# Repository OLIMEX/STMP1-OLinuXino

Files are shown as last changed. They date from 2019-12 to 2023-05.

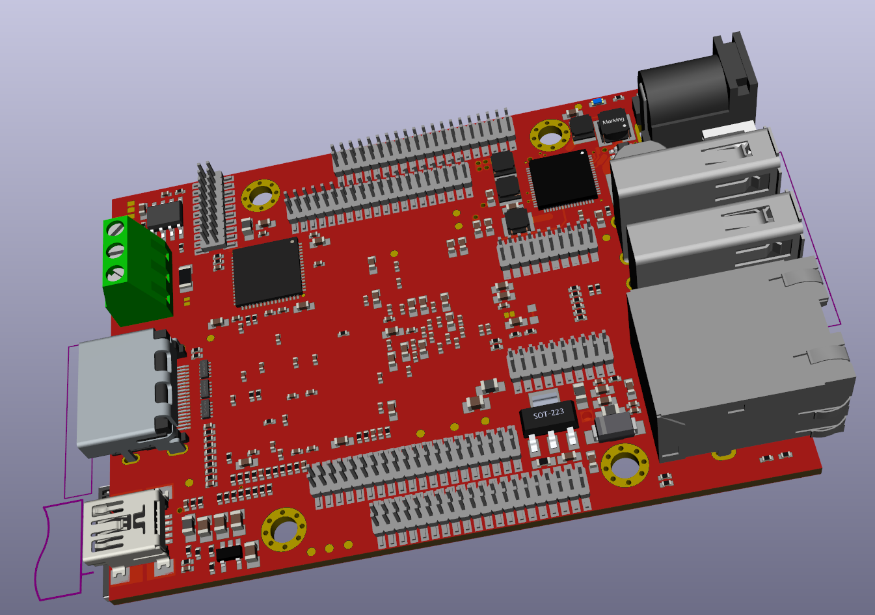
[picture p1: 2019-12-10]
HARDWARE/Screenshot from 2019-12-10 08-06-22.png

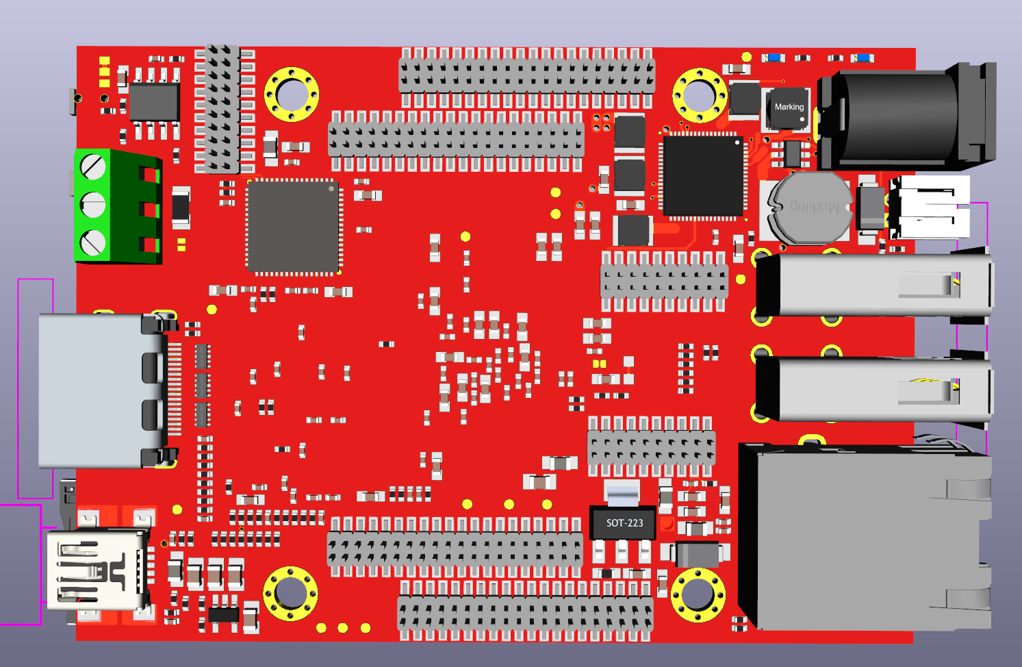
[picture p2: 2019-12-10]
HARDWARE/Screenshot from 2019-12-10 08-05-45.png

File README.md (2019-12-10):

# STMP1-OLinuXino

STMP1 (es-ti-em-pai) OLinuXino (o-linux-ino) is based on STM32MP1XX Dual Core Cortex-A7 + Cortex-M4 microprocessors from ST Microelectronics. The Cortex-A7 can run Linux/Android OS while Cortex-M4 handle Real-Time events.

Features are:

- mainline Linux support
- automotive -40+125C operating temperature on all devices!
- 1GB DDR3L
- Gigabit Ethernet interface
- Three USB 2.0
- Two FD-CAN
- Two ADC
- Two DAC
- Camera IF
- Six I2C
- Three I2S
- Three SD MMC
- FMC (NAND) Flash
- Six SPI
- Four UART
- MIPI DSI 3Gb (157 only)
- Secure Boot
- Crypto Hash (C version only)

STMP1-OLinuXino is designed in the same size and connector locations as A20-OLinuXino-LIME2 so being replacable and pin to pin compatible. 

STMP1-OLinuXino is manufactured in -40+125C operating temperature and targets industrial applications.

# License
- Hardware is with CERN OHL v1.2 license
- Software is with GPLv3 license
- Documentation is with CC BY-SA 4.0 license

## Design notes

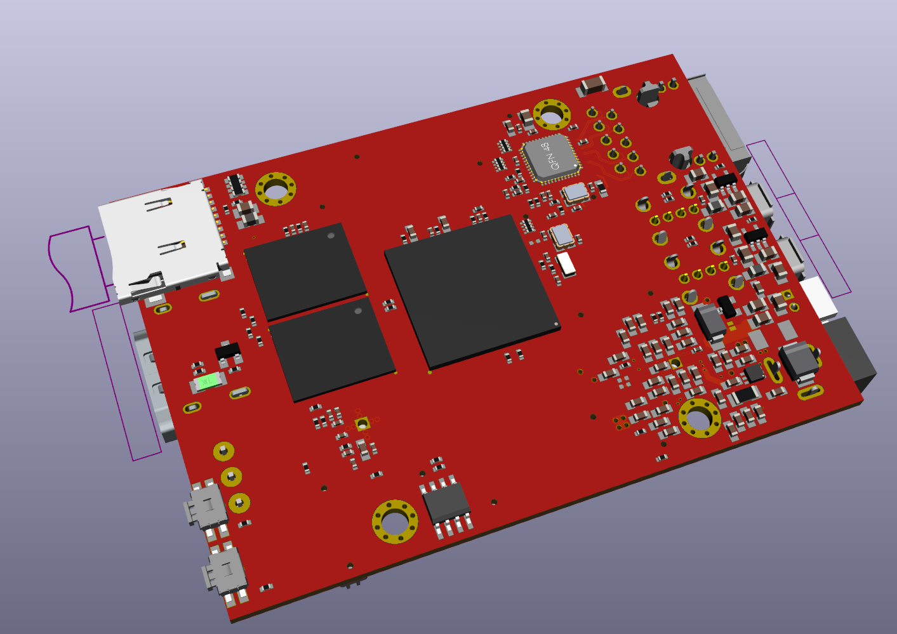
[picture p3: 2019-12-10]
HARDWARE/Screenshot from 2019-12-10 08-06-47.png

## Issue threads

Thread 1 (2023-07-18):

Track are not displayed (routed) in KiCad 5.1.12

hilt0n, 2023-07-18:
I open the project in KiCad 5.1.12 and the tracks are not there, only few on layer 1. Is the PCB normally completed routed ?

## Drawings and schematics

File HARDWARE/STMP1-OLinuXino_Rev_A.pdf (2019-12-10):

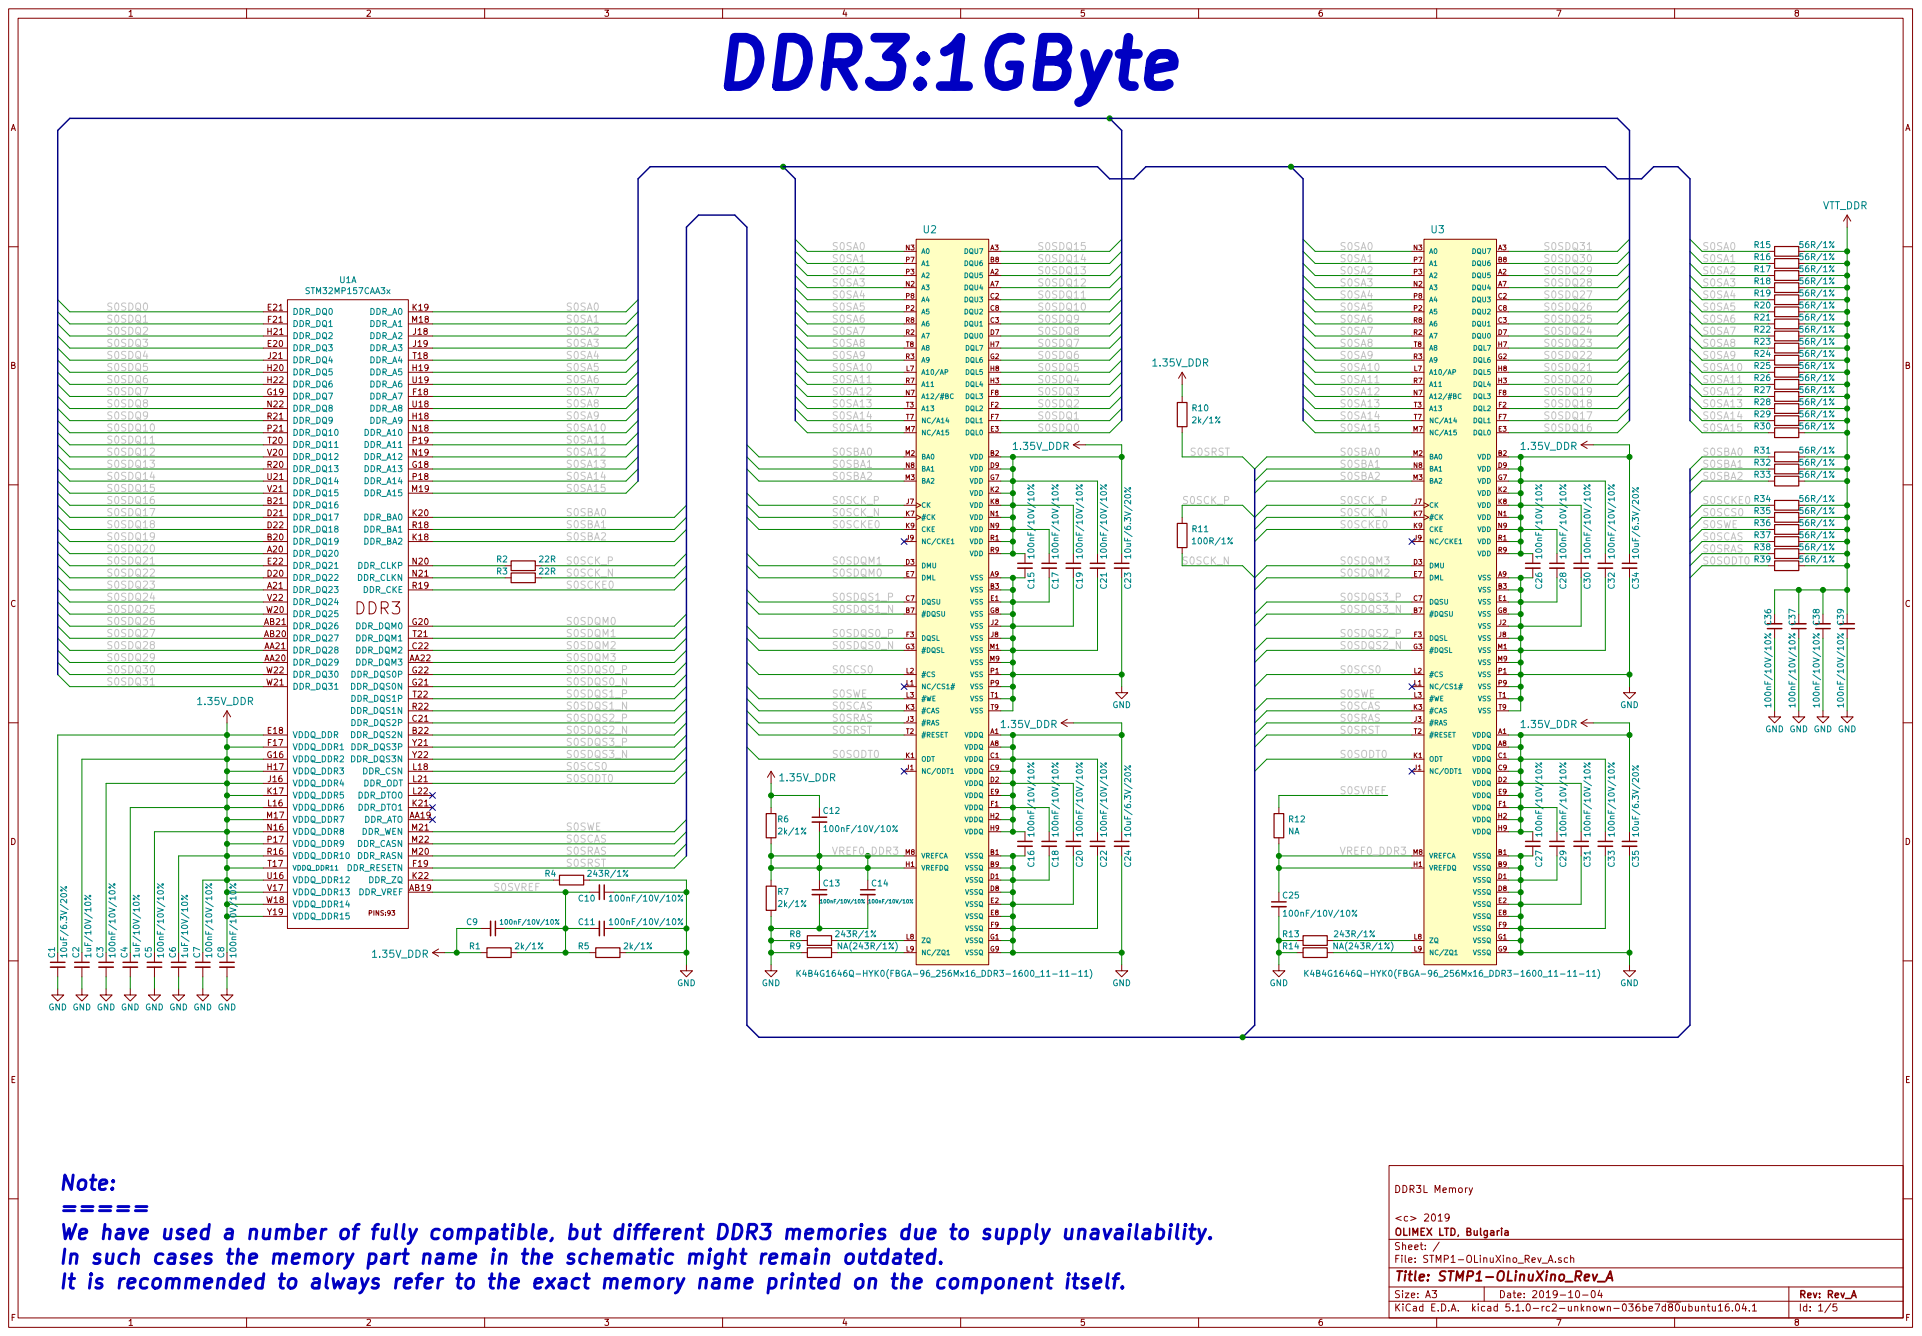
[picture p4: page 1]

GND GND

Note: ===== We have used a number of fully compatible, but different DDR3 memories due to supply unavailability.

In such cases the memory part name in the schematic might remain outdated.
It is recommended to always refer to the exact memory name printed on the component itself.

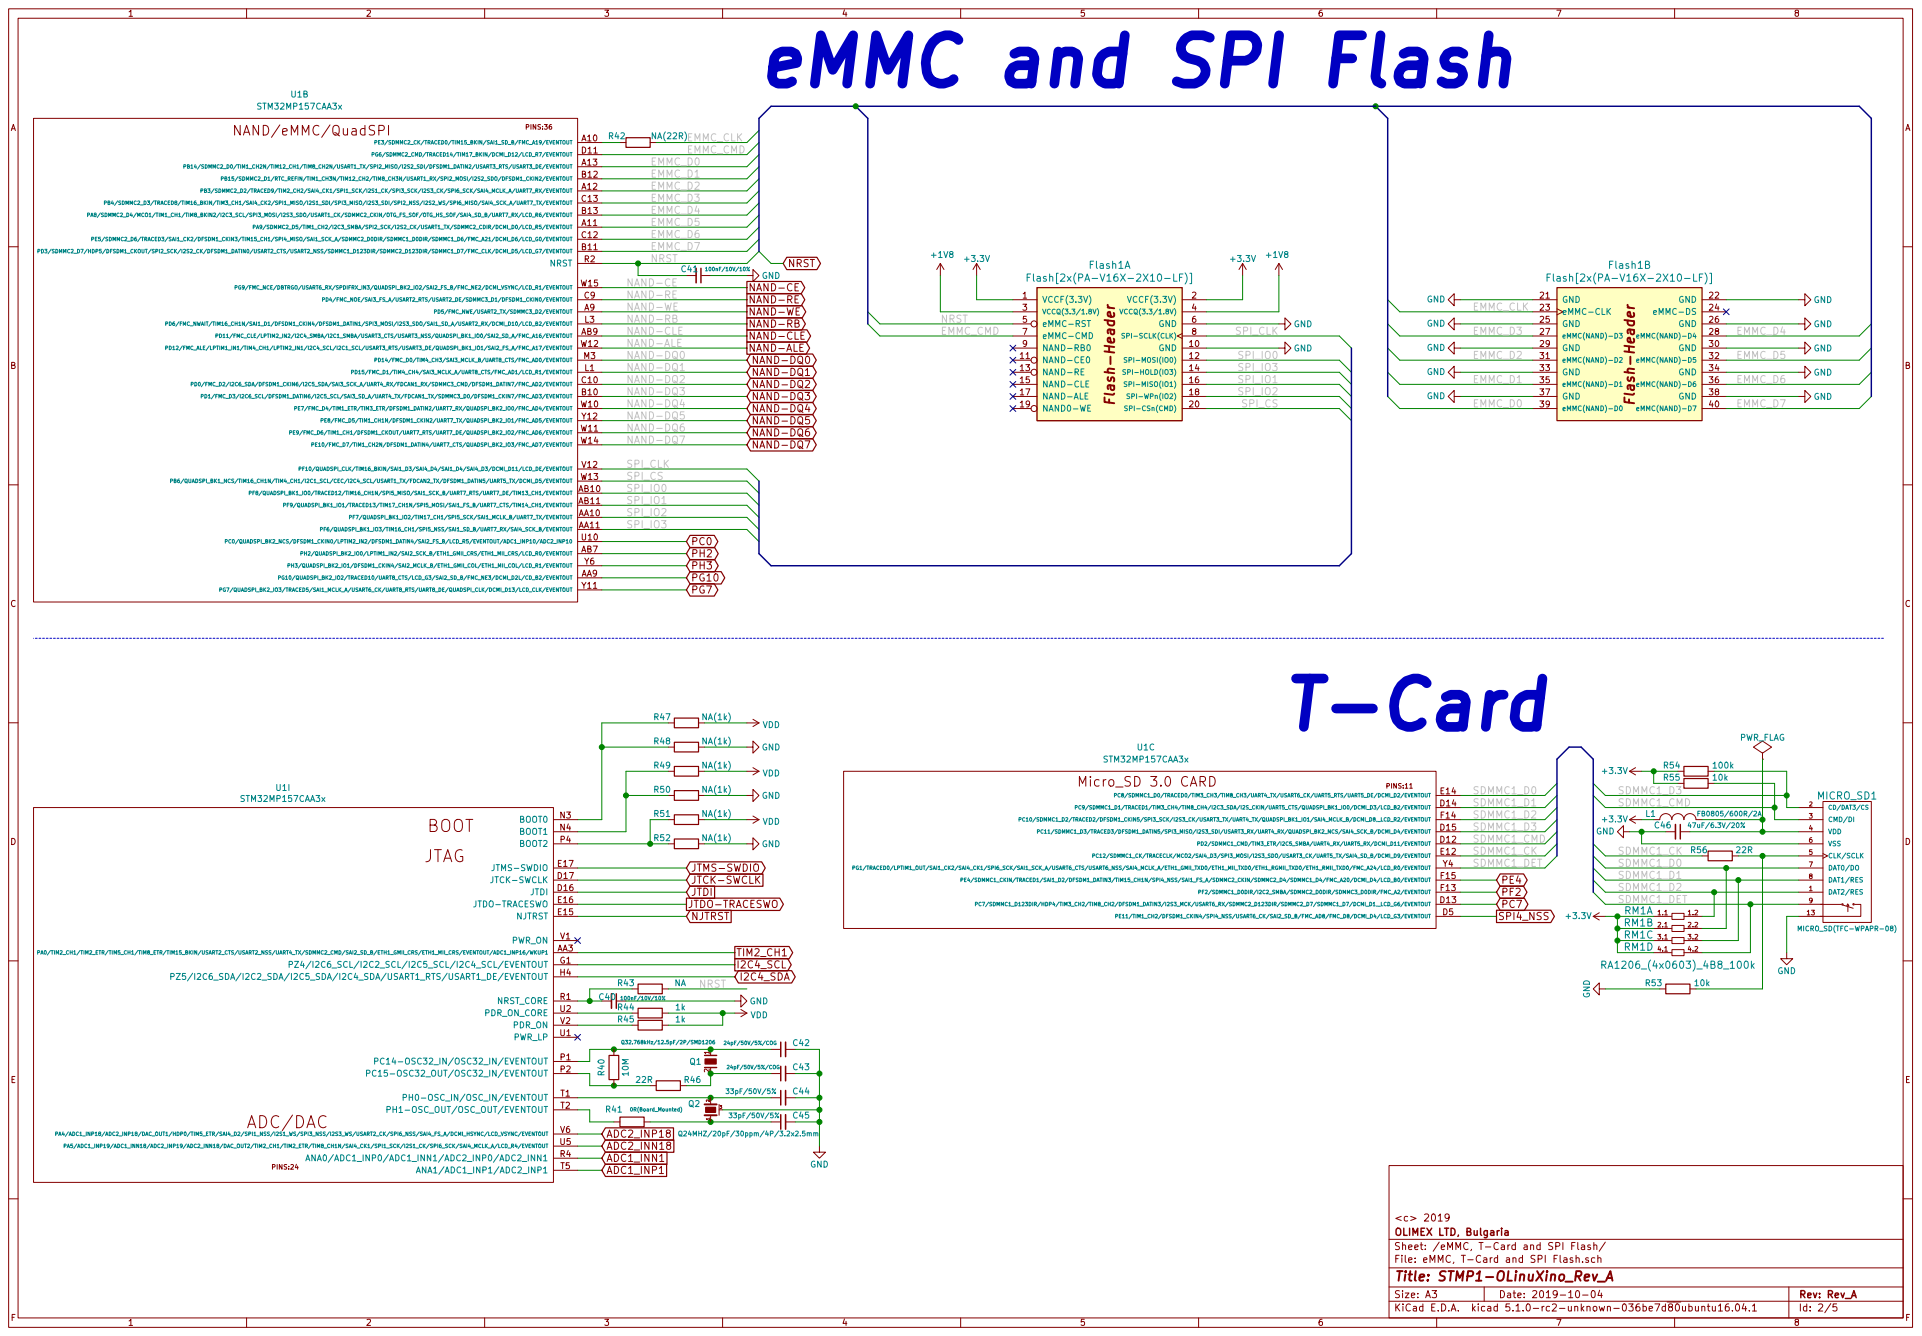
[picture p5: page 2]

NAND-CE
NAND-WE NAND-ALE NAND-CLE NAND-RE NAND-RB NAND-DQ0

NAND-CE NAND-RE NAND-WE NAND-RB NAND-CLE NAND-ALE NAND-DQ0

1 2 Q2 3 Q24MHZ/20pF/30ppm/4P/3.2x2.5mm R41 0R(Board_Mounted) Flash-Header GND 21 GND

Sheet: /eMMC, T-Card and SPI Flash/
File: eMMC, T-Card and SPI Flash.sch
Id: 2/5 Title: STMP1-OLinuXino_Rev_A

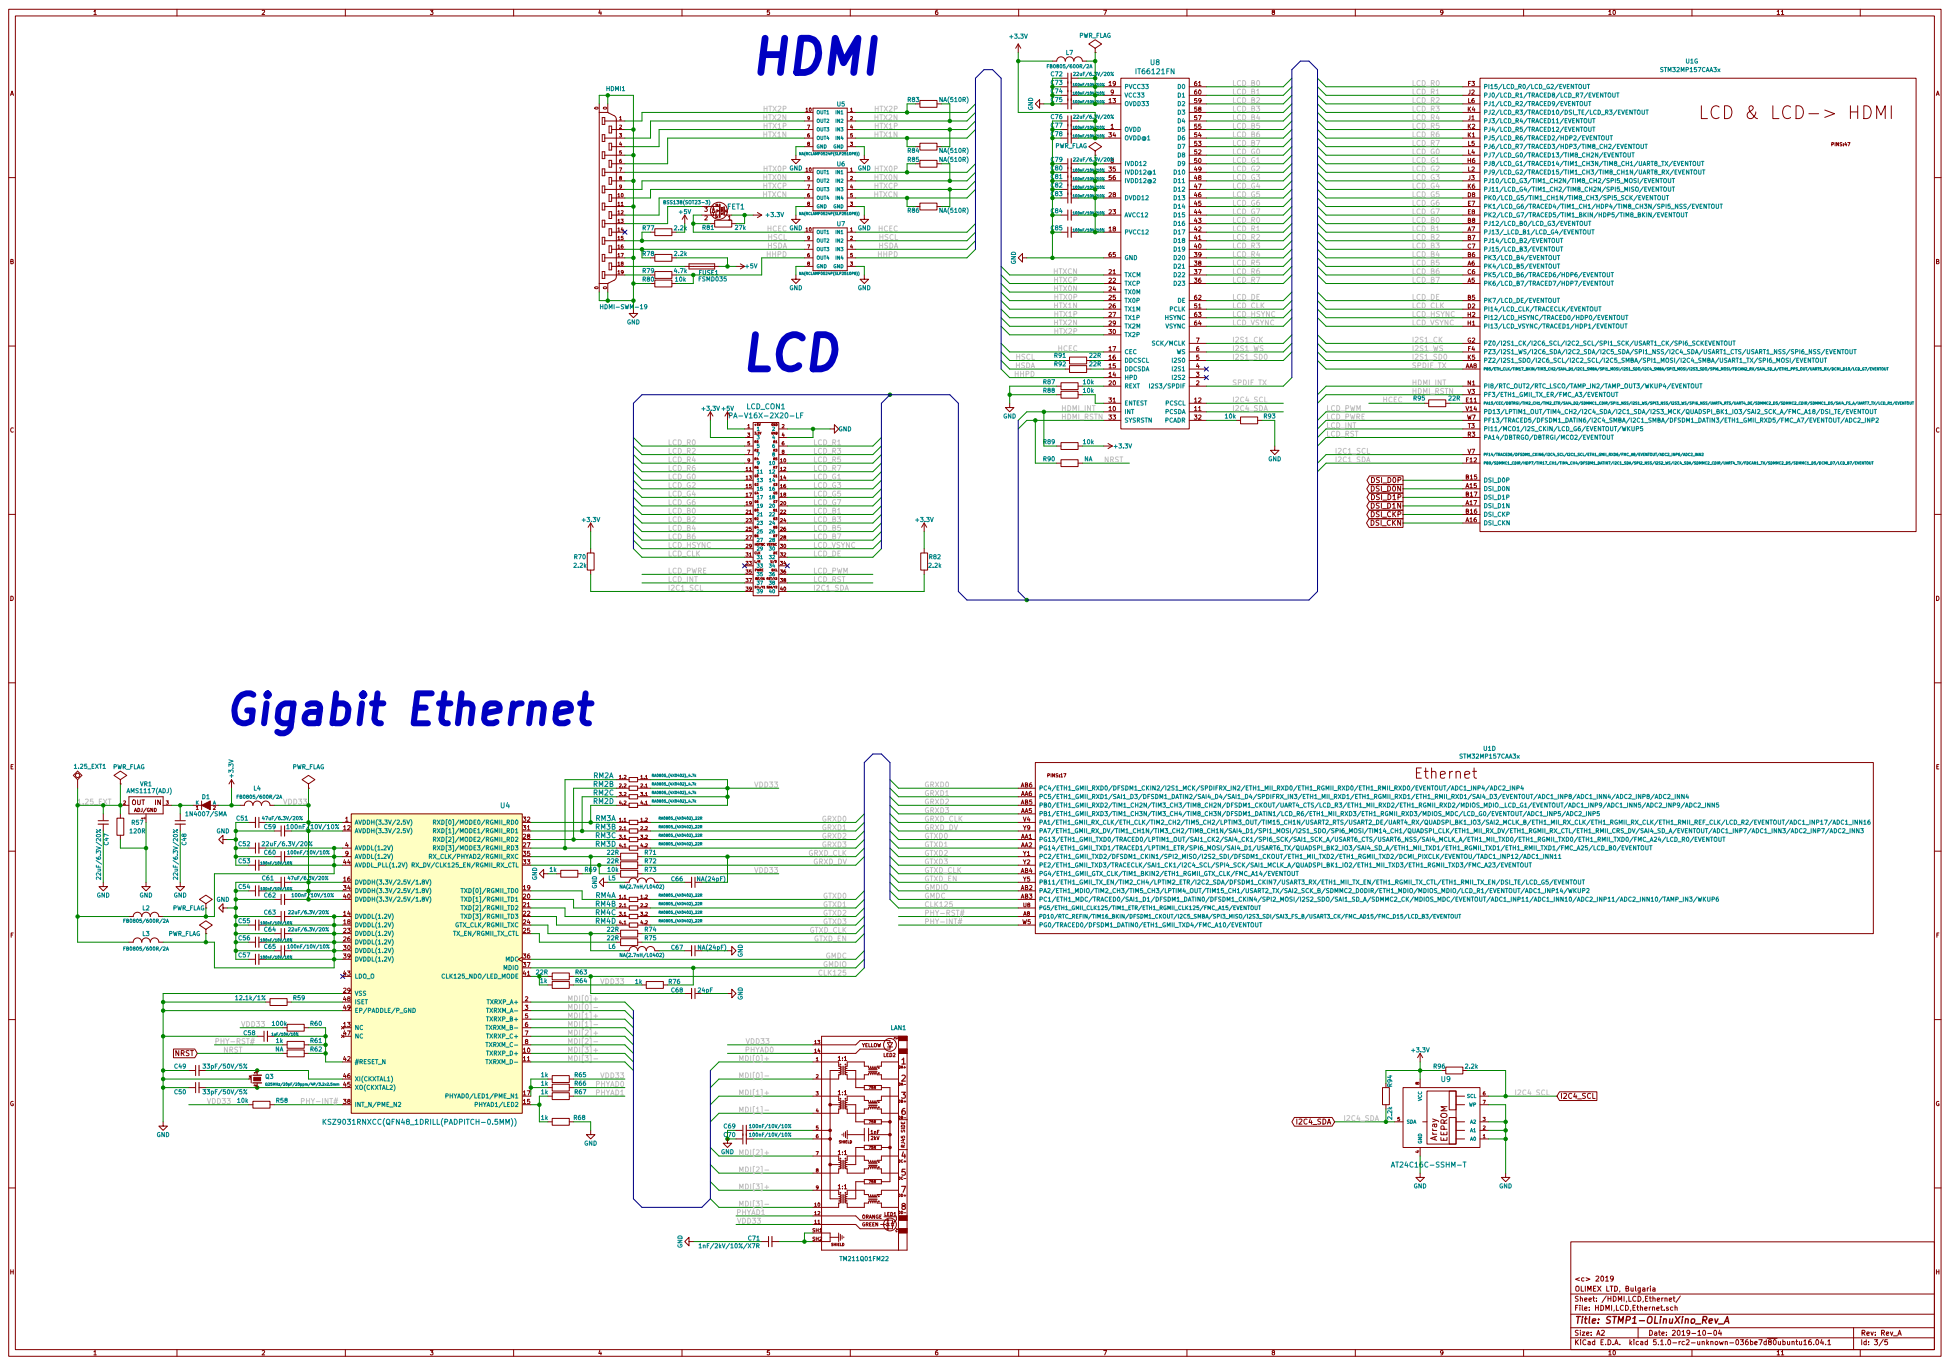
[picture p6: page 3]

OLIMEX LTD, Bulgaria <c> 2019 HDMI

HTXCP

10 | | HTXCN

PA15/CEC/DBTRGI/TIM2_CH1/TIM2_ETR/SAI4_D2/SDMMC1_CDIR/SPI1_NSS/I2S1_WS/SPI3_NSS/I2S3_WS/SPI6_NSS/UART4_RTS/UART4_DE/SDMMC2_D5/SDMMC2_CDIR/SDMMC1_D5/SAI4_FS_A/UART7_TX/LCD_R1/EVENTOUT E11 PK1/LCD_G6/TRACED4/TIM1_CH1/HDP4/TIM8_CH3N/SPI5_NSS/EVENTOUT E7 PK2/LCD_G7/TRACED5/TIM1_BKIN/HDP5/TIM8_BKIN/EVENTOUT E8

16
17

PHY-INT#

MDI[0]+ C71
DA+ DA- DB+ DB- DC+ DC- DD+ DD- GREEN

Sheet: /HDMI,LCD,Ethernet/
File: HDMI,LCD,Ethernet.sch
Id: 3/5 Title: STMP1-OLinuXino_Rev_A

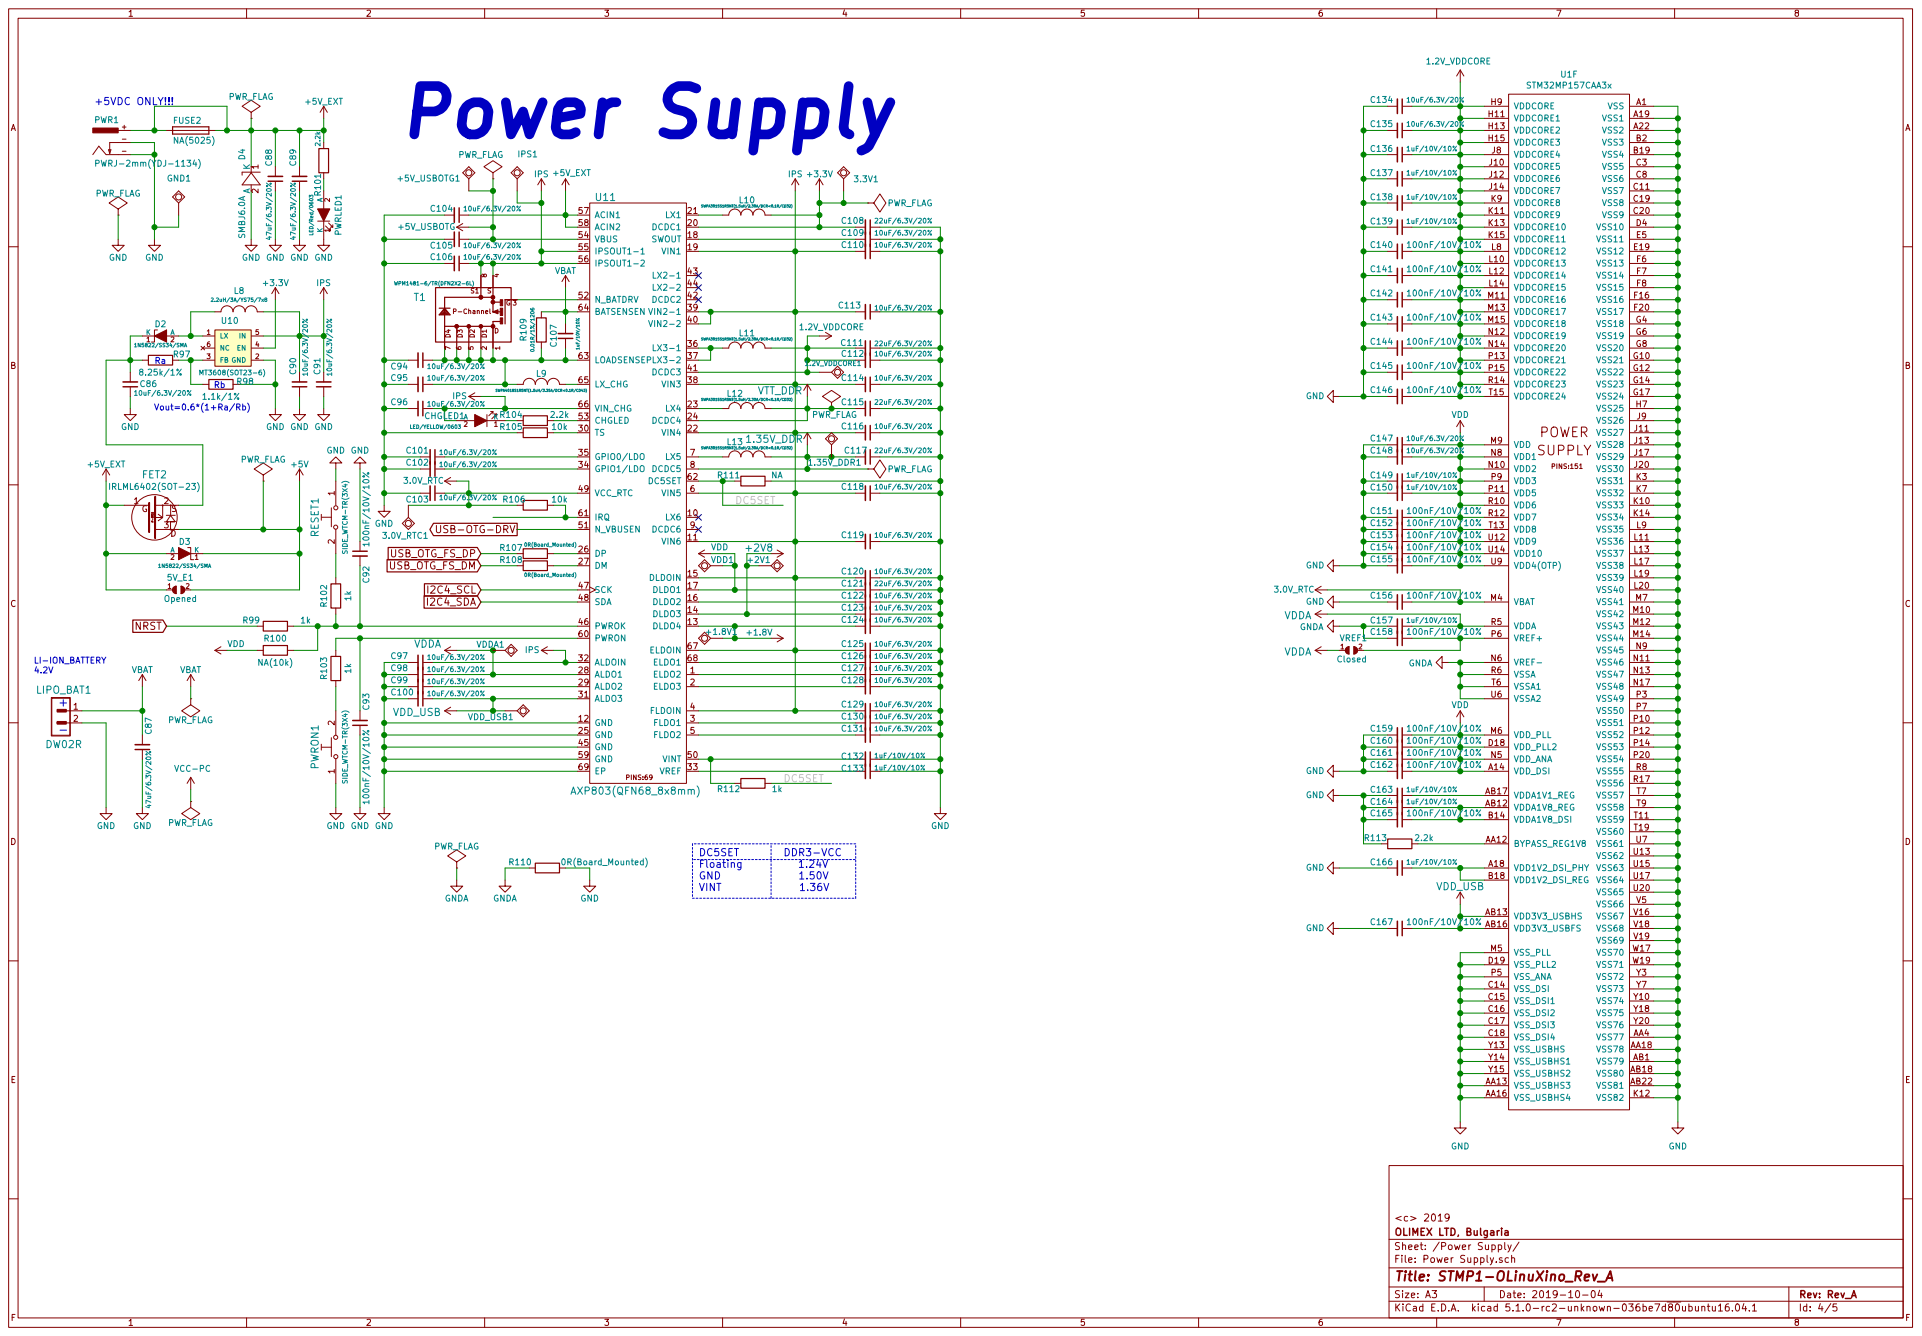
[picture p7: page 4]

OLIMEX LTD, Bulgaria <c> 2019 Power Supply

+5V_USBOTG
IPS GND
IPS USB-OTG-DRV

IPS GND GND GND GND

DC5SET | DDR3-VCC

GND 1.50V

Sheet: /Power Supply/
File: Power Supply.sch
Id: 4/5 Title: STMP1-OLinuXino_Rev_A

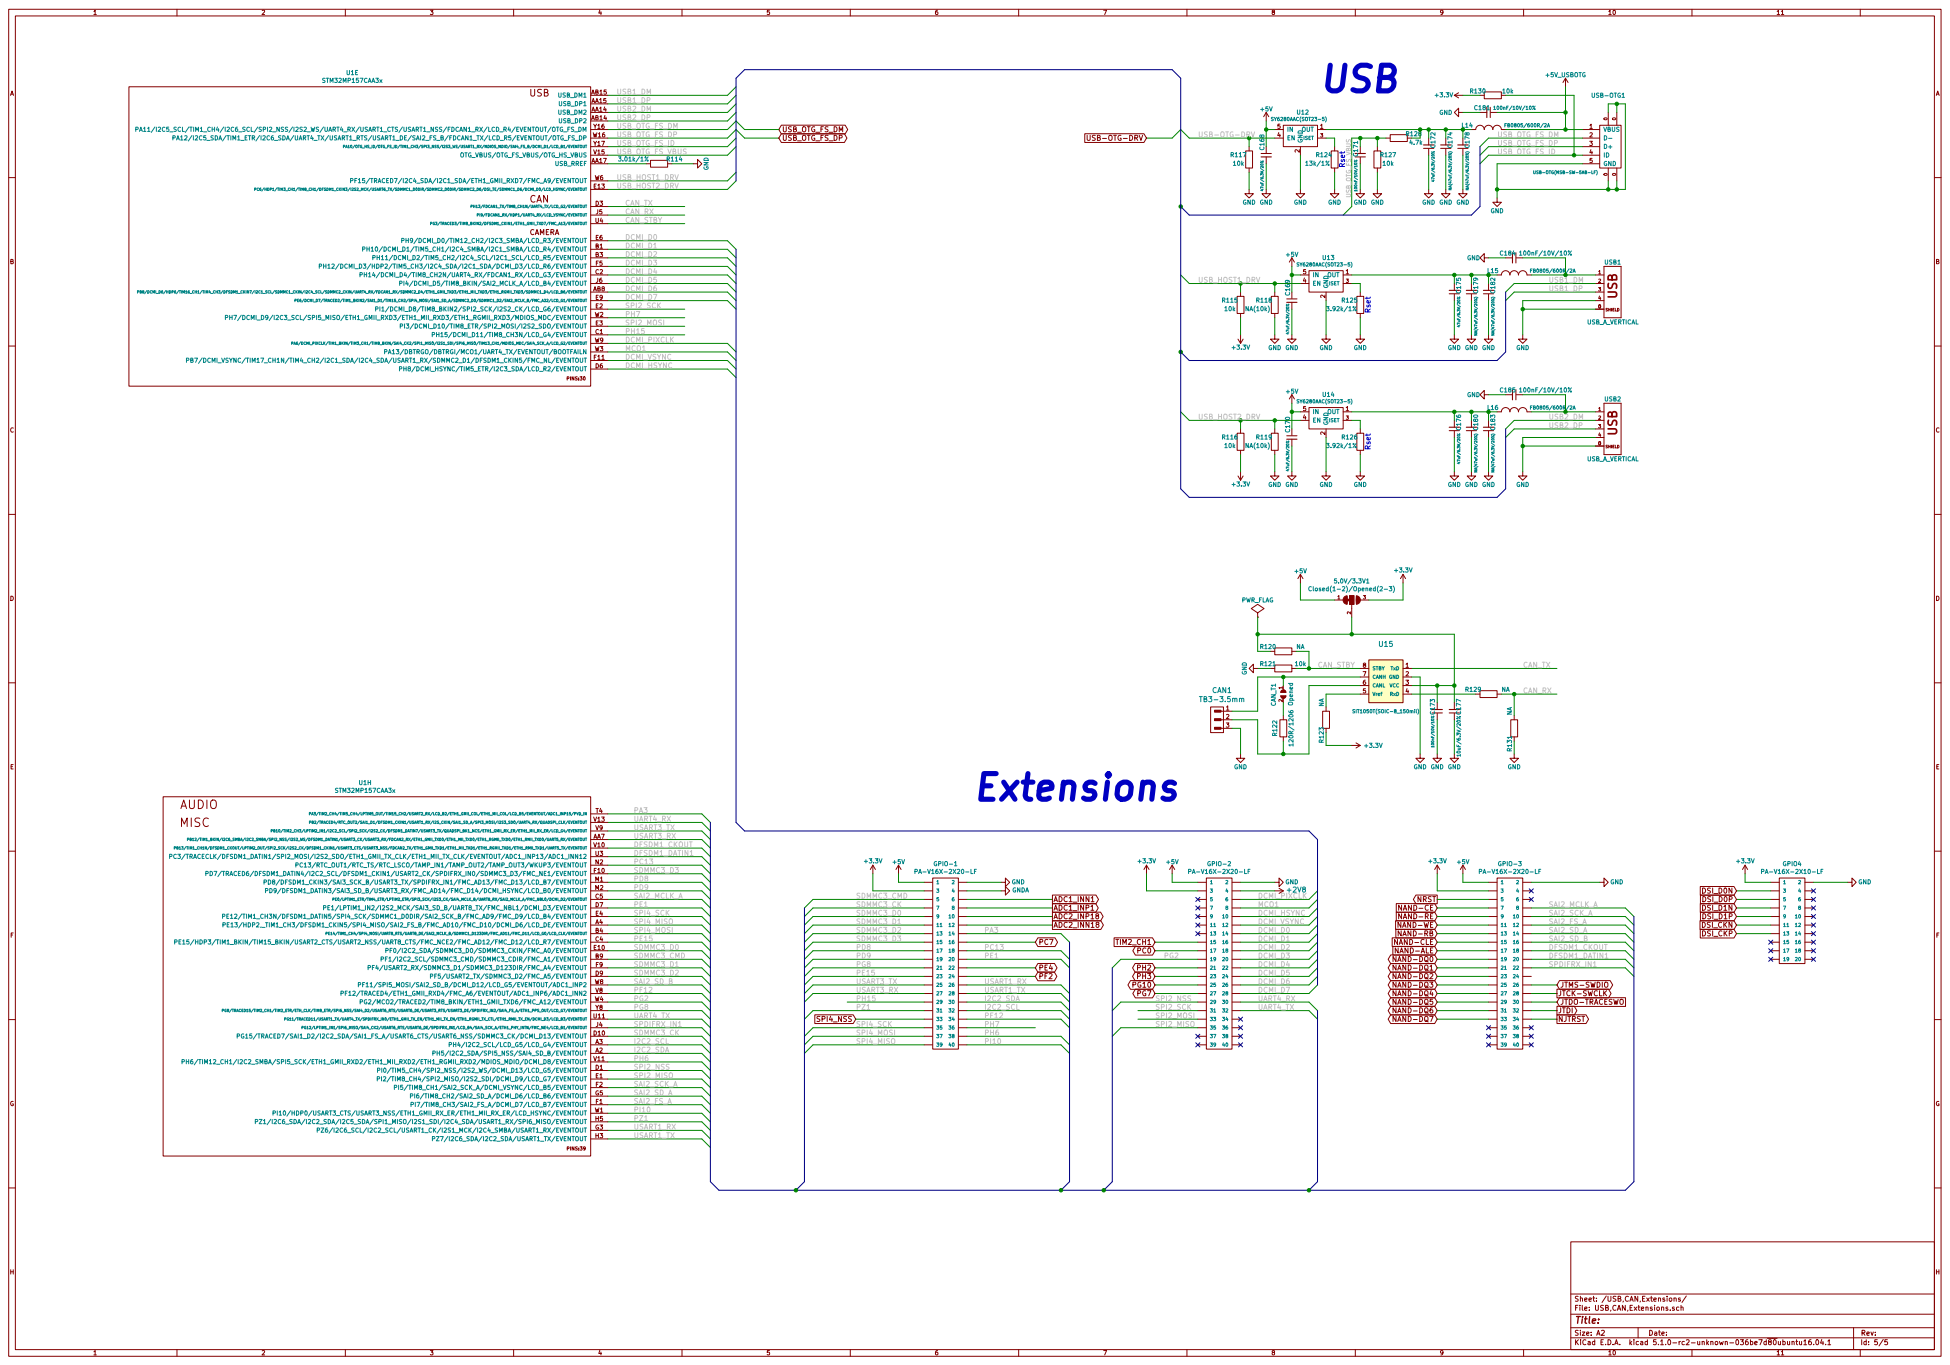
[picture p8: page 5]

Sheet: /USB,CAN,Extensions/
File: USB,CAN,Extensions.sch
Id: 5/5 Title:

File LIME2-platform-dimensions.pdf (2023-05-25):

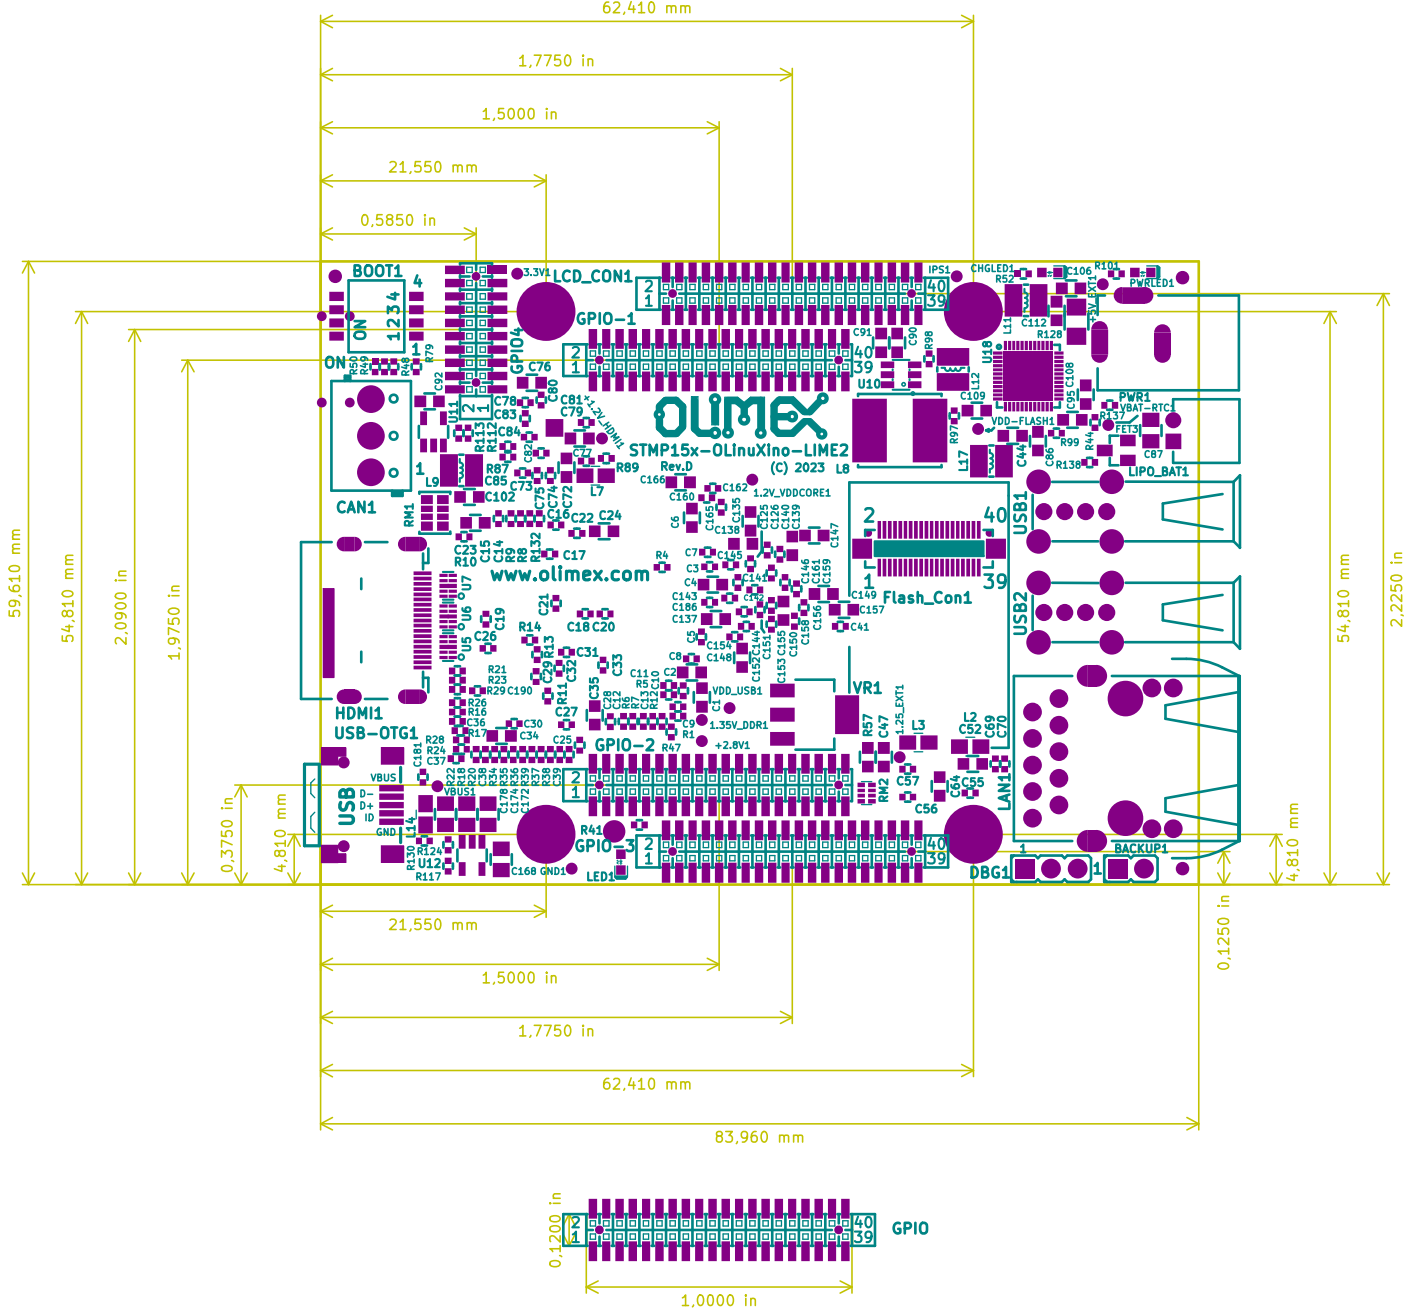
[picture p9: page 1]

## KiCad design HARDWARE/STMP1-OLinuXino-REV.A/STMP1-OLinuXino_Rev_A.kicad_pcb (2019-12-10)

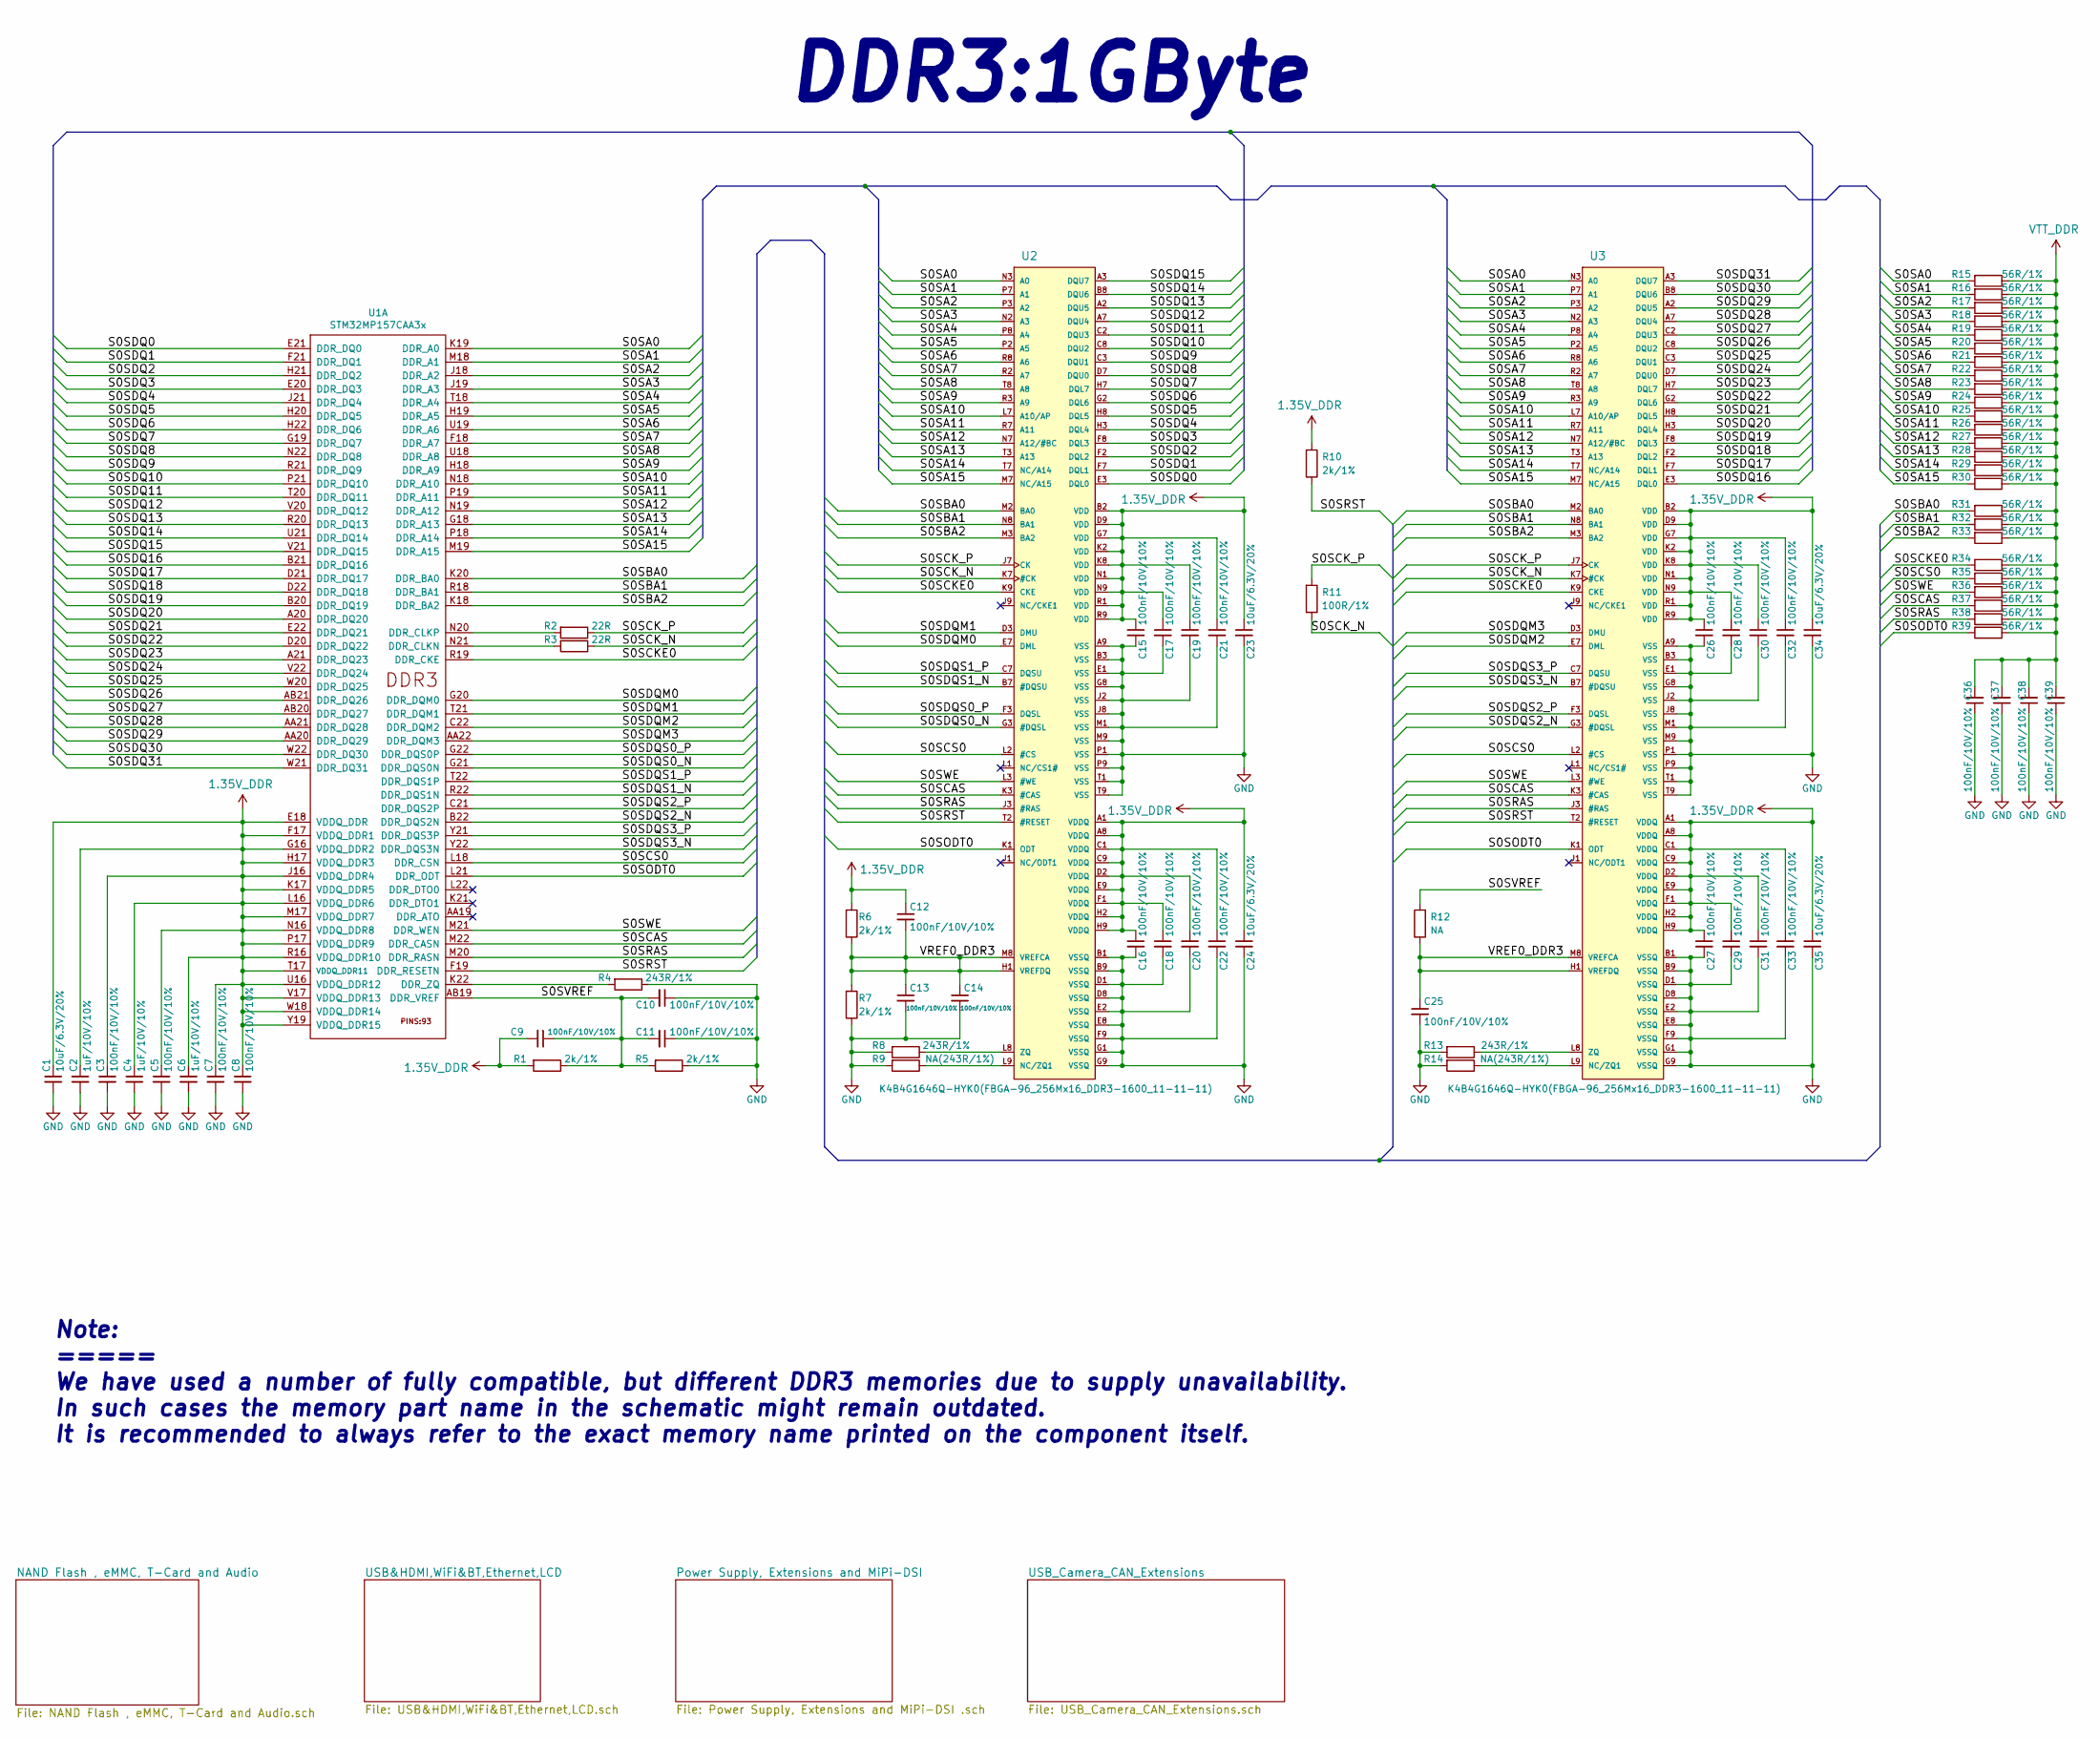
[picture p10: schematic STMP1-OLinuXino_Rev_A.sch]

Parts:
C1, C23, C24, C34, C35: 10uF/6.3V/20%; C_0603_5MIL_DWS
C2, C4, C6: 1uF/10V/10%; C_0603_5MIL_DWS
C3, C5, C7, C8, C9, C10, C11, C12, C13, C14, C15, C16, C17, C18, C19, C20, C21, C22, C25, C26, C27, C28, C29, C30, C31, C32, C33, C36, C37, C38, C39: 100nF/10V/10%; C_0402_5MIL_DWS
R1, R5, R6, R7, R10: 2k/1%; R_0402_5MIL_DWS
R2, R3: 22R; R_0402_5MIL_DWS
R4, R8, R13: 243R/1%; R_0402_5MIL_DWS
R9, R14: NA(243R/1%); R_0402_5MIL_DWS
R11: 100R/1%; R_0402_5MIL_DWS
R12: NA; R_0402_5MIL_DWS
R15, R16, R17, R18, R19, R20, R21, R22, R23, R24, R25, R26, R27, R28, R29, R30, R31, R32, R33, R34, R35, R36, R37, R38, R39: 56R/1%; R_0402_5MIL_DWS
U1: STM32MP157CAA3x; LFBGA-448(Pitch-0.8mm_Pad-0.4mm_18x18x1.27mm)
U2, U3: K4B4G1646Q-HYK0(FBGA-96_256Mx16_DDR3-1600_11-11-1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; FBGA96(HYNIX_SAMSUNG_512MX16_DDR3)

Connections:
1.35V_DDR: C1.1, C2.1, C3.1, C4.1, C5.1, C6.1, C7.1, C8.1, C9.2, C12.1, C15.1, C16.1, C17.1, C18.1, C19.1, C20.1, C21.1, C22.1, C23.1, C24.1, C26.1, C27.1, C28.1, C29.1, C30.1, C31.1, C32.1, C33.1, C34.1, C35.1, R1.2, R6.2, R10.2, U1.E18 (VDDQ_DDR), U1.F17 (VDDQ_DDR1), U1.G16 (VDDQ_DDR2), U1.H17 (VDDQ_DDR3), U1.J16 (VDDQ_DDR4), U1.K17 (VDDQ_DDR5), U1.L16 (VDDQ_DDR6), U1.M17 (VDDQ_DDR7), U1.N16 (VDDQ_DDR8), U1.P17 (VDDQ_DDR9), U1.R16 (VDDQ_DDR10), U1.T17 (VDDQ_DDR11), U1.U16 (VDDQ_DDR12), U1.V17 (VDDQ_DDR13), U1.W18 (VDDQ_DDR14), U1.Y19 (VDDQ_DDR15), U2.A1 (VDDQ), U2.A8 (VDDQ), U2.B2 (VDD), U2.C1 (VDDQ), U2.C9 (VDDQ), U2.D2 (VDDQ), U2.D9 (VDD), U2.E9 (VDDQ), U2.F1 (VDDQ), U2.G7 (VDD), U2.H2 (VDDQ), U2.H9 (VDDQ), U2.K2 (VDD), U2.K8 (VDD), U2.N1 (VDD), U2.N9 (VDD), U2.R1 (VDD), U2.R9 (VDD), U3.A1 (VDDQ), U3.A8 (VDDQ), U3.B2 (VDD), U3.C1 (VDDQ), U3.C9 (VDDQ), U3.D2 (VDDQ), U3.D9 (VDD), U3.E9 (VDDQ), U3.F1 (VDDQ), U3.G7 (VDD), U3.H2 (VDDQ), U3.H9 (VDDQ), U3.K2 (VDD), U3.K8 (VDD), U3.N1 (VDD), U3.N9 (VDD), U3.R1 (VDD), U3.R9 (VDD); also elsewhere on the board
/S0SA0: R15.2, U1.K19 (DDR_A0), U2.N3 (A0), U3.N3 (A0)
/S0SA1: R16.2, U1.M18 (DDR_A1), U2.P7 (A1), U3.P7 (A1)
/S0SA2: R17.2, U1.J18 (DDR_A2), U2.P3 (A2), U3.P3 (A2)
/S0SA3: R18.2, U1.J19 (DDR_A3), U2.N2 (A3), U3.N2 (A3)
/S0SA4: R19.2, U1.T18 (DDR_A4), U2.P8 (A4), U3.P8 (A4)
/S0SA5: R20.2, U1.H19 (DDR_A5), U2.P2 (A5), U3.P2 (A5)
/S0SA6: R21.2, U1.U19 (DDR_A6), U2.R8 (A6), U3.R8 (A6)
/S0SA7: R22.2, U1.F18 (DDR_A7), U2.R2 (A7), U3.R2 (A7)
/S0SA8: R23.2, U1.U18 (DDR_A8), U2.T8 (A8), U3.T8 (A8)
/S0SA9: R24.2, U1.H18 (DDR_A9), U2.R3 (A9), U3.R3 (A9)
/S0SA10: R25.2, U1.N18 (DDR_A10), U2.L7 (A10/AP), U3.L7 (A10/AP)
/S0SA11: R26.2, U1.P19 (DDR_A11), U2.R7 (A11), U3.R7 (A11)
/S0SA12: R27.2, U1.N19 (DDR_A12), U2.N7 (A12/#BC), U3.N7 (A12/#BC)
/S0SA13: R28.2, U1.G18 (DDR_A13), U2.T3 (A13), U3.T3 (A13)
/S0SA14: R29.2, U1.P18 (DDR_A14), U2.T7 (NC/A14), U3.T7 (NC/A14)
/S0SA15: R30.2, U1.M19 (DDR_A15), U2.M7 (NC/A15), U3.M7 (NC/A15)
/S0SBA0: R31.2, U1.K20 (DDR_BA0), U2.M2 (BA0), U3.M2 (BA0)
/S0SBA1: R32.2, U1.R18 (DDR_BA1), U2.N8 (BA1), U3.N8 (BA1)
/S0SBA2: R33.2, U1.K18 (DDR_BA2), U2.M3 (BA2), U3.M3 (BA2)
/S0SCAS: R37.2, U1.M22 (DDR_CASN), U2.K3 (#CAS), U3.K3 (#CAS)
/S0SCKE0: R34.2, U1.R19 (DDR_CKE), U2.K9 (CKE), U3.K9 (CKE)
/S0SCK_N: R3.1, R11.1, U2.K7 (#CK), U3.K7 (#CK)
/S0SCK_P: R2.1, R11.2, U2.J7 (CK), U3.J7 (CK)
/S0SCS0: R35.2, U1.L18 (DDR_CSN), U2.L2 (#CS), U3.L2 (#CS)
/S0SDQ0: U1.E21 (DDR_DQ0), U2.E3 (DQL0)
/S0SDQ1: U1.F21 (DDR_DQ1), U2.F7 (DQL1)
/S0SDQ2: U1.H21 (DDR_DQ2), U2.F2 (DQL2)
/S0SDQ3: U1.E20 (DDR_DQ3), U2.F8 (DQL3)
/S0SDQ4: U1.J21 (DDR_DQ4), U2.H3 (DQL4)
/S0SDQ5: U1.H20 (DDR_DQ5), U2.H8 (DQL5)
/S0SDQ6: U1.H22 (DDR_DQ6), U2.G2 (DQL6)
/S0SDQ7: U1.G19 (DDR_DQ7), U2.H7 (DQL7)
/S0SDQ8: U1.N22 (DDR_DQ8), U2.D7 (DQU0)
/S0SDQ9: U1.R21 (DDR_DQ9), U2.C3 (DQU1)
/S0SDQ10: U1.P21 (DDR_DQ10), U2.C8 (DQU2)
/S0SDQ11: U1.T20 (DDR_DQ11), U2.C2 (DQU3)
/S0SDQ12: U1.V20 (DDR_DQ12), U2.A7 (DQU4)
/S0SDQ13: U1.R20 (DDR_DQ13), U2.A2 (DQU5)
/S0SDQ14: U1.U21 (DDR_DQ14), U2.B8 (DQU6)
/S0SDQ15: U1.V21 (DDR_DQ15), U2.A3 (DQU7)
/S0SDQ16: U1.B21 (DDR_DQ16), U3.E3 (DQL0)
/S0SDQ17: U1.D21 (DDR_DQ17), U3.F7 (DQL1)
/S0SDQ18: U1.D22 (DDR_DQ18), U3.F2 (DQL2)
/S0SDQ19: U1.B20 (DDR_DQ19), U3.F8 (DQL3)
/S0SDQ20: U1.A20 (DDR_DQ20), U3.H3 (DQL4)
/S0SDQ21: U1.E22 (DDR_DQ21), U3.H8 (DQL5)
/S0SDQ22: U1.D20 (DDR_DQ22), U3.G2 (DQL6)
/S0SDQ23: U1.A21 (DDR_DQ23), U3.H7 (DQL7)
/S0SDQ24: U1.V22 (DDR_DQ24), U3.D7 (DQU0)
/S0SDQ25: U1.W20 (DDR_DQ25), U3.C3 (DQU1)
/S0SDQ26: U1.AB21 (DDR_DQ26), U3.C8 (DQU2)
/S0SDQ27: U1.AB20 (DDR_DQ27), U3.C2 (DQU3)
/S0SDQ28: U1.AA21 (DDR_DQ28), U3.A7 (DQU4)
/S0SDQ29: U1.AA20 (DDR_DQ29), U3.A2 (DQU5)
/S0SDQ30: U1.W22 (DDR_DQ30), U3.B8 (DQU6)
/S0SDQ31: U1.W21 (DDR_DQ31), U3.A3 (DQU7)
/S0SDQM0: U1.G20 (DDR_DQM0), U2.E7 (DML)
/S0SDQM1: U1.T21 (DDR_DQM1), U2.D3 (DMU)
/S0SDQM2: U1.C22 (DDR_DQM2), U3.E7 (DML)
/S0SDQM3: U1.AA22 (DDR_DQM3), U3.D3 (DMU)
/S0SDQS0_N: U1.G21 (DDR_DQS0N), U2.G3 (#DQSL)
/S0SDQS0_P: U1.G22 (DDR_DQS0P), U2.F3 (DQSL)
/S0SDQS1_N: U1.R22 (DDR_DQS1N), U2.B7 (#DQSU)
/S0SDQS1_P: U1.T22 (DDR_DQS1P), U2.C7 (DQSU)
/S0SDQS2_N: U1.B22 (DDR_DQS2N), U3.G3 (#DQSL)
/S0SDQS2_P: U1.C21 (DDR_DQS2P), U3.F3 (DQSL)
/S0SDQS3_N: U1.Y22 (DDR_DQS3N), U3.B7 (#DQSU)
/S0SDQS3_P: U1.Y21 (DDR_DQS3P), U3.C7 (DQSU)
/S0SODT0: R39.2, U1.L21 (DDR_ODT), U2.K1 (ODT), U3.K1 (ODT)
/S0SRAS: R38.2, U1.M20 (DDR_RASN), U2.J3 (#RAS), U3.J3 (#RAS)
/S0SRST: R10.1, U1.F19 (DDR_RESETN), U2.T2 (#RESET), U3.T2 (#RESET)
/S0SVREF: C9.1, C10.2, C11.2, R1.1, R5.2, R12.2, U1.AB19 (DDR_VREF)
/S0SWE: R36.2, U1.M21 (DDR_WEN), U2.L3 (#WE), U3.L3 (#WE)
/VREF0_DDR3: C12.2, C13.1, C14.1, C25.1, R6.1, R7.2, R12.1, U2.H1 (VREFDQ), U2.M8 (VREFCA), U3.H1 (VREFDQ), U3.M8 (VREFCA)
GND: C1.2, C2.2, C3.2, C4.2, C5.2, C6.2, C7.2, C8.2, C10.1, C11.1, C13.2, C14.2, C15.2, C16.2, C17.2, C18.2, C19.2, C20.2, C21.2, C22.2, C23.2, C24.2, C25.2, C26.2, C27.2, C28.2, C29.2, C30.2, C31.2, C32.2, C33.2, C34.2, C35.2, C36.1, C37.1, C38.1, C39.1, R4.1, R5.1, R7.1, R8.2, R9.2, R13.2, R14.2, U2.A9 (VSS), U2.B1 (VSSQ), U2.B3 (VSS), U2.B9 (VSSQ), U2.D1 (VSSQ), U2.D8 (VSSQ), U2.E1 (VSS), U2.E2 (VSSQ), U2.E8 (VSSQ), U2.F9 (VSSQ), U2.G1 (VSSQ), U2.G8 (VSS), U2.G9 (VSSQ), U2.J2 (VSS), U2.J8 (VSS), U2.M1 (VSS), U2.M9 (VSS), U2.P1 (VSS), U2.P9 (VSS), U2.T1 (VSS), U2.T9 (VSS), U3.A9 (VSS), U3.B1 (VSSQ), U3.B3 (VSS), U3.B9 (VSSQ), U3.D1 (VSSQ), U3.D8 (VSSQ), U3.E1 (VSS), U3.E2 (VSSQ), U3.E8 (VSSQ), U3.F9 (VSSQ), U3.G1 (VSSQ), U3.G8 (VSS), U3.G9 (VSSQ), U3.J2 (VSS), U3.J8 (VSS), U3.M1 (VSS), U3.M9 (VSS), U3.P1 (VSS), U3.P9 (VSS), U3.T1 (VSS), U3.T9 (VSS); also elsewhere on the board
unnamed: R2.2, U1.N20 (DDR_CLKP)
unnamed: R3.2, U1.N21 (DDR_CLKN)
unnamed: R4.2, U1.K22 (DDR_ZQ)
unnamed: R8.1, U2.L8 (ZQ)
unnamed: R9.1, U2.L9 (NC/ZQ1)
unnamed: R13.1, U3.L8 (ZQ)
unnamed: R14.1, U3.L9 (NC/ZQ1)
VTT_DDR: C36.2, C37.2, C38.2, C39.2, R15.1, R16.1, R17.1, R18.1, R19.1, R20.1, R21.1, R22.1, R23.1, R24.1, R25.1, R26.1, R27.1, R28.1, R29.1, R30.1, R31.1, R32.1, R33.1, R34.1, R35.1, R36.1, R37.1, R38.1, R39.1; also elsewhere on the board

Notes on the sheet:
DDR3:1GByte
Note: ===== We have used a number of fully compatible, but different DDR3 memories due to supply unavailability. In such cases the memory part name in the schematic might remain outdated. It is recommended to always refer to the exact memory name printed on the component itself.

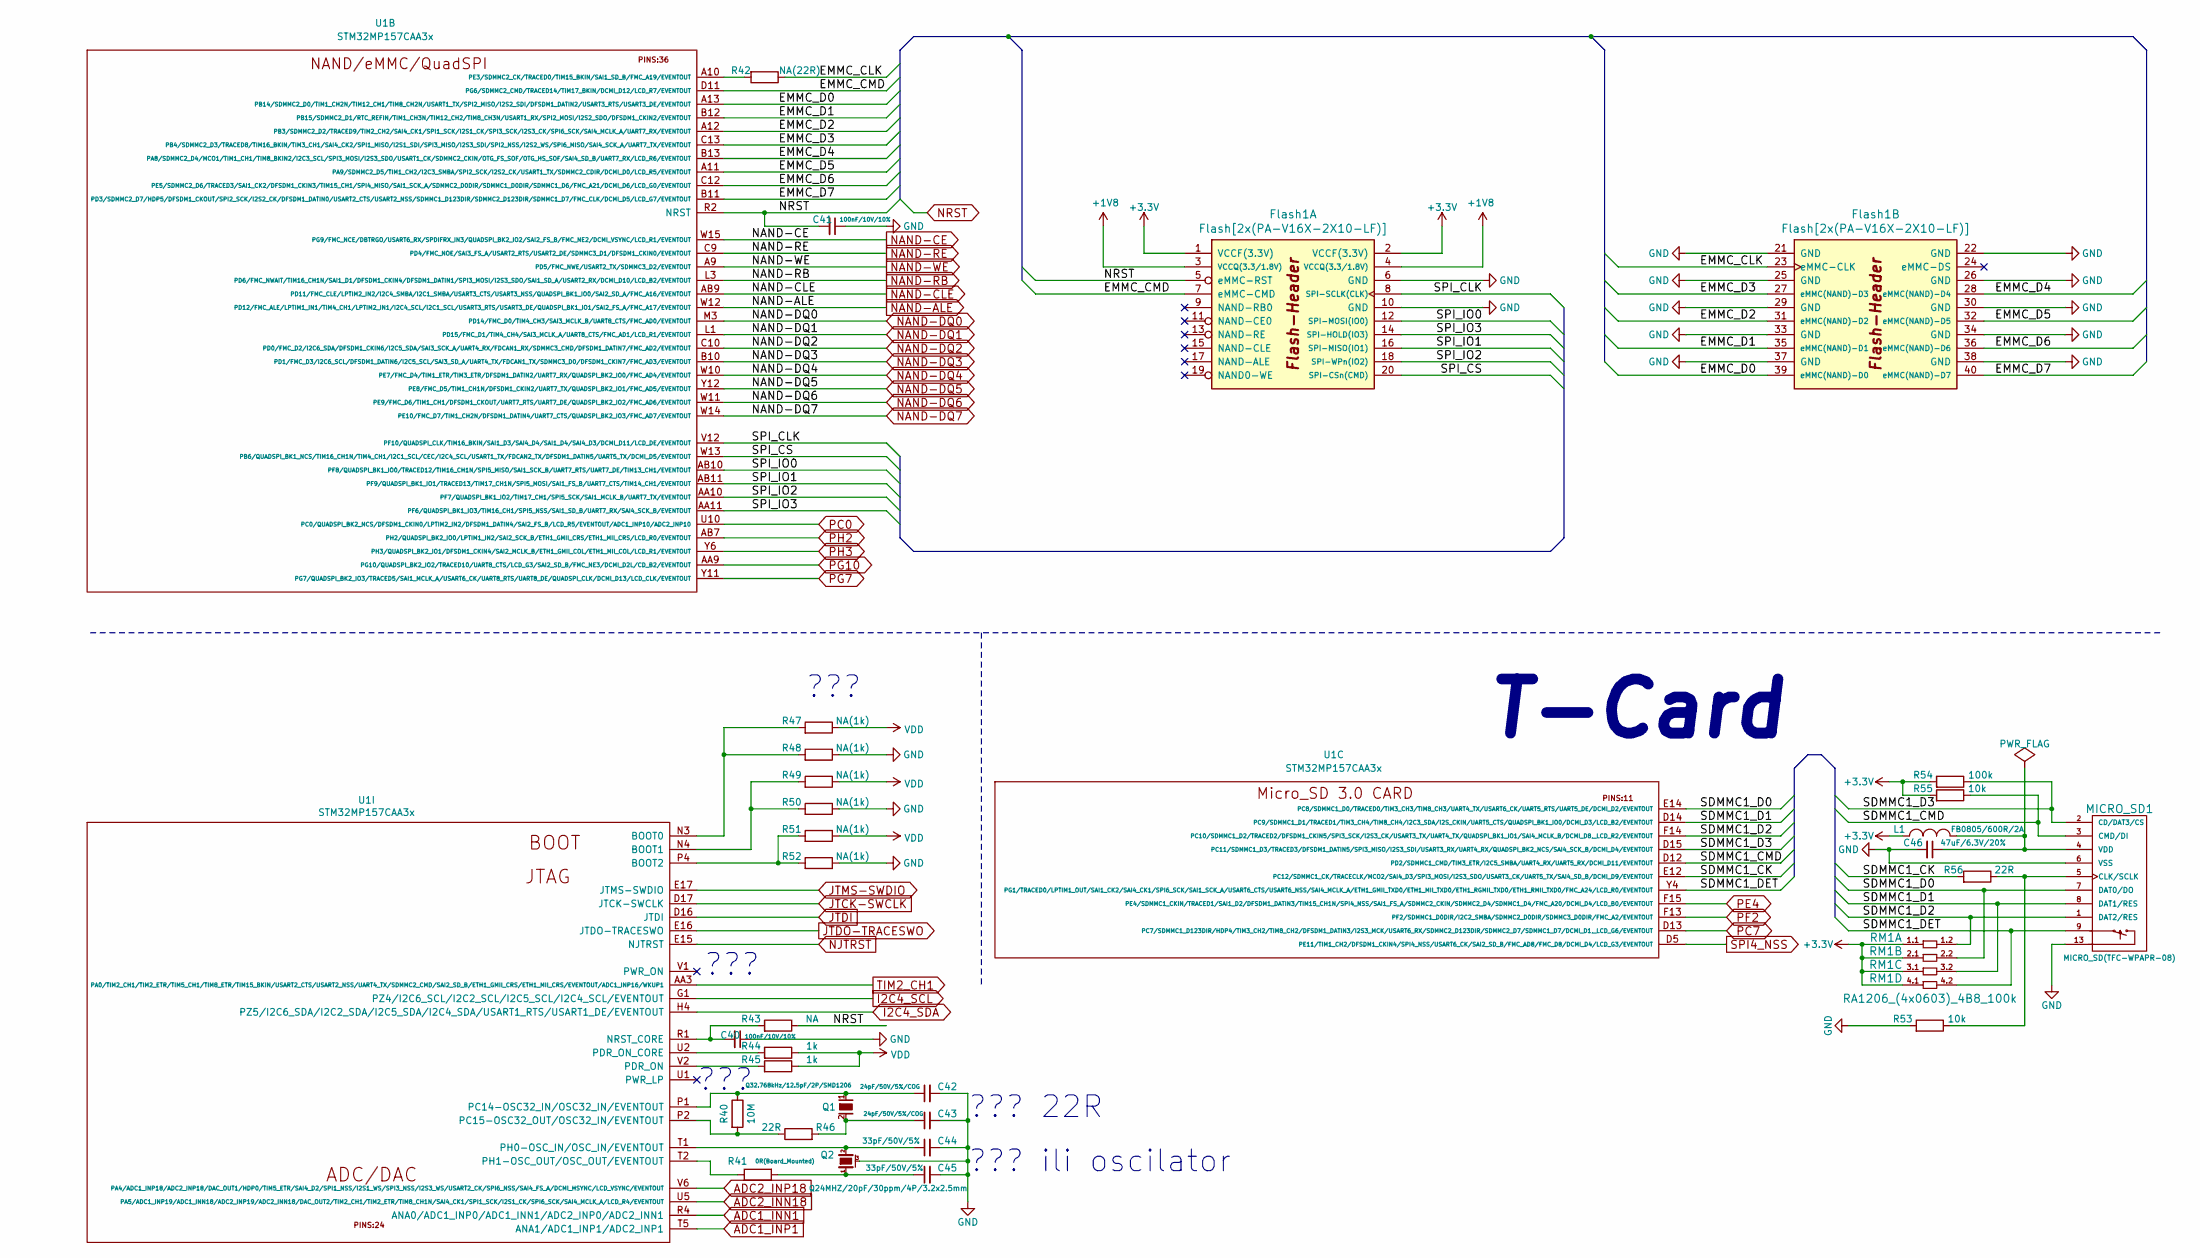
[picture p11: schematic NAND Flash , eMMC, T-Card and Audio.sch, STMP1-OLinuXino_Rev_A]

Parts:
C40, C41: 100nF/10V/10%; C_0402_5MIL_DWS
C42, C43: 24pF/50V/5%/COG; C_0402_5MIL_DWS
C44, C45: 33pF/50V/5%; C_0402_5MIL_DWS
C46: 47uF/6.3V/20%; C_0805_5MIL_DWS
Flash1: Flash[2x(PA-V16X-2X10-LF)]
L1: FB0805/600R/2A; L_0805_5MIL_DWS
MICRO_SD1: MICRO_SD(TFC-WPAPR-08); TFC-WPAPR-08
Q1: Q32.768kHz/12.5pF/2P/SMD1206; CM7V-T1A(Crystal_Package-1206_3.20x1.50x0.65mm)
Q2: Q24MHZ/20pF/30ppm/4P/3.2x2.5mm; TSX-3.2x2.5mm_GND(3)
R40: 10M; R_0402_5MIL_DWS
R41: 0R(Board_Mounted); R_0402_5MIL_0R(Board_Mounted)
R42: NA(22R); R_0402_5MIL_DWS
R43: NA; R_0402_5MIL_DWS
R44, R45: 1k; R_0402_5MIL_DWS
R46, R56: 22R; R_0402_5MIL_DWS
R47, R48, R49, R50, R51, R52: NA(1k); R_0402_5MIL_DWS
R53, R55: 10k; R_0402_5MIL_DWS
R54: 100k; R_0402_5MIL_DWS
RM1: RA1206_(4x0603)_4B8_100k; RA1206_(4X0603)_4B8_xx
U1: STM32MP157CAA3x; LFBGA-448(Pitch-0.8mm_Pad-0.4mm_18x18x1.27mm)

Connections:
+3V3: Flash1.1 (VCCF(3.3V)), Flash1.2 (VCCF(3.3V)), L1.1, R54.2, R55.2, RM1.1.1, RM1.2.1, RM1.3.1, RM1.4.1; also elsewhere on the board
/NAND Flash , eMMC, T-Card and Audio/EMMC_CLK: Flash1.23 (eMMC-CLK), R42.1
/NAND Flash , eMMC, T-Card and Audio/EMMC_CMD: Flash1.7 (eMMC-CMD), U1.D11 (PG6/SDMMC2_CMD/TRACED14/TIM17_BKIN/DCMI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)
/NAND Flash , eMMC, T-Card and Audio/EMMC_D0: Flash1.39 (eMMC(NAND)-D0), U1.A13 (PB14/SDMMC2_D0/TIM1_CH2N/TIM12_CH1/TIM8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)
/NAND Flash , eMMC, T-Card and Audio/EMMC_D1: Flash1.35 (eMMC(NAND)-D1), U1.B12 (PB15/SDMMC2_D1/RTC_REFIN/TIM1_CH3N/TIM1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)
/NAND Flash , eMMC, T-Card and Audio/EMMC_D2: Flash1.31 (eMMC(NAND)-D2), U1.A12 (PB3/SDMMC2_D2/TRACED9/TIM2_CH2/SAI4_CK1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)
/NAND Flash , eMMC, T-Card and Audio/EMMC_D3: Flash1.27 (eMMC(NAND)-D3), U1.C13 (PB4/SDMMC2_D3/TRACED8/TIM16_BKIN/TIM3_C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)
/NAND Flash , eMMC, T-Card and Audio/EMMC_D4: Flash1.28 (eMMC(NAND)-D4), U1.B13 (PA8/SDMMC2_D4/MCO1/TIM1_CH1/TIM8_BKIN2/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)
/NAND Flash , eMMC, T-Card and Audio/EMMC_D5: Flash1.32 (eMMC(NAND)-D5), U1.A11 (PA9/SDMMC2_D5/TIM1_CH2/I2C3_SMBA/SPI2_S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)
/NAND Flash , eMMC, T-Card and Audio/EMMC_D6: Flash1.36 (eMMC(NAND)-D6), U1.C12 (PE5/SDMMC2_D6/TRACED3/SAI1_CK2/DFSDM1_C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)
/NAND Flash , eMMC, T-Card and Audio/EMMC_D7: Flash1.40 (eMMC(NAND)-D7), U1.B11 (PD3/SDMMC2_D7/HDP5/DFSDM1_CKOUT/SPI2_SC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)
/NAND Flash , eMMC, T-Card and Audio/SDMMC1_CK: R56.2, U1.E12 (PC12/SDMMC1_CK/TRACECLK/MCO2/SAI4_D3/SP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)
/NAND Flash , eMMC, T-Card and Audio/SDMMC1_CMD: MICRO_SD1.3 (CMD/DI), R55.1, U1.D12 (PD2/SDMMC1_CMD/TIM3_ETR/I2C5_SMBA/UART4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)
/NAND Flash , eMMC, T-Card and Audio/SDMMC1_D0: MICRO_SD1.7 (DAT0/DO), RM1.2.2, U1.E14 (PC8/SDMMC1_D0/TRACED0/TIM3_CH3/TIM8_CH3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)
/NAND Flash , eMMC, T-Card and Audio/SDMMC1_D1: MICRO_SD1.8 (DAT1/RES), RM1.3.2, U1.D14 (PC9/SDMMC1_D1/TRACED1/TIM3_CH4/TIM8_CH4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)
/NAND Flash , eMMC, T-Card and Audio/SDMMC1_D2: MICRO_SD1.1 (DAT2/RES), RM1.1.2, U1.F14 (PC10/SDMMC1_D2/TRACED2/DFSDM1_CKIN5/SPI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)
/NAND Flash , eMMC, T-Card and Audio/SDMMC1_D3: MICRO_SD1.2 (CD/DAT3/CS), R54.1, U1.D15 (PC11/SDMMC1_D3/TRACED3/DFSDM1_DATIN5/SP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)
/NAND Flash , eMMC, T-Card and Audio/SDMMC1_DET: MICRO_SD1.9, RM1.4.2, U1.Y4 (PG1/TRACED0/LPTIM1_OUT/SAI1_CK2/SAI4_CK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)
/NAND Flash , eMMC, T-Card and Audio/SPI_CLK: Flash1.8 (SPI-SCLK(CLK)), U1.V12 (PF10/QUADSPI_CLK/TIM16_BKIN/SAI1_D3/SAI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)
/NAND Flash , eMMC, T-Card and Audio/SPI_CS: Flash1.20 (SPI-CSn(CMD)), U1.W13 (PB6/QUADSPI_BK1_NCS/TIM16_CH1N/TIM4_CH1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)
/NAND Flash , eMMC, T-Card and Audio/SPI_IO0: Flash1.12 (SPI-MOSI(IO0)), U1.AB10 (PF8/QUADSPI_BK1_IO0/TRACED12/TIM16_CH1N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)
/NAND Flash , eMMC, T-Card and Audio/SPI_IO1: Flash1.16 (SPI-MISO(IO1)), U1.AB11 (PF9/QUADSPI_BK1_IO1/TRACED13/TIM17_CH1N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)
/NAND Flash , eMMC, T-Card and Audio/SPI_IO2: Flash1.18 (SPI-WPn(IO2)), U1.AA10 (PF7/QUADSPI_BK1_IO2/TIM17_CH1/SPI5_SCK/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)
/NAND Flash , eMMC, T-Card and Audio/SPI_IO3: Flash1.14 (SPI-HOLD(IO3)), U1.AA11 (PF6/QUADSPI_BK1_IO3/TIM16_CH1/SPI5_NSS/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)
ADC1_INN1: U1.R4 (ANA0/ADC1_INP0/ADC1_INN1/ADC2_INP0/ADC2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); also elsewhere on the board
ADC1_INP1: U1.T5 (ANA1/ADC1_INP1/ADC2_INP1); also elsewhere on the board
ADC2_INN18: U1.U5 (PA5/ADC1_INP19/ADC1_INN18/ADC2_INP19/AD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); also elsewhere on the board
ADC2_INP18: U1.V6 (PA4/ADC1_INP18/ADC2_INP18/DAC_OUT1/HDP0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); also elsewhere on the board
GND: C40.1, C41.1, C42.2, C43.2, C44.2, C45.2, C46.2, Flash1.6 (GND), Flash1.10 (GND), Flash1.21 (GND), Flash1.22 (GND), Flash1.25 (GND), Flash1.26 (GND), Flash1.29 (GND), Flash1.30 (GND), Flash1.33 (GND), Flash1.34 (GND), Flash1.37 (GND), Flash1.38 (GND), MICRO_SD1.6 (VSS), MICRO_SD1.10, MICRO_SD1.11, MICRO_SD1.12, MICRO_SD1.13, Q2.3 (case), R48.1, R50.1, R52.1, R53.2; also elsewhere on the board
I2C4_SCL: U1.G1 (PZ4/I2C6_SCL/I2C2_SCL/I2C5_SCL/I2C4_SCL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); also elsewhere on the board
I2C4_SDA: U1.H4 (PZ5/I2C6_SDA/I2C2_SDA/I2C5_SDA/I2C4_SDA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); also elsewhere on the board
JTCK-SWCLK: U1.D17 (JTCK-SWCLK); also elsewhere on the board
JTDI: U1.D16 (JTDI); also elsewhere on the board
JTDO-TRACESWO: U1.E16 (JTDO-TRACESWO); also elsewhere on the board
JTMS-SWDIO: U1.E17 (JTMS-SWDIO); also elsewhere on the board
NAND-ALE: U1.W12 (PD12/FMC_ALE/LPTIM1_IN1/TIM4_CH1/LPTIM2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); also elsewhere on the board
NAND-CE: U1.W15 (PG9/FMC_NCE/DBTRGO/USART6_RX/SPDIFRX_IN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); also elsewhere on the board
NAND-CLE: U1.AB9 (PD11/FMC_CLE/LPTIM2_IN2/I2C4_SMBA/I2C1_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); also elsewhere on the board
NAND-DQ0: U1.M3 (PD14/FMC_D0/TIM4_CH3/SAI3_MCLK_B/UART8_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); also elsewhere on the board
NAND-DQ1: U1.L1 (PD15/FMC_D1/TIM4_CH4/SAI3_MCLK_A/UART8_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); also elsewhere on the board
NAND-DQ2: U1.C10 (PD0/FMC_D2/I2C6_SDA/DFSDM1_CKIN6/I2C5_S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); also elsewhere on the board
NAND-DQ3: U1.B10 (PD1/FMC_D3/I2C6_SCL/DFSDM1_DATIN6/I2C5_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); also elsewhere on the board
NAND-DQ4: U1.W10 (PE7/FMC_D4/TIM1_ETR/TIM3_ETR/DFSDM1_DAT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); also elsewhere on the board
NAND-DQ5: U1.Y12 (PE8/FMC_D5/TIM1_CH1N/DFSDM1_CKIN2/UART7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); also elsewhere on the board
NAND-DQ6: U1.W11 (PE9/FMC_D6/TIM1_CH1/DFSDM1_CKOUT/UART7_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); also elsewhere on the board
NAND-DQ7: U1.W14 (PE10/FMC_D7/TIM1_CH2N/DFSDM1_DATIN4/UAR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); also elsewhere on the board
NAND-RB: U1.L3 (PD6/FMC_NWAIT/TIM16_CH1N/SAI1_D1/DFSDM1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); also elsewhere on the board
NAND-RE: U1.C9 (PD4/FMC_NOE/SAI3_FS_A/USART2_RTS/USART2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); also elsewhere on the board
NAND-WE: U1.A9 (PD5/FMC_NWE/USART2_TX/SDMMC3_D2/EVENTOUT); also elsewhere on the board
NJTRST: U1.E15 (NJTRST); also elsewhere on the board
NRST: C41.2, Flash1.5 (eMMC-RST), R43.1, U1.R2 (NRST); also elsewhere on the board
unnamed: C40.2, R43.2, U1.R1 (NRST_CORE)
unnamed: C42.1, Q1.1, R40.1, U1.P1 (PC14-OSC32_IN/OSC32_IN/EVENTOUT)
unnamed: C43.1, Q1.2, R46.2
unnamed: C44.1, Q2.2, U1.T1 (PH0-OSC_IN/OSC_IN/EVENTOUT)
unnamed: C45.1, Q2.1, R41.2
unnamed: C46.1, L1.2, MICRO_SD1.4 (VDD)
unnamed: MICRO_SD1.5 (CLK/SCLK), R53.1, R56.1
unnamed: R40.2, R46.1, U1.P2 (PC15-OSC32_OUT/OSC32_IN/EVENTOUT)
unnamed: R41.1, U1.T2 (PH1-OSC_OUT/OSC_OUT/EVENTOUT)
unnamed: R42.2, U1.A10 (PE3/SDMMC2_CK/TRACED0/TIM15_BKIN/SAI1_S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)
unnamed: R44.2, U1.U2 (PDR_ON_CORE)
unnamed: R45.2, U1.V2 (PDR_ON)
unnamed: R47.2, R48.2, U1.N3 (BOOT0)
unnamed: R49.2, R50.2, U1.N4 (BOOT1)
unnamed: R51.2, R52.2, U1.P4 (BOOT2)
PC0: U1.U10 (PC0/QUADSPI_BK2_NCS/DFSDM1_CKIN0/LPTIM2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); also elsewhere on the board
PC7: U1.D13 (PC7/SDMMC1_D123DIR/HDP4/TIM3_CH2/TIM8_C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); also elsewhere on the board
PE4: U1.F15 (PE4/SDMMC1_CKIN/TRACED1/SAI1_D2/DFSDM1_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); also elsewhere on the board
PF2: U1.F13 (PF2/SDMMC1_D0DIR/I2C2_SMBA/SDMMC2_D0DIR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); also elsewhere on the board
PG7: U1.Y11 (PG7/QUADSPI_BK2_IO3/TRACED5/SAI1_MCLK_A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); also elsewhere on the board
PG10: U1.AA9 (PG10/QUADSPI_BK2_IO2/TRACED10/UART8_CTS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); also elsewhere on the board
PH2: U1.AB7 (PH2/QUADSPI_BK2_IO0/LPTIM1_IN2/SAI2_SCK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); also elsewhere on the board
PH3: U1.Y6 (PH3/QUADSPI_BK2_IO1/DFSDM1_CKIN4/SAI2_M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); also elsewhere on the board
SPI4_NSS: U1.D5 (PE11/TIM1_CH2/DFSDM1_CKIN4/SPI4_NSS/USA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); also elsewhere on the board
TIM2_CH1: U1.AA3 (PA0/TIM2_CH1/TIM2_ETR/TIM5_CH1/TIM8_ETR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); also elsewhere on the board
VDD: R44.1, R45.1, R47.1, R49.1, R51.1; also elsewhere on the board

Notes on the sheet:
T-Card
??? 22R
??? ili oscilator
???

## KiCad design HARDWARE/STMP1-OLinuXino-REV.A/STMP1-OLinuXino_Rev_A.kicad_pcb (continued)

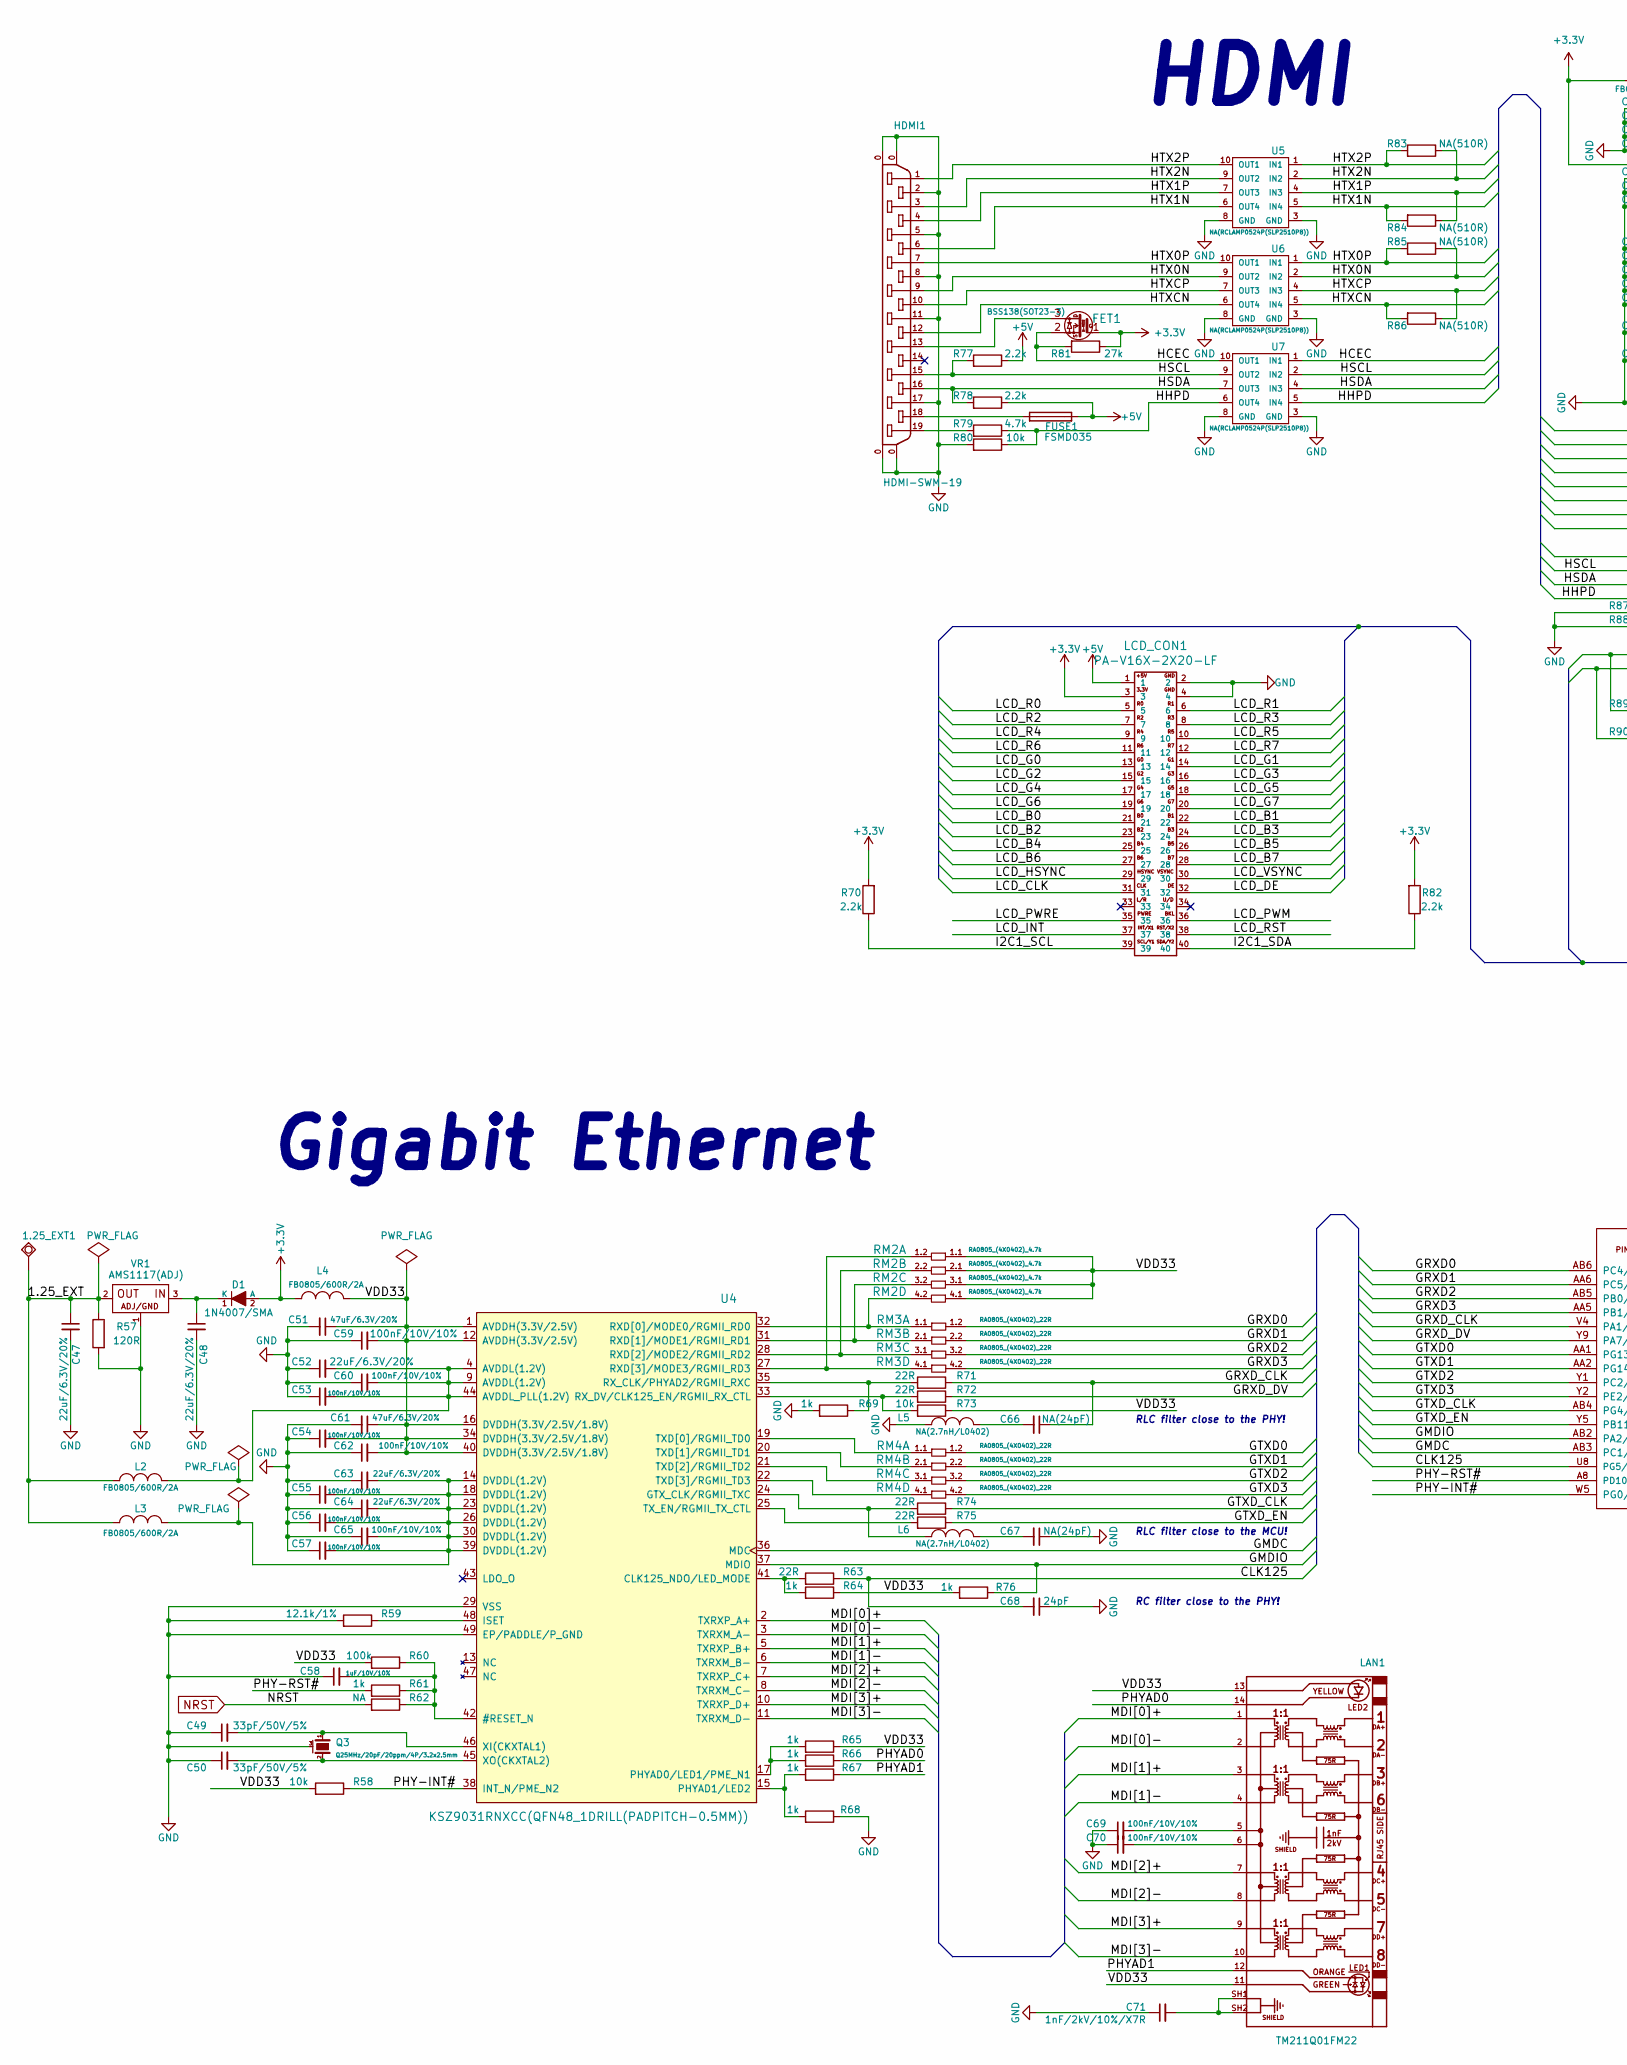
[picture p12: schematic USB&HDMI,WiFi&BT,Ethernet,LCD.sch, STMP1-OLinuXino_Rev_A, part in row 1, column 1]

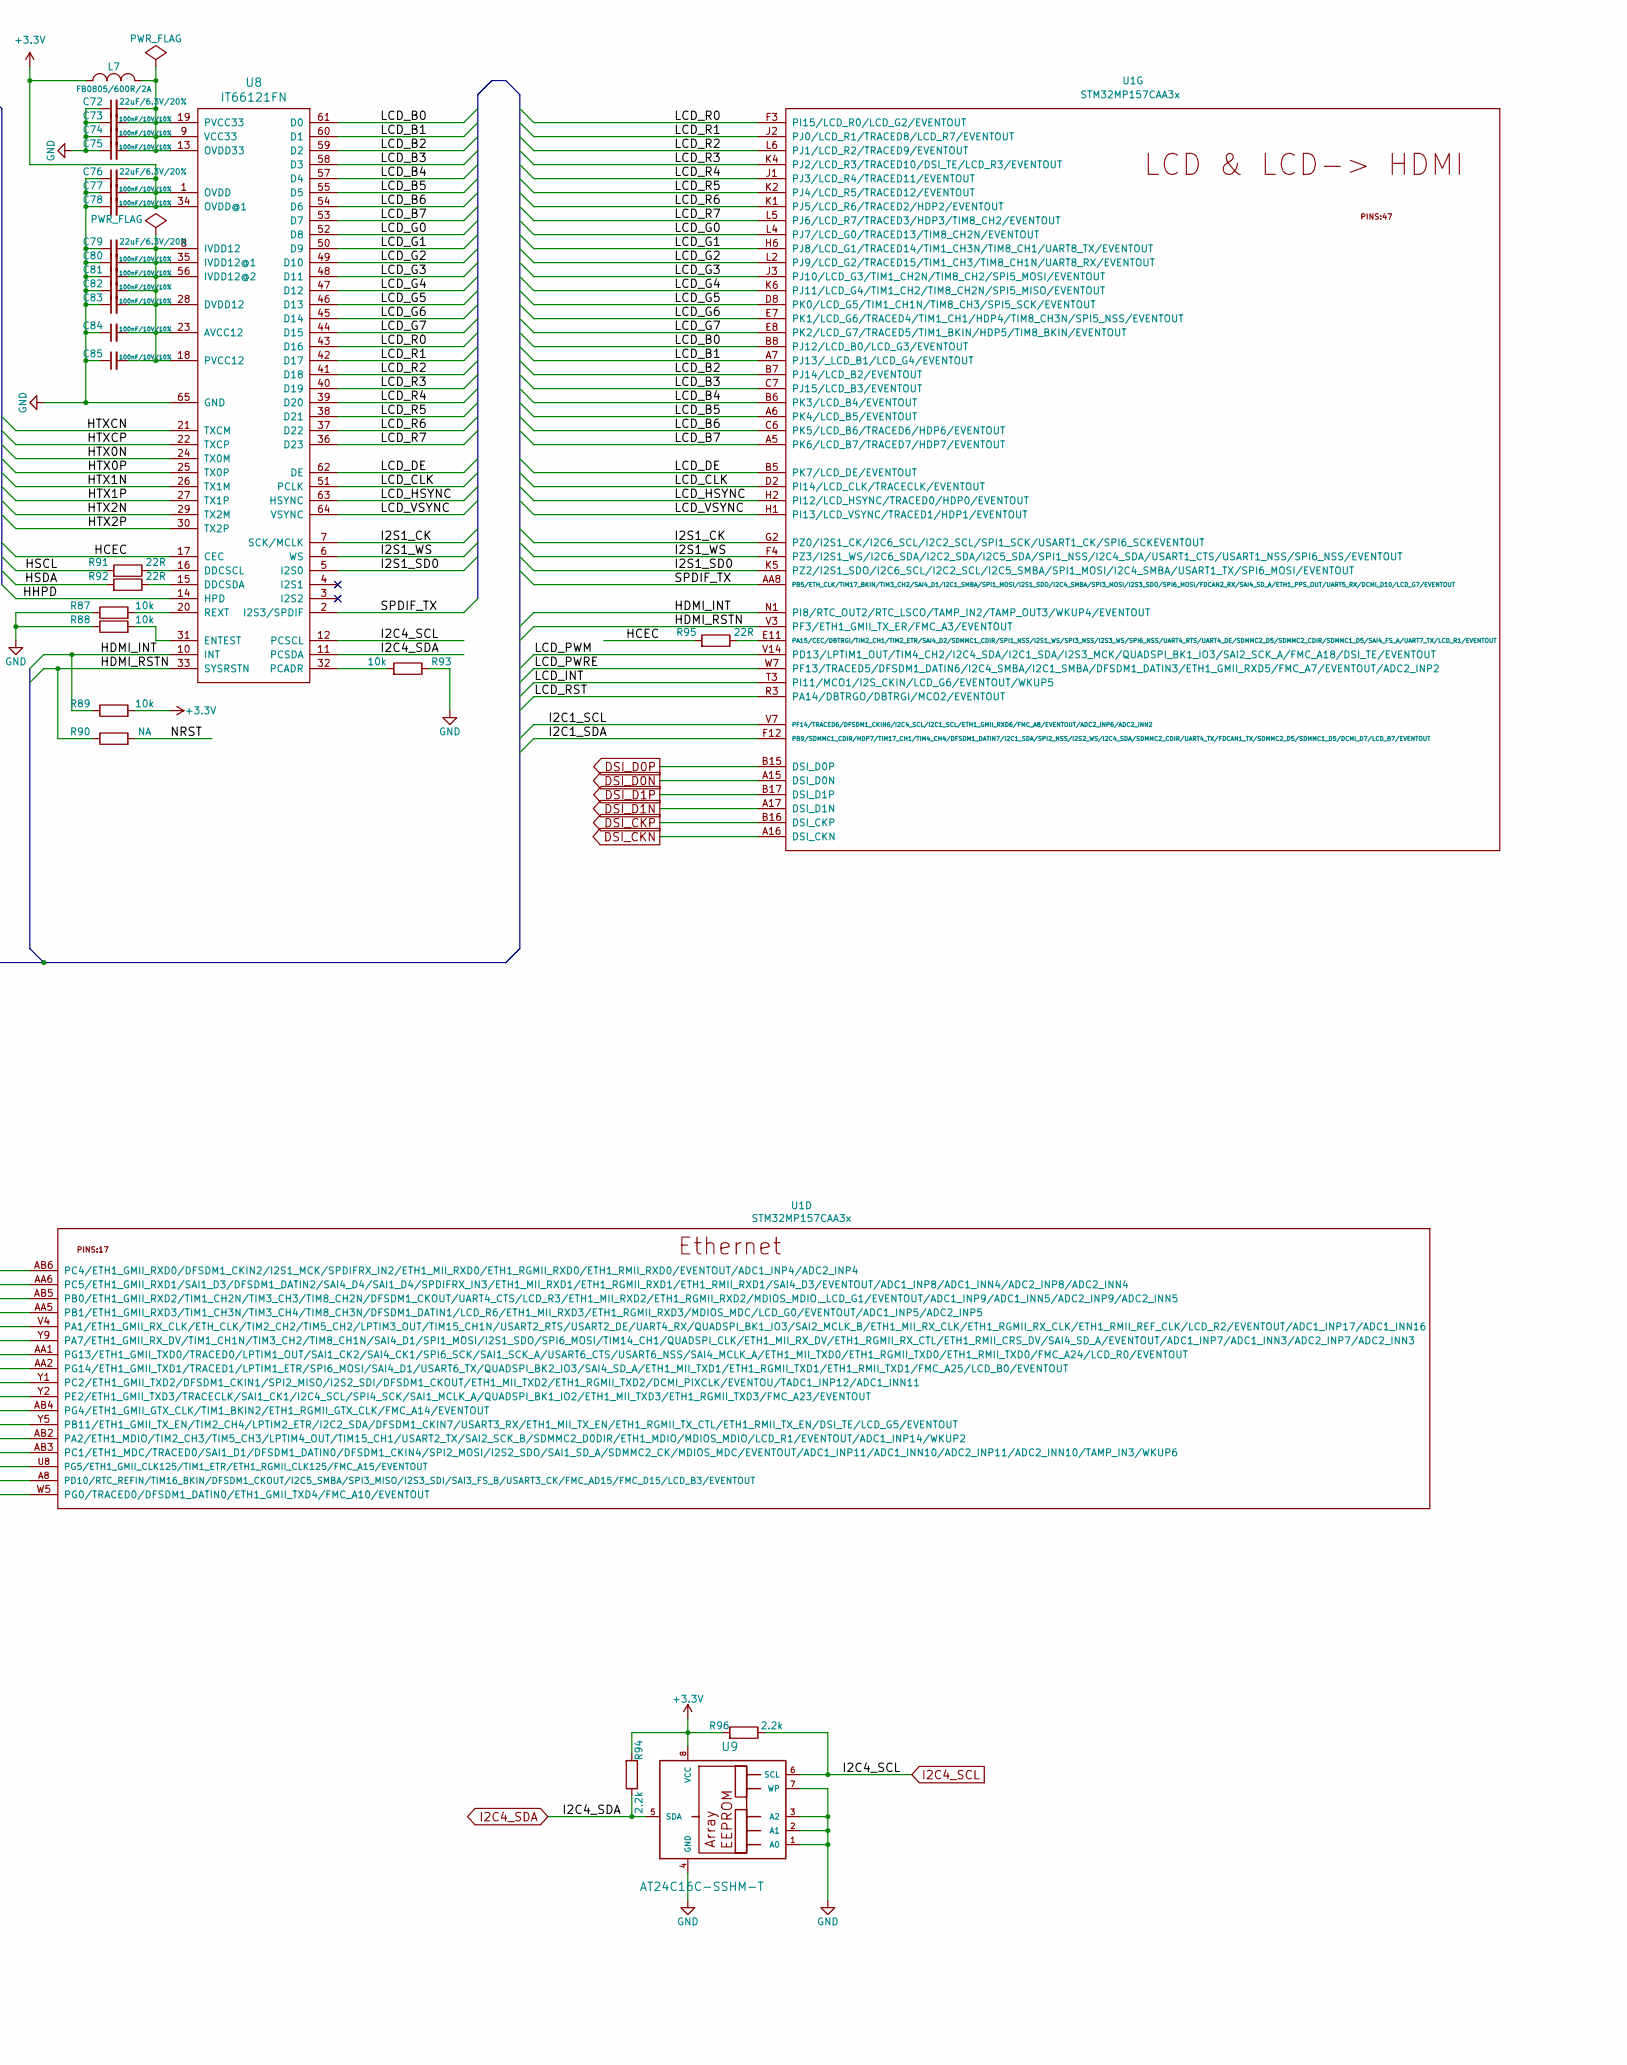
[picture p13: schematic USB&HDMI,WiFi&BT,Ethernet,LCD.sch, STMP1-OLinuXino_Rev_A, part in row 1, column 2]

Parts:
1.25_EXT1: TESTPAD; TP_SMD
C47, C48, C52, C63, C64, C72, C76, C79: 22uF/6.3V/20%; C_0603_5MIL_DWS
C49, C50: 33pF/50V/5%; C_0402_5MIL_DWS
C51, C61: 47uF/6.3V/20%; C_0805_5MIL_DWS
C53, C54, C55, C56, C57, C59, C60, C62, C65, C69, C70, C73, C74, C75, C77, C78, C80, C81, C82, C83, C84, C85: 100nF/10V/10%; C_0402_5MIL_DWS
C58: 1uF/10V/10%; C_0603_5MIL_DWS
C66, C67: NA(24pF); C_0402_5MIL_DWS
C68: 24pF; C_0402_5MIL_DWS
C71: 1nF/2kV/10%/X7R; C_1206_5MIL_DWS_ISO
D1: 1N4007/SMA; SMA-KA
FET1: BSS138(SOT23-3); SOT23
FUSE1: FSMD035; FUSE-1206
HDMI1: HDMI-SWM-19
L2, L3, L4, L7: FB0805/600R/2A; L_0805_5MIL_DWS
L5, L6: NA(2.7nH/L0402); L_0402_5MIL_DWS
LAN1: TM211Q01FM22
LCD_CON1: PA-V16X-2X20-LF; GPH127SMT-02X20(PA-V16X-2X20-LF)
Q3: Q25MHz/20pF/20ppm/4P/3.2x2.5mm; TSX-3.2x2.5mm_GND(3)
R57: 120R; R_0603_5MIL_DWS
R58, R73, R80, R87, R88, R89, R93: 10k; R_0402_5MIL_DWS
R59: 12.1k/1%; R_0603_5MIL_DWS
R60: 100k; R_0402_5MIL_DWS
R61, R64, R65, R66, R67, R68, R69, R76: 1k; R_0402_5MIL_DWS
R62, R90: NA; R_0402_5MIL_DWS
R63, R71, R72, R74, R75, R91, R92, R95: 22R; R_0402_5MIL_DWS
R70, R77, R78, R82, R94, R96: 2.2k; R_0402_5MIL_DWS
R79: 4.7k; R_0402_5MIL_DWS
R81: 27k; R_0402_5MIL_DWS
R83, R84, R85, R86: NA(510R); R_0402_5MIL_DWS
RM2: RA0805_(4X0402)_4.7k; RA0805_(4X0402)_xx_BIGGEROUTPADS
RM3, RM4: RA0805_(4X0402)_22R; RA0805_(4X0402)_xx_BIGGEROUTPADS
U1: STM32MP157CAA3x; LFBGA-448(Pitch-0.8mm_Pad-0.4mm_18x18x1.27mm)
U4: KSZ9031RNXCC(QFN48_1DRILL(PADPITCH-0.5MM)); QFN48_1DRILL(PADPITCH-0.5MM)
U5, U6, U7: NA(RCLAMP0524P(SLP2510P8)); SLP2510P8_TEST
U8: IT66121FN; QFN64_9x9mm_Pitch_0.5mm_65PAD_4.5mm
U9: AT24C16C-SSHM-T; SOIC-8_150mil
VR1: AMS1117(ADJ); SOT223

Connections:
+3V3: C76.2, C77.2, C78.2, D1.2 (A), FET1.1 (G), L4.2, L7.2, LCD_CON1.3, R70.2, R81.1, R82.2, R89.2, R94.2, R96.2, U8.1 (OVDD), U8.34 (OVDD@1), U9.8 (VCC); also elsewhere on the board
+5V: FUSE1.1, LCD_CON1.1, R77.1, R78.1; also elsewhere on the board
/USB&HDMI,WiFi&BT,Ethernet,LCD/1.25_EXT: 1.25_EXT1.1, C47.1, L2.2, L3.2, R57.1, VR1.2 (OUT)
/USB&HDMI,WiFi&BT,Ethernet,LCD/CLK125: C68.2, R63.1, U1.U8 (PG5/ETH1_GMII_CLK125/TIM1_ETR/ETH1_RGMI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)
/USB&HDMI,WiFi&BT,Ethernet,LCD/GMDC: U1.AB3 (PC1/ETH1_MDC/TRACED0/SAI1_D1/DFSDM1_DAT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), U4.36 (MDC)
/USB&HDMI,WiFi&BT,Ethernet,LCD/GMDIO: R76.1, U1.AB2 (PA2/ETH1_MDIO/TIM2_CH3/TIM5_CH3/LPTIM4_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), U4.37 (MDIO)
/USB&HDMI,WiFi&BT,Ethernet,LCD/GRXD0: RM3.1.2, U1.AB6 (PC4/ETH1_GMII_RXD0/DFSDM1_CKIN2/I2S1_MC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)
/USB&HDMI,WiFi&BT,Ethernet,LCD/GRXD1: RM3.2.2, U1.AA6 (PC5/ETH1_GMII_RXD1/SAI1_D3/DFSDM1_DATIN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)
/USB&HDMI,WiFi&BT,Ethernet,LCD/GRXD2: RM3.3.2, U1.AB5 (PB0/ETH1_GMII_RXD2/TIM1_CH2N/TIM3_CH3/T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)
/USB&HDMI,WiFi&BT,Ethernet,LCD/GRXD3: RM3.4.2, U1.AA5 (PB1/ETH1_GMII_RXD3/TIM1_CH3N/TIM3_CH4/T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)
/USB&HDMI,WiFi&BT,Ethernet,LCD/GRXD_CLK: C66.1, R71.1, U1.V4 (PA1/ETH1_GMII_RX_CLK/ETH_CLK/ТIM2_CH2/T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)
/USB&HDMI,WiFi&BT,Ethernet,LCD/GRXD_DV: R72.1, U1.Y9 (PA7/ETH1_GMII_RX_DV/TIM1_CH1N/TIM3_CH2/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)
/USB&HDMI,WiFi&BT,Ethernet,LCD/GTXD0: RM4.1.2, U1.AA1 (PG13/ETH1_GMII_TXD0/TRACED0/LPTIM1_OUT/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)
/USB&HDMI,WiFi&BT,Ethernet,LCD/GTXD1: RM4.2.2, U1.AA2 (PG14/ETH1_GMII_TXD1/TRACED1/LPTIM1_ETR/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)
/USB&HDMI,WiFi&BT,Ethernet,LCD/GTXD2: RM4.3.2, U1.Y1 (PC2/ETH1_GMII_TXD2/DFSDM1_CKIN1/SPI2_MI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)
/USB&HDMI,WiFi&BT,Ethernet,LCD/GTXD3: RM4.4.2, U1.Y2 (PE2/ETH1_GMII_TXD3/TRACECLK/SAI1_CK1/I2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)
/USB&HDMI,WiFi&BT,Ethernet,LCD/GTXD_CLK: R74.1, U1.AB4 (PG4/ETH1_GMII_GTX_CLK/TIM1_BKIN2/ETH1_R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)
/USB&HDMI,WiFi&BT,Ethernet,LCD/GTXD_EN: R75.1, U1.Y5 (PB11/ETH1_GMII_TX_EN/TIM2_CH4/LPTIM2_ET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)
/USB&HDMI,WiFi&BT,Ethernet,LCD/HCEC: FET1.2 (S), R81.2, R95.2, U7.1 (IN1), U7.10 (OUT1), U8.17 (CEC)
/USB&HDMI,WiFi&BT,Ethernet,LCD/HDMI_INT: R89.1, U1.N1 (PI8/RTC_OUT2/RTC_LSCO/TAMP_IN2/TAMP_OUT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), U8.10 (INT)
/USB&HDMI,WiFi&BT,Ethernet,LCD/HDMI_RSTN: R90.1, U1.V3 (PF3/ETH1_GMII_TX_ER/FMC_A3/EVENTOUT), U8.33 (SYSRSTN)
/USB&HDMI,WiFi&BT,Ethernet,LCD/HHPD: R79.1, R80.1, U7.5 (IN4), U7.6 (OUT4), U8.14 (HPD)
/USB&HDMI,WiFi&BT,Ethernet,LCD/HSCL: HDMI1.15, R77.2, R91.2, U7.2 (IN2), U7.9 (OUT2)
/USB&HDMI,WiFi&BT,Ethernet,LCD/HSDA: HDMI1.16, R78.2, R92.2, U7.4 (IN3), U7.7 (OUT3)
/USB&HDMI,WiFi&BT,Ethernet,LCD/HTX0N: HDMI1.9, R85.1, U6.2 (IN2), U6.9 (OUT2), U8.24 (TX0M)
/USB&HDMI,WiFi&BT,Ethernet,LCD/HTX0P: HDMI1.7, R85.2, U6.1 (IN1), U6.10 (OUT1), U8.25 (TX0P)
/USB&HDMI,WiFi&BT,Ethernet,LCD/HTX1N: HDMI1.6, R84.2, U5.5 (IN4), U5.6 (OUT4), U8.26 (TX1M)
/USB&HDMI,WiFi&BT,Ethernet,LCD/HTX1P: HDMI1.4, R84.1, U5.4 (IN3), U5.7 (OUT3), U8.27 (TX1P)
/USB&HDMI,WiFi&BT,Ethernet,LCD/HTX2N: HDMI1.3, R83.1, U5.2 (IN2), U5.9 (OUT2), U8.29 (TX2M)
/USB&HDMI,WiFi&BT,Ethernet,LCD/HTX2P: HDMI1.1, R83.2, U5.1 (IN1), U5.10 (OUT1), U8.30 (TX2P)
/USB&HDMI,WiFi&BT,Ethernet,LCD/HTXCN: HDMI1.12, R86.2, U6.5 (IN4), U6.6 (OUT4), U8.21 (TXCM)
/USB&HDMI,WiFi&BT,Ethernet,LCD/HTXCP: HDMI1.10, R86.1, U6.4 (IN3), U6.7 (OUT3), U8.22 (TXCP)
/USB&HDMI,WiFi&BT,Ethernet,LCD/I2C1_SCL: LCD_CON1.39, R70.1, U1.V7 (PF14/TRACED6/DFSDM1_CKIN6/I2C4_SCL/I2C1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)
/USB&HDMI,WiFi&BT,Ethernet,LCD/I2C1_SDA: LCD_CON1.40, R82.1, U1.F12 (PB9/SDMMC1_CDIR/HDP7/TIM17_CH1/TIM4_CH4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)
/USB&HDMI,WiFi&BT,Ethernet,LCD/I2S1_CK: U1.G2 (PZ0/I2S1_CK/I2C6_SCL/I2C2_SCL/SPI1_SCK/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), U8.7 (SCK/MCLK)
/USB&HDMI,WiFi&BT,Ethernet,LCD/I2S1_SD0: U1.K5 (PZ2/I2S1_SDO/I2C6_SCL/I2C2_SCL/I2C5_SMB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), U8.5 (I2S0)
/USB&HDMI,WiFi&BT,Ethernet,LCD/I2S1_WS: U1.F4 (PZ3/I2S1_WS/I2C6_SDA/I2C2_SDA/I2C5_SDA/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), U8.6 (WS)
/USB&HDMI,WiFi&BT,Ethernet,LCD/LCD_B0: LCD_CON1.21, U1.B8 (PJ12/LCD_B0/LCD_G3/EVENTOUT), U8.61 (D0)
/USB&HDMI,WiFi&BT,Ethernet,LCD/LCD_B1: LCD_CON1.22, U1.A7 (PJ13/_LCD_B1/LCD_G4/EVENTOUT), U8.60 (D1)
/USB&HDMI,WiFi&BT,Ethernet,LCD/LCD_B2: LCD_CON1.23, U1.B7 (PJ14/LCD_B2/EVENTOUT), U8.59 (D2)
/USB&HDMI,WiFi&BT,Ethernet,LCD/LCD_B3: LCD_CON1.24, U1.C7 (PJ15/LCD_B3/EVENTOUT), U8.58 (D3)
/USB&HDMI,WiFi&BT,Ethernet,LCD/LCD_B4: LCD_CON1.25, U1.B6 (PK3/LCD_B4/EVENTOUT), U8.57 (D4)
/USB&HDMI,WiFi&BT,Ethernet,LCD/LCD_B5: LCD_CON1.26, U1.A6 (PK4/LCD_B5/EVENTOUT), U8.55 (D5)
/USB&HDMI,WiFi&BT,Ethernet,LCD/LCD_B6: LCD_CON1.27, U1.C6 (PK5/LCD_B6/TRACED6/HDP6/EVENTOUT), U8.54 (D6)
/USB&HDMI,WiFi&BT,Ethernet,LCD/LCD_B7: LCD_CON1.28, U1.A5 (PK6/LCD_B7/TRACED7/HDP7/EVENTOUT), U8.53 (D7)
/USB&HDMI,WiFi&BT,Ethernet,LCD/LCD_CLK: LCD_CON1.31, U1.D2 (PI14/LCD_CLK/TRACECLK/EVENTOUT), U8.51 (PCLK)
/USB&HDMI,WiFi&BT,Ethernet,LCD/LCD_DE: LCD_CON1.32, U1.B5 (PK7/LCD_DE/EVENTOUT), U8.62 (DE)
/USB&HDMI,WiFi&BT,Ethernet,LCD/LCD_G0: LCD_CON1.13, U1.L4 (PJ7/LCD_G0/TRACED13/TIM8_CH2N/EVENTOUT), U8.52 (D8)
/USB&HDMI,WiFi&BT,Ethernet,LCD/LCD_G1: LCD_CON1.14, U1.H6 (PJ8/LCD_G1/TRACED14/TIM1_CH3N/TIM8_CH1/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), U8.50 (D9)
/USB&HDMI,WiFi&BT,Ethernet,LCD/LCD_G2: LCD_CON1.15, U1.L2 (PJ9/LCD_G2/TRACED15/TIM1_CH3/TIM8_CH1N/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), U8.49 (D10)
/USB&HDMI,WiFi&BT,Ethernet,LCD/LCD_G3: LCD_CON1.16, U1.J3 (PJ10/LCD_G3/TIM1_CH2N/TIM8_CH2/SPI5_MOS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), U8.48 (D11)
/USB&HDMI,WiFi&BT,Ethernet,LCD/LCD_G4: LCD_CON1.17, U1.K6 (PJ11/LCD_G4/TIM1_CH2/TIM8_CH2N/SPI5_MIS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), U8.47 (D12)
/USB&HDMI,WiFi&BT,Ethernet,LCD/LCD_G5: LCD_CON1.18, U1.D8 (PK0/LCD_G5/TIM1_CH1N/TIM8_CH3/SPI5_SCK/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), U8.46 (D13)
/USB&HDMI,WiFi&BT,Ethernet,LCD/LCD_G6: LCD_CON1.19, U1.E7 (PK1/LCD_G6/TRACED4/TIM1_CH1/HDP4/TIM8_C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), U8.45 (D14)
/USB&HDMI,WiFi&BT,Ethernet,LCD/LCD_G7: LCD_CON1.20, U1.E8 (PK2/LCD_G7/TRACED5/TIM1_BKIN/HDP5/TIM8_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), U8.44 (D15)
/USB&HDMI,WiFi&BT,Ethernet,LCD/LCD_HSYNC: LCD_CON1.29, U1.H2 (PI12/LCD_HSYNC/TRACED0/HDP0/EVENTOUT), U8.63 (HSYNC)
/USB&HDMI,WiFi&BT,Ethernet,LCD/LCD_INT: LCD_CON1.37, U1.T3 (PI11/MCO1/I2S_CKIN/LCD_G6/EVENTOUT/WKUP5)
/USB&HDMI,WiFi&BT,Ethernet,LCD/LCD_PWM: LCD_CON1.36, U1.V14 (PD13/LPTIM1_OUT/TIM4_CH2/I2C4_SDA/I2C1_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)
/USB&HDMI,WiFi&BT,Ethernet,LCD/LCD_PWRE: LCD_CON1.35, U1.W7 (PF13/TRACED5/DFSDM1_DATIN6/I2C4_SMBA/I2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)
/USB&HDMI,WiFi&BT,Ethernet,LCD/LCD_R0: LCD_CON1.5, U1.F3 (PI15/LCD_R0/LCD_G2/EVENTOUT), U8.43 (D16)
/USB&HDMI,WiFi&BT,Ethernet,LCD/LCD_R1: LCD_CON1.6, U1.J2 (PJ0/LCD_R1/TRACED8/LCD_R7/EVENTOUT), U8.42 (D17)
/USB&HDMI,WiFi&BT,Ethernet,LCD/LCD_R2: LCD_CON1.7, U1.L6 (PJ1/LCD_R2/TRACED9/EVENTOUT), U8.41 (D18)
/USB&HDMI,WiFi&BT,Ethernet,LCD/LCD_R3: LCD_CON1.8, U1.K4 (PJ2/LCD_R3/TRACED10/DSI_TE/LCD_R3/EVENT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), U8.40 (D19)
/USB&HDMI,WiFi&BT,Ethernet,LCD/LCD_R4: LCD_CON1.9, U1.J1 (PJ3/LCD_R4/TRACED11/EVENTOUT), U8.39 (D20)
/USB&HDMI,WiFi&BT,Ethernet,LCD/LCD_R5: LCD_CON1.10, U1.K2 (PJ4/LCD_R5/TRACED12/EVENTOUT), U8.38 (D21)
/USB&HDMI,WiFi&BT,Ethernet,LCD/LCD_R6: LCD_CON1.11, U1.K1 (PJ5/LCD_R6/TRACED2/HDP2/EVENTOUT), U8.37 (D22)
/USB&HDMI,WiFi&BT,Ethernet,LCD/LCD_R7: LCD_CON1.12, U1.L5 (PJ6/LCD_R7/TRACED3/HDP3/TIM8_CH2/EVENTO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), U8.36 (D23)
/USB&HDMI,WiFi&BT,Ethernet,LCD/LCD_RST: LCD_CON1.38, U1.R3 (PA14/DBTRGO/DBTRGI/MCO2/EVENTOUT)
/USB&HDMI,WiFi&BT,Ethernet,LCD/LCD_VSYNC: LCD_CON1.30, U1.H1 (PI13/LCD_VSYNC/TRACED1/HDP1/EVENTOUT), U8.64 (VSYNC)
/USB&HDMI,WiFi&BT,Ethernet,LCD/MDI[0]+: LAN1.1, U4.2 (TXRXP_A+)
/USB&HDMI,WiFi&BT,Ethernet,LCD/MDI[0]-: LAN1.2, U4.3 (TXRXM_A-)
/USB&HDMI,WiFi&BT,Ethernet,LCD/MDI[1]+: LAN1.3, U4.5 (TXRXP_B+)
/USB&HDMI,WiFi&BT,Ethernet,LCD/MDI[1]-: LAN1.4, U4.6 (TXRXM_B-)
/USB&HDMI,WiFi&BT,Ethernet,LCD/MDI[2]+: LAN1.7, U4.7 (TXRXP_C+)
/USB&HDMI,WiFi&BT,Ethernet,LCD/MDI[2]-: LAN1.8, U4.8 (TXRXM_C-)
/USB&HDMI,WiFi&BT,Ethernet,LCD/MDI[3]+: LAN1.9, U4.10 (TXRXP_D+)
/USB&HDMI,WiFi&BT,Ethernet,LCD/MDI[3]-: LAN1.10, U4.11 (TXRXM_D-)
/USB&HDMI,WiFi&BT,Ethernet,LCD/PHY-INT#: R58.1, U1.W5 (PG0/TRACED0/DFSDM1_DATIN0/ETH1_GMII_TXD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), U4.38 (INT_N/PME_N2)
/USB&HDMI,WiFi&BT,Ethernet,LCD/PHY-RST#: R61.2, U1.A8 (PD10/RTC_REFIN/TIM16_BKIN/DFSDM1_CKOUT/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)
/USB&HDMI,WiFi&BT,Ethernet,LCD/PHYAD0: LAN1.14, R66.1
/USB&HDMI,WiFi&BT,Ethernet,LCD/PHYAD1: LAN1.12, R67.1
/USB&HDMI,WiFi&BT,Ethernet,LCD/SPDIF_TX: U1.AA8 (PB5/ETH_CLK/TIM17_BKIN/TIM3_CH2/SAI4_D1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), U8.2 (I2S3/SPDIF)
/USB&HDMI,WiFi&BT,Ethernet,LCD/VDD33: C51.1, C54.2, C59.2, C61.1, C62.2, L4.1, LAN1.11, LAN1.13, R58.2, R60.2, R64.1, R65.1, R73.1, R76.2, RM2.1.1, RM2.2.1, RM2.3.1, RM2.4.1, U4.1 (AVDDH(3.3V/2.5V)), U4.12 (AVDDH(3.3V/2.5V)), U4.16 (DVDDH(3.3V/2.5V/1.8V)), U4.34 (DVDDH(3.3V/2.5V/1.8V)), U4.40 (DVDDH(3.3V/2.5V/1.8V))
DSI_CKN: U1.A16 (DSI_CKN); also elsewhere on the board
DSI_CKP: U1.B16 (DSI_CKP); also elsewhere on the board
DSI_D0N: U1.A15 (DSI_D0N); also elsewhere on the board
DSI_D0P: U1.B15 (DSI_D0P); also elsewhere on the board
DSI_D1N: U1.A17 (DSI_D1N); also elsewhere on the board
DSI_D1P: U1.B17 (DSI_D1P); also elsewhere on the board
GND: C47.2, C48.2, C49.1, C50.1, C51.2, C52.1, C53.1, C54.1, C55.1, C56.1, C57.1, C58.1, C59.1, C60.1, C61.2, C62.1, C63.1, C64.1, C65.1, C67.1, C68.1, C69.1, C70.1, C71.1, C72.1, C73.1, C74.1, C75.1, C76.1, C77.1, C78.1, C79.1, C80.1, C81.1, C82.1, C83.1, C84.1, C85.1, HDMI1.0 (20), HDMI1.2, HDMI1.5, HDMI1.8, HDMI1.11, HDMI1.17, L5.2, LCD_CON1.2, LCD_CON1.4, Q3.3 (case), R57.2, R59.2, R68.1, R69.2, R80.2, R87.1, R88.1, R93.1, U4.29 (VSS), U4.49 (EP/PADDLE/P_GND), U5.3 (GND), U5.8 (GND), U6.3 (GND), U6.8 (GND), U7.3 (GND), U7.8 (GND), U8.65 (GND), U9.1 (A0), U9.2 (A1), U9.3 (A2), U9.4 (GND), U9.7 (WP), VR1.1 (ADJ/GND); also elsewhere on the board
I2C4_SCL: R96.1, U8.12 (PCSCL), U9.6 (SCL); also elsewhere on the board
I2C4_SDA: R94.1, U8.11 (PCSDA), U9.5 (SDA); also elsewhere on the board
NRST: R62.2, R90.2; also elsewhere on the board
unnamed: C48.1, D1.1 (K), VR1.3 (IN)
unnamed: C49.2, Q3.1, U4.46 (XI(CKXTAL1))
unnamed: C50.2, Q3.2, U4.45 (XO(CKXTAL2))
unnamed: C52.2, C53.2, C60.2, L2.1, U4.4 (AVDDL(1.2V)), U4.9 (AVDDL(1.2V)), U4.44 (AVDDL_PLL(1.2V))
unnamed: C55.2, C56.2, C57.2, C63.2, C64.2, C65.2, L3.1, U4.14 (DVDDL(1.2V)), U4.18 (DVDDL(1.2V)), U4.23 (DVDDL(1.2V)), U4.26 (DVDDL(1.2V)), U4.30 (DVDDL(1.2V)), U4.39 (DVDDL(1.2V))
unnamed: C58.2, R60.1, R61.1, R62.1, U4.42 (#RESET_N)
unnamed: C66.2, L5.1
unnamed: C67.2, L6.1
unnamed: C69.2, LAN1.5
unnamed: C70.2, LAN1.6
unnamed: C71.2, LAN1.SH1, LAN1.SH2
unnamed: C72.2, C73.2, C74.2, C75.2, L7.1, U8.9 (VCC33), U8.13 (OVDD33), U8.19 (PVCC33)
unnamed: C79.2, C80.2, C81.2, C82.2, C83.2, C84.2, C85.2, U8.8 (IVDD12), U8.18 (PVCC12), U8.23 (AVCC12), U8.28 (DVDD12), U8.35 (IVDD12@1), U8.56 (IVDD12@2)
unnamed: FET1.3 (D), HDMI1.13
unnamed: FUSE1.2, HDMI1.18
unnamed: HDMI1.19, R79.2
unnamed: L6.2, R74.2, U4.24 (GTX_CLK/RGMII_TXC)
unnamed: R59.1, U4.48 (ISET)
unnamed: R63.2, R64.2, U4.41 (CLK125_NDO/LED_MODE)
unnamed: R65.2, R66.2, U4.17 (PHYAD0/LED1/PME_N1)
unnamed: R67.2, R68.2, U4.15 (PHYAD1/LED2)
unnamed: R69.1, R71.2, U4.35 (RX_CLK/PHYAD2/RGMII_RXC)
unnamed: R72.2, R73.2, U4.33 (RX_DV/CLK125_EN/RGMII_RX_CTL)
unnamed: R75.2, U4.25 (TX_EN/RGMII_TX_CTL)
unnamed: R87.2, U8.20 (REXT)
unnamed: R88.2, U8.31 (ENTEST)
unnamed: R91.1, U8.16 (DDCSCL)
unnamed: R92.1, U8.15 (DDCSDA)
unnamed: R93.2, U8.32 (PCADR)
unnamed: R95.1, U1.E11 (PA15/CEC/DBTRGI/TIM2_CH1/TIM2_ETR/SAI4_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)
unnamed: RM2.1.2, RM3.4.1, U4.27 (RXD[3]/MODE3/RGMII_RD3)
unnamed: RM2.2.2, RM3.3.1, U4.28 (RXD[2]/MODE2/RGMII_RD2)
unnamed: RM2.3.2, RM3.2.1, U4.31 (RXD[1]/MODE1/RGMII_RD1)
unnamed: RM2.4.2, RM3.1.1, U4.32 (RXD[0]/MODE0/RGMII_RD0)
unnamed: RM4.1.1, U4.19 (TXD[0]/RGMII_TD0)
unnamed: RM4.2.1, U4.20 (TXD[1]/RGMII_TD1)
unnamed: RM4.3.1, U4.21 (TXD[2]/RGMII_TD2)
unnamed: RM4.4.1, U4.22 (TXD[3]/RGMII_TD3)

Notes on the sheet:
HDMI
Gigabit Ethernet
RLC filter close to the MCU!
RLC filter close to the PHY!
RC filter close to the PHY!

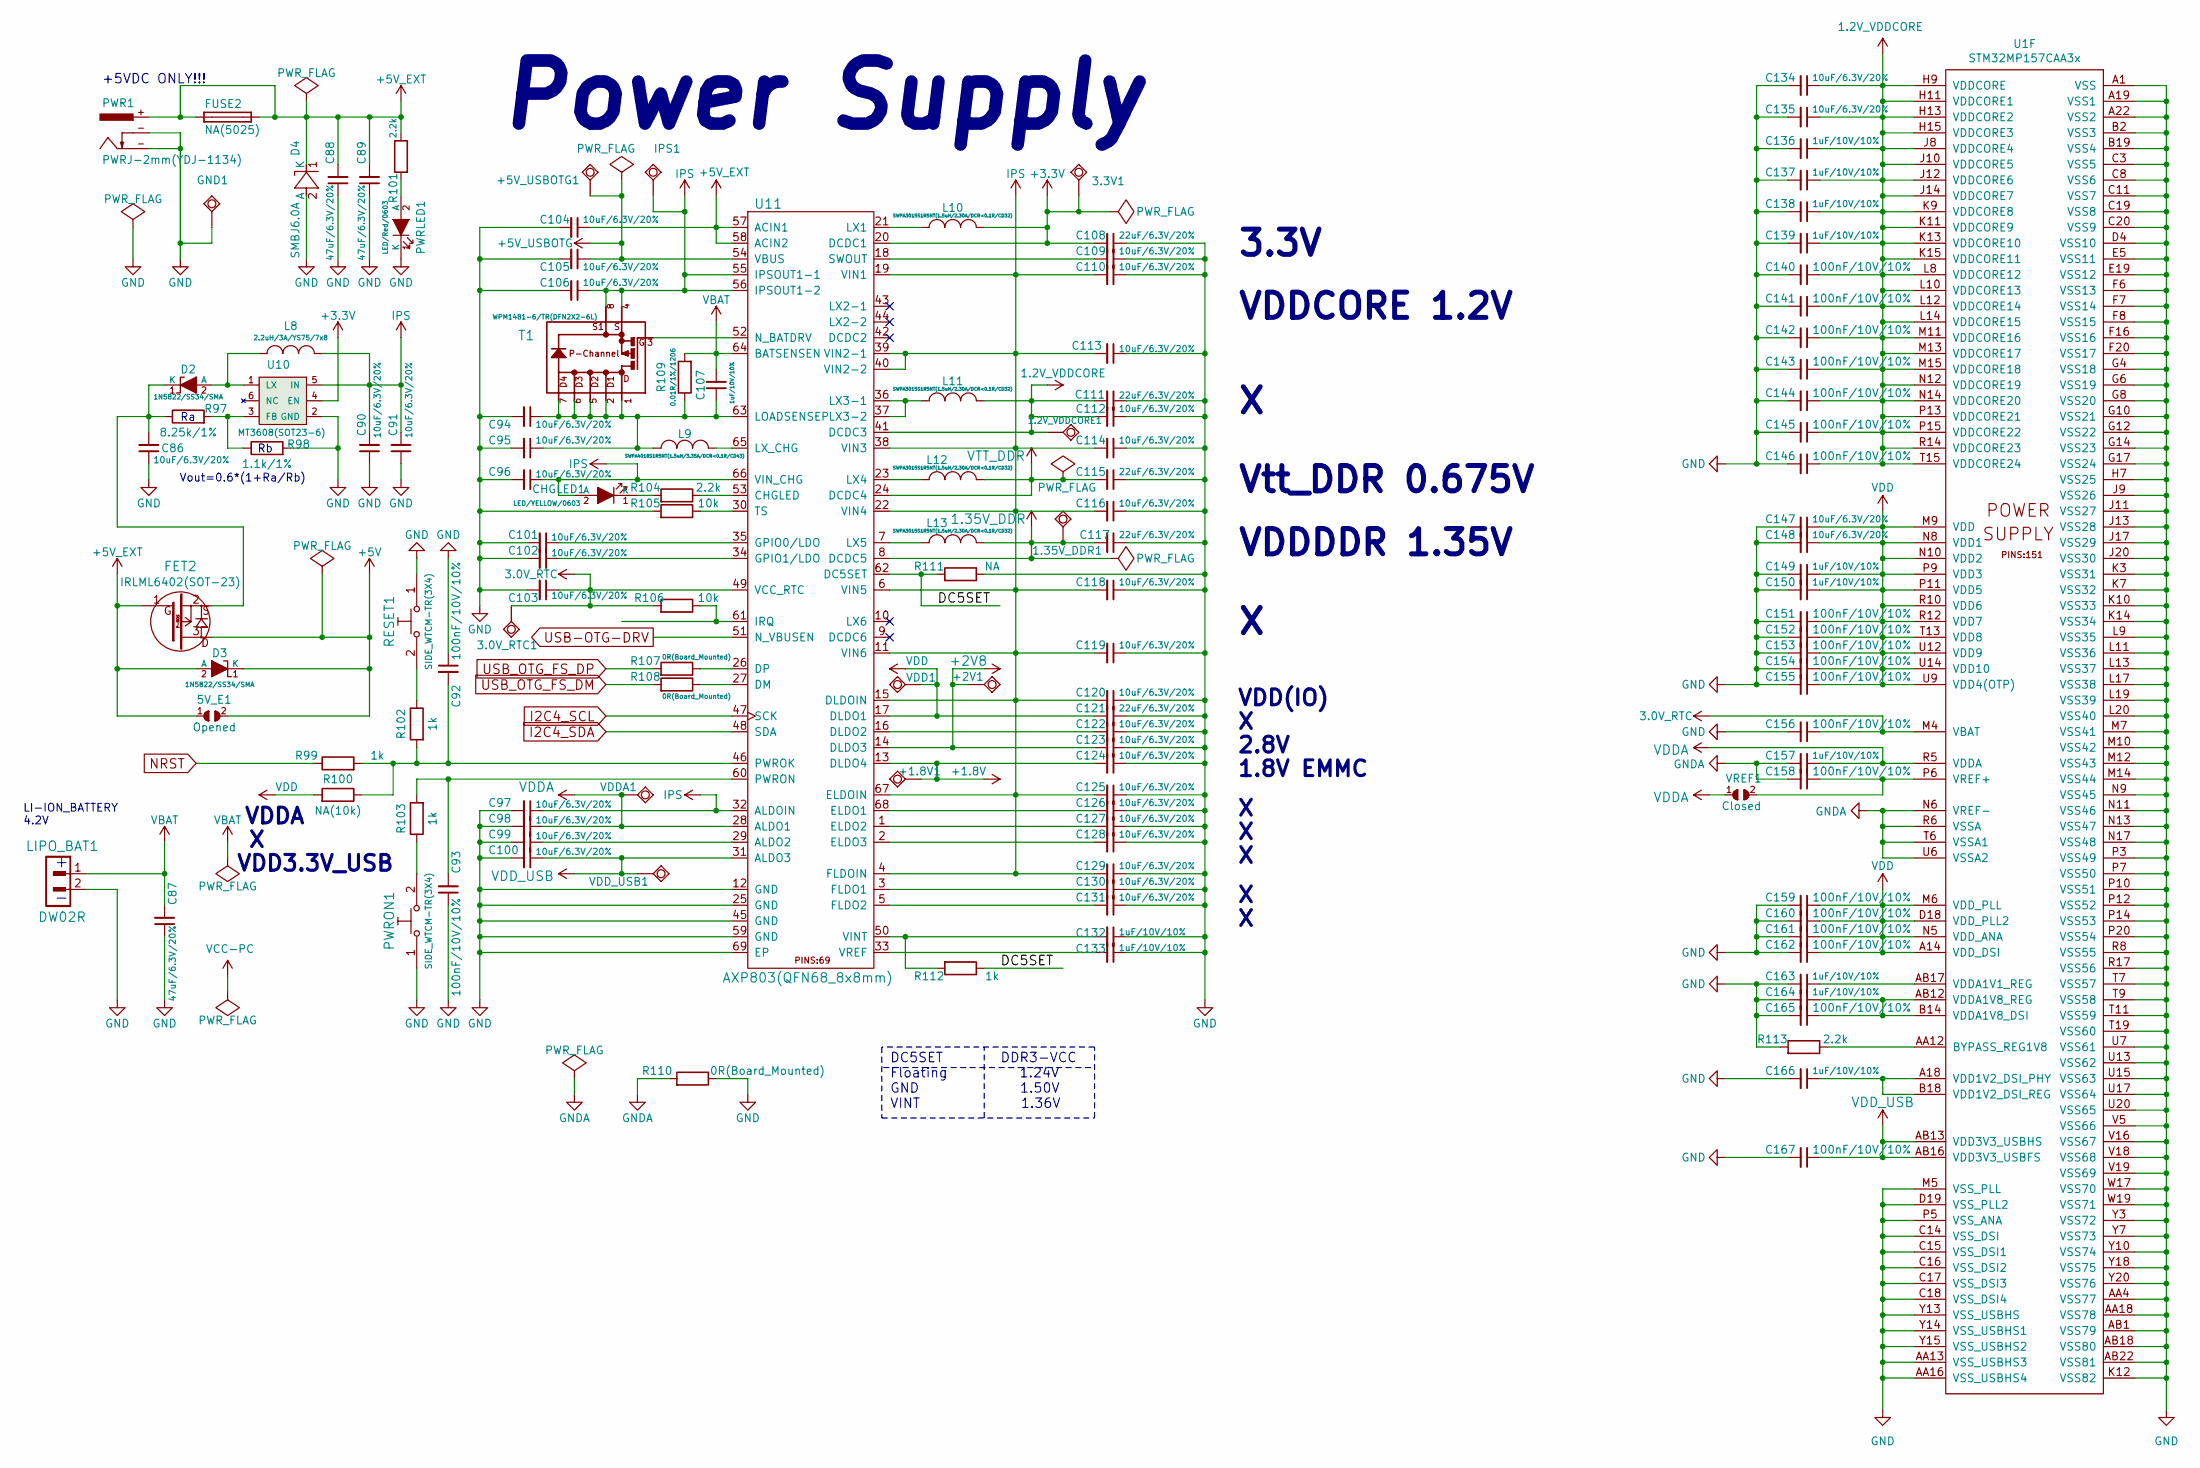
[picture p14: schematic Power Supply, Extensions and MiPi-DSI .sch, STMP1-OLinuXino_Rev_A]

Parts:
1.2V_VDDCORE1, 1.35V_DDR1, 3.0V_RTC1, 3.3V1: TESTPAD; TP_SMD
5V_E1: Opened; SJ_1_SMALLER
+1.8V1, +2V1, +5V_USBOTG1: TESTPAD; TP_SMD
C86, C90, C91, C94, C95, C96, C97, C98, C99, C100, C101, C102, C103, C104, C105, C106, C109, C110, C112, C113, C114, C116, C118, C119, C120, C122, C123, C124, C125, C126, C127, C128, C129, C130, C131, C134, C135, C147, C148: 10uF/6.3V/20%; C_0603_5MIL_DWS
C87, C88, C89: 47uF/6.3V/20%; C_0805_5MIL_DWS
C92, C93, C140, C141, C142, C143, C144, C145, C146, C151, C152, C153, C154, C155, C156, C158, C159, C160, C161, C162, C165, C167: 100nF/10V/10%; C_0402_5MIL_DWS
C107, C132, C133, C136, C137, C138, C139, C149, C150, C157, C163, C164, C166: 1uF/10V/10%; C_0603_5MIL_DWS
C108, C111, C115, C117, C121: 22uF/6.3V/20%; C_0603_5MIL_DWS
CHGLED1: LED/YELLOW/0603; LED_0603_KA
D2, D3: 1N5822/SS34/SMA; SMA-KA
D4: SMBJ6.0A; DO214AA_1(K)-2(A)
FET2: IRLML6402(SOT-23); SOT23
FUSE2: NA(5025); FUSE-5025
GND1: TESTPAD; TP_SMD
IPS1: TESTPAD; TP_SMD
L8: 2.2uH/3A/YS75/7x8; YS75_7X8MM
L9: SWPA4018S1R5NT(1.5uH/3.35A/DCR<0.1R/CD43); CD42(43)
L10, L11, L12, L13: SWPA3015S1R5NT(1.5uH/2.30A/DCR<0.1R/CD32); CD32
LIPO_BAT1: DW02R; LIPO_BAT-CON2DW02R
PWR1: PWRJ-2mm(YDJ-1134)
PWRLED1: LED/Red/0603; LED_0603_KA
PWRON1: SIDE_WTCM-TR(3X4); SW-TAKT3X4
R97: 8.25k/1%; R_0402_5MIL_DWS
R98: 1.1k/1%; R_0402_5MIL_DWS
R99, R102, R103, R112: 1k; R_0402_5MIL_DWS
R100: NA(10k); R_0402_5MIL_DWS
R101, R104, R113: 2.2k; R_0402_5MIL_DWS
R105, R106: 10k; R_0402_5MIL_DWS
R107, R108: 0R(Board_Mounted); R_0402_5MIL_0R(Board_Mounted)
R109: 0.01R/1%/1206; R_1206_5MIL_DWS
R110: 0R(Board_Mounted); R_0603_5MIL_0R(Board_Mounted)
R111: NA; R_0402_5MIL_DWS
RESET1: SIDE_WTCM-TR(3X4); SW-TAKT3X4
T1: WPM1481-6/TR(DFN2X2-6L); DFN2x2-6L
U1: STM32MP157CAA3x; LFBGA-448(Pitch-0.8mm_Pad-0.4mm_18x18x1.27mm)
U10: MT3608(SOT23-6); SOT23-6
U11: AXP803(QFN68_8x8mm); QFN68
VDD1: TESTPAD; TP_SMD
VDDA1: TESTPAD; TP_SMD
VDD_USB1: TESTPAD; TP_SMD
VREF1: Closed; SJ_1_SMALLER_TIED

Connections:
1.1V_CPUX: 1.2V_VDDCORE1.1, C111.2, C112.2, C134.1, C135.1, C136.1, C137.1, C138.1, C139.1, C140.1, C141.1, C142.1, C143.1, C144.1, C145.1, C146.1, L11.2, U1.H9 (VDDCORE), U1.H11 (VDDCORE1), U1.H13 (VDDCORE2), U1.H15 (VDDCORE3), U1.J8 (VDDCORE4), U1.J10 (VDDCORE5), U1.J12 (VDDCORE6), U1.J14 (VDDCORE7), U1.K9 (VDDCORE8), U1.K11 (VDDCORE9), U1.K13 (VDDCORE10), U1.K15 (VDDCORE11), U1.L8 (VDDCORE12), U1.L10 (VDDCORE13), U1.L12 (VDDCORE14), U1.L14 (VDDCORE15), U1.M11 (VDDCORE16), U1.M13 (VDDCORE17), U1.M15 (VDDCORE18), U1.N12 (VDDCORE19), U1.N14 (VDDCORE20), U1.P13 (VDDCORE21), U1.P15 (VDDCORE22), U1.R14 (VDDCORE23), U1.T15 (VDDCORE24), U11.41 (DCDC3)
1.35V_DDR: 1.35V_DDR1.1, C117.2, L13.2, U11.8 (DCDC5); also elsewhere on the board
3.0V_RTC: 3.0V_RTC1.1, C103.1, C156.1, R106.2, U1.M4 (VBAT), U11.49 (VCC_RTC)
+2V8: +2V1.1, C123.2, U11.14 (DLDO3); also elsewhere on the board
+3V3: 3.3V1.1, C108.2, L10.2, U10.4 (EN), U11.20 (DCDC1); also elsewhere on the board
+5V: 5V_E1.2, D3.1 (K), FET2.3; also elsewhere on the board
+5V_EXT: 5V_E1.1, C88.2, C89.2, C104.1, D3.2 (A), D4.1 (K), FET2.1, FUSE2.1, FUSE2.2, PWR1.+, R101.1, U11.57 (ACIN1), U11.58 (ACIN2)
+5V_USBOTG: +5V_USBOTG1.1, C105.1, U11.54 (VBUS); also elsewhere on the board
/Power Supply, Extensions and MiPi-DSI/DC5SET: R111.2, R112.1, U11.62 (DC5SET)
GND: C86.1, C87.1, C88.1, C89.1, C90.1, C91.1, C92.1, C93.1, C94.2, C95.2, C96.2, C97.2, C98.2, C99.2, C100.2, C101.2, C102.2, C103.2, C104.2, C105.2, C106.2, C108.1, C109.1, C110.1, C111.1, C112.1, C113.1, C114.1, C115.1, C116.1, C117.1, C118.1, C119.1, C120.1, C121.1, C122.1, C123.1, C124.1, C125.1, C126.1, C127.1, C128.1, C129.1, C130.1, C131.1, C132.1, C133.1, C134.2, C135.2, C136.2, C137.2, C138.2, C139.2, C140.2, C141.2, C142.2, C143.2, C144.2, C145.2, C146.2, C147.2, C148.2, C149.2, C150.2, C151.2, C152.2, C153.2, C154.2, C155.2, C156.2, C159.2, C160.2, C161.2, C162.2, C163.2, C164.2, C165.2, C166.2, C167.2, D4.2 (A), GND1.1, LIPO_BAT1.2, PWR1.-, PWRLED1.1 (K), PWRON1.1, R98.2, R105.2, R110.1, R111.1, R113.2, RESET1.1, U1.A1 (VSS), U1.A19 (VSS1), U1.A22 (VSS2), U1.AA4 (VSS77), U1.AA13 (VSS_USBHS3), U1.AA16 (VSS_USBHS4), U1.AA18 (VSS78), U1.AB1 (VSS79), U1.AB18 (VSS80), U1.AB22 (VSS81), U1.B2 (VSS3), U1.B19 (VSS4), U1.C3 (VSS5), U1.C8 (VSS6), U1.C11 (VSS7), U1.C14 (VSS_DSI), U1.C15 (VSS_DSI1), U1.C16 (VSS_DSI2), U1.C17 (VSS_DSI3), U1.C18 (VSS_DSI4), U1.C19 (VSS8), U1.C20 (VSS9), U1.D4 (VSS10), U1.D19 (VSS_PLL2), U1.E5 (VSS11), U1.E19 (VSS12), U1.F6 (VSS13), U1.F7 (VSS14), U1.F8 (VSS15), U1.F16 (VSS16), U1.F20 (VSS17), U1.G4 (VSS18), U1.G6 (VSS19), U1.G8 (VSS20), U1.G10 (VSS21), U1.G12 (VSS22), U1.G14 (VSS23), U1.G17 (VSS24), U1.H7 (VSS25), U1.J9 (VSS26), U1.J11 (VSS27), U1.J13 (VSS28), U1.J17 (VSS29), U1.J20 (VSS30), U1.K3 (VSS31), U1.K7 (VSS32), U1.K10 (VSS33), U1.K12 (VSS82), U1.K14 (VSS34), U1.L9 (VSS35), U1.L11 (VSS36), U1.L13 (VSS37), U1.L17 (VSS38), U1.L19 (VSS39), U1.L20 (VSS40), U1.M5 (VSS_PLL), U1.M7 (VSS41), U1.M10 (VSS42), U1.M12 (VSS43), U1.M14 (VSS44), U1.N9 (VSS45), U1.N11 (VSS46), U1.N13 (VSS47), U1.N17 (VSS48), U1.P3 (VSS49), U1.P5 (VSS_ANA), U1.P7 (VSS50), U1.P10 (VSS51), U1.P12 (VSS52), U1.P14 (VSS53), U1.P20 (VSS54), U1.R8 (VSS55), U1.R17 (VSS56), U1.T7 (VSS57), U1.T9 (VSS58), U1.T11 (VSS59), U1.T19 (VSS60), U1.U7 (VSS61), U1.U13 (VSS62), U1.U15 (VSS63), U1.U17 (VSS64), U1.U20 (VSS65), U1.V5 (VSS66), U1.V16 (VSS67), U1.V18 (VSS68), U1.V19 (VSS69), U1.W17 (VSS70), U1.W19 (VSS71), U1.Y3 (VSS72), U1.Y7 (VSS73), U1.Y10 (VSS74), U1.Y13 (VSS_USBHS), U1.Y14 (VSS_USBHS1), U1.Y15 (VSS_USBHS2), U1.Y18 (VSS75), U1.Y20 (VSS76), U10.2 (GND), U11.12 (GND), U11.25 (GND), U11.45 (GND), U11.59 (GND), U11.69 (EP); also elsewhere on the board
GNDA: C157.2, C158.2, R110.2, U1.N6 (VREF-), U1.R6 (VSSA), U1.T6 (VSSA1), U1.U6 (VSSA2); also elsewhere on the board
I2C4_SCL: U11.47 (SCK); also elsewhere on the board
I2C4_SDA: U11.48 (SDA); also elsewhere on the board
IPS: C90.2, C91.2, C96.1, C97.1, C106.1, C110.2, C113.2, C114.2, C116.2, C118.2, C119.2, C120.2, C125.2, C129.2, CHGLED1.2 (A), IPS1.1, L8.1, T1.4 (S), T1.8 (S1), U10.5 (IN), U11.4 (FLDOIN), U11.6 (VIN5), U11.11 (VIN6), U11.15 (DLDOIN), U11.19 (VIN1), U11.22 (VIN4), U11.32 (ALDOIN), U11.38 (VIN3), U11.39 (VIN2-1), U11.40 (VIN2-2), U11.55 (IPSOUT1-1), U11.56 (IPSOUT1-2), U11.66 (VIN_CHG), U11.67 (ELDOIN)
NRST: R99.1; also elsewhere on the board
unnamed: C86.2, D2.1 (K), FET2.2, R97.1
unnamed: C92.2, R99.2, R100.1, R102.2, U11.46 (PWROK)
unnamed: C93.2, R103.2, U11.60 (PWRON)
unnamed: C99.1, U11.29 (ALDO2)
unnamed: C101.1, U11.35 (GPIO0/LDO)
unnamed: C102.1, U11.34 (GPIO1/LDO)
unnamed: C94.1, C95.1, C107.1, L9.1, R109.1, T1.1 (D), T1.2 (D1), T1.5 (D2), T1.6 (D3), T1.7 (D4), U11.63 (LOADSENSEP)
unnamed: C109.2, U11.18 (SWOUT)
unnamed: C122.2, U11.16 (DLDO2)
unnamed: C126.2, U11.68 (ELDO1)
unnamed: C127.2, U11.1 (ELDO2)
unnamed: C128.2, U11.2 (ELDO3)
unnamed: C130.2, U11.3 (FLDO1)
unnamed: C131.2, U11.5 (FLDO2)
unnamed: C132.2, R112.2, U11.50 (VINT)
unnamed: C133.2, U11.33 (VREF)
unnamed: C158.1, U1.P6 (VREF+), VREF1.2
unnamed: C163.1, U1.AB17 (VDDA1V1_REG)
unnamed: C164.1, C165.1, U1.AB12 (VDDA1V8_REG), U1.B14 (VDDA1V8_DSI)
unnamed: C166.1, U1.A18 (VDD1V2_DSI_PHY), U1.B18 (VDD1V2_DSI_REG)
unnamed: CHGLED1.1 (K), R104.2
unnamed: D2.2 (A), L8.2, U10.1 (LX)
unnamed: L9.2, U11.65 (LX_CHG)
unnamed: L10.1, U11.21 (LX1)
unnamed: L11.1, U11.36 (LX3-1), U11.37 (LX3-2)
unnamed: L12.1, U11.23 (LX4)
unnamed: L13.1, U11.7 (LX5)
unnamed: PWRLED1.2 (A), R101.2
unnamed: PWRON1.2, R103.1
unnamed: R97.2, R98.1, U10.3 (FB)
unnamed: R102.1, RESET1.2
unnamed: R104.1, U11.53 (CHGLED)
unnamed: R105.1, U11.30 (TS)
unnamed: R106.1, U11.61 (IRQ)
unnamed: R107.1, U11.26 (DP)
unnamed: R108.1, U11.27 (DM)
unnamed: R113.1, U1.AA12 (BYPASS_REG1V8)
unnamed: T1.3 (G), U11.52 (N_BATDRV)
USB-OTG-DRV: U11.51 (N_VBUSEN); also elsewhere on the board
USB_OTG_FS_DM: R108.2; also elsewhere on the board
USB_OTG_FS_DP: R107.2; also elsewhere on the board
VBAT: C87.2, C107.2, LIPO_BAT1.1, R109.2, U11.64 (BATSENSEN)
VDD: C121.2, C147.1, C148.1, C149.1, C150.1, C151.1, C152.1, C153.1, C154.1, C155.1, C159.1, C160.1, C161.1, C162.1, R100.2, U1.A14 (VDD_DSI), U1.D18 (VDD_PLL2), U1.M6 (VDD_PLL), U1.M9 (VDD), U1.N5 (VDD_ANA), U1.N8 (VDD1), U1.N10 (VDD2), U1.P9 (VDD3), U1.P11 (VDD5), U1.R10 (VDD6), U1.R12 (VDD7), U1.T13 (VDD8), U1.U9 (VDD4(OTP)), U1.U12 (VDD9), U1.U14 (VDD10), U11.17 (DLDO1), VDD1.1; also elsewhere on the board
VDDA: C98.1, C157.1, U1.R5 (VDDA), U11.28 (ALDO1), VDDA1.1, VREF1.1
VDD_USB: C100.1, C167.1, U1.AB13 (VDD3V3_USBHS), U1.AB16 (VDD3V3_USBFS), U11.31 (ALDO3), VDD_USB1.1
VTT_DDR: C115.2, L12.2, U11.24 (DCDC4); also elsewhere on the board

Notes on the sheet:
Power Supply
Vout=0.6*(1+Ra/Rb)
LI-ION_BATTERY 4.2V
+5VDC ONLY!!!
DC5SET DDR3-VCC Floating 1.24V GND 1.50V VINT 1.36V
3.3V
VDDCORE 1.2V
Vtt_DDR 0.675V
VDDDDR 1.35V
VDD(IO)
1.8V EMMC
2.8V
VDDA
VDD3.3V_USB

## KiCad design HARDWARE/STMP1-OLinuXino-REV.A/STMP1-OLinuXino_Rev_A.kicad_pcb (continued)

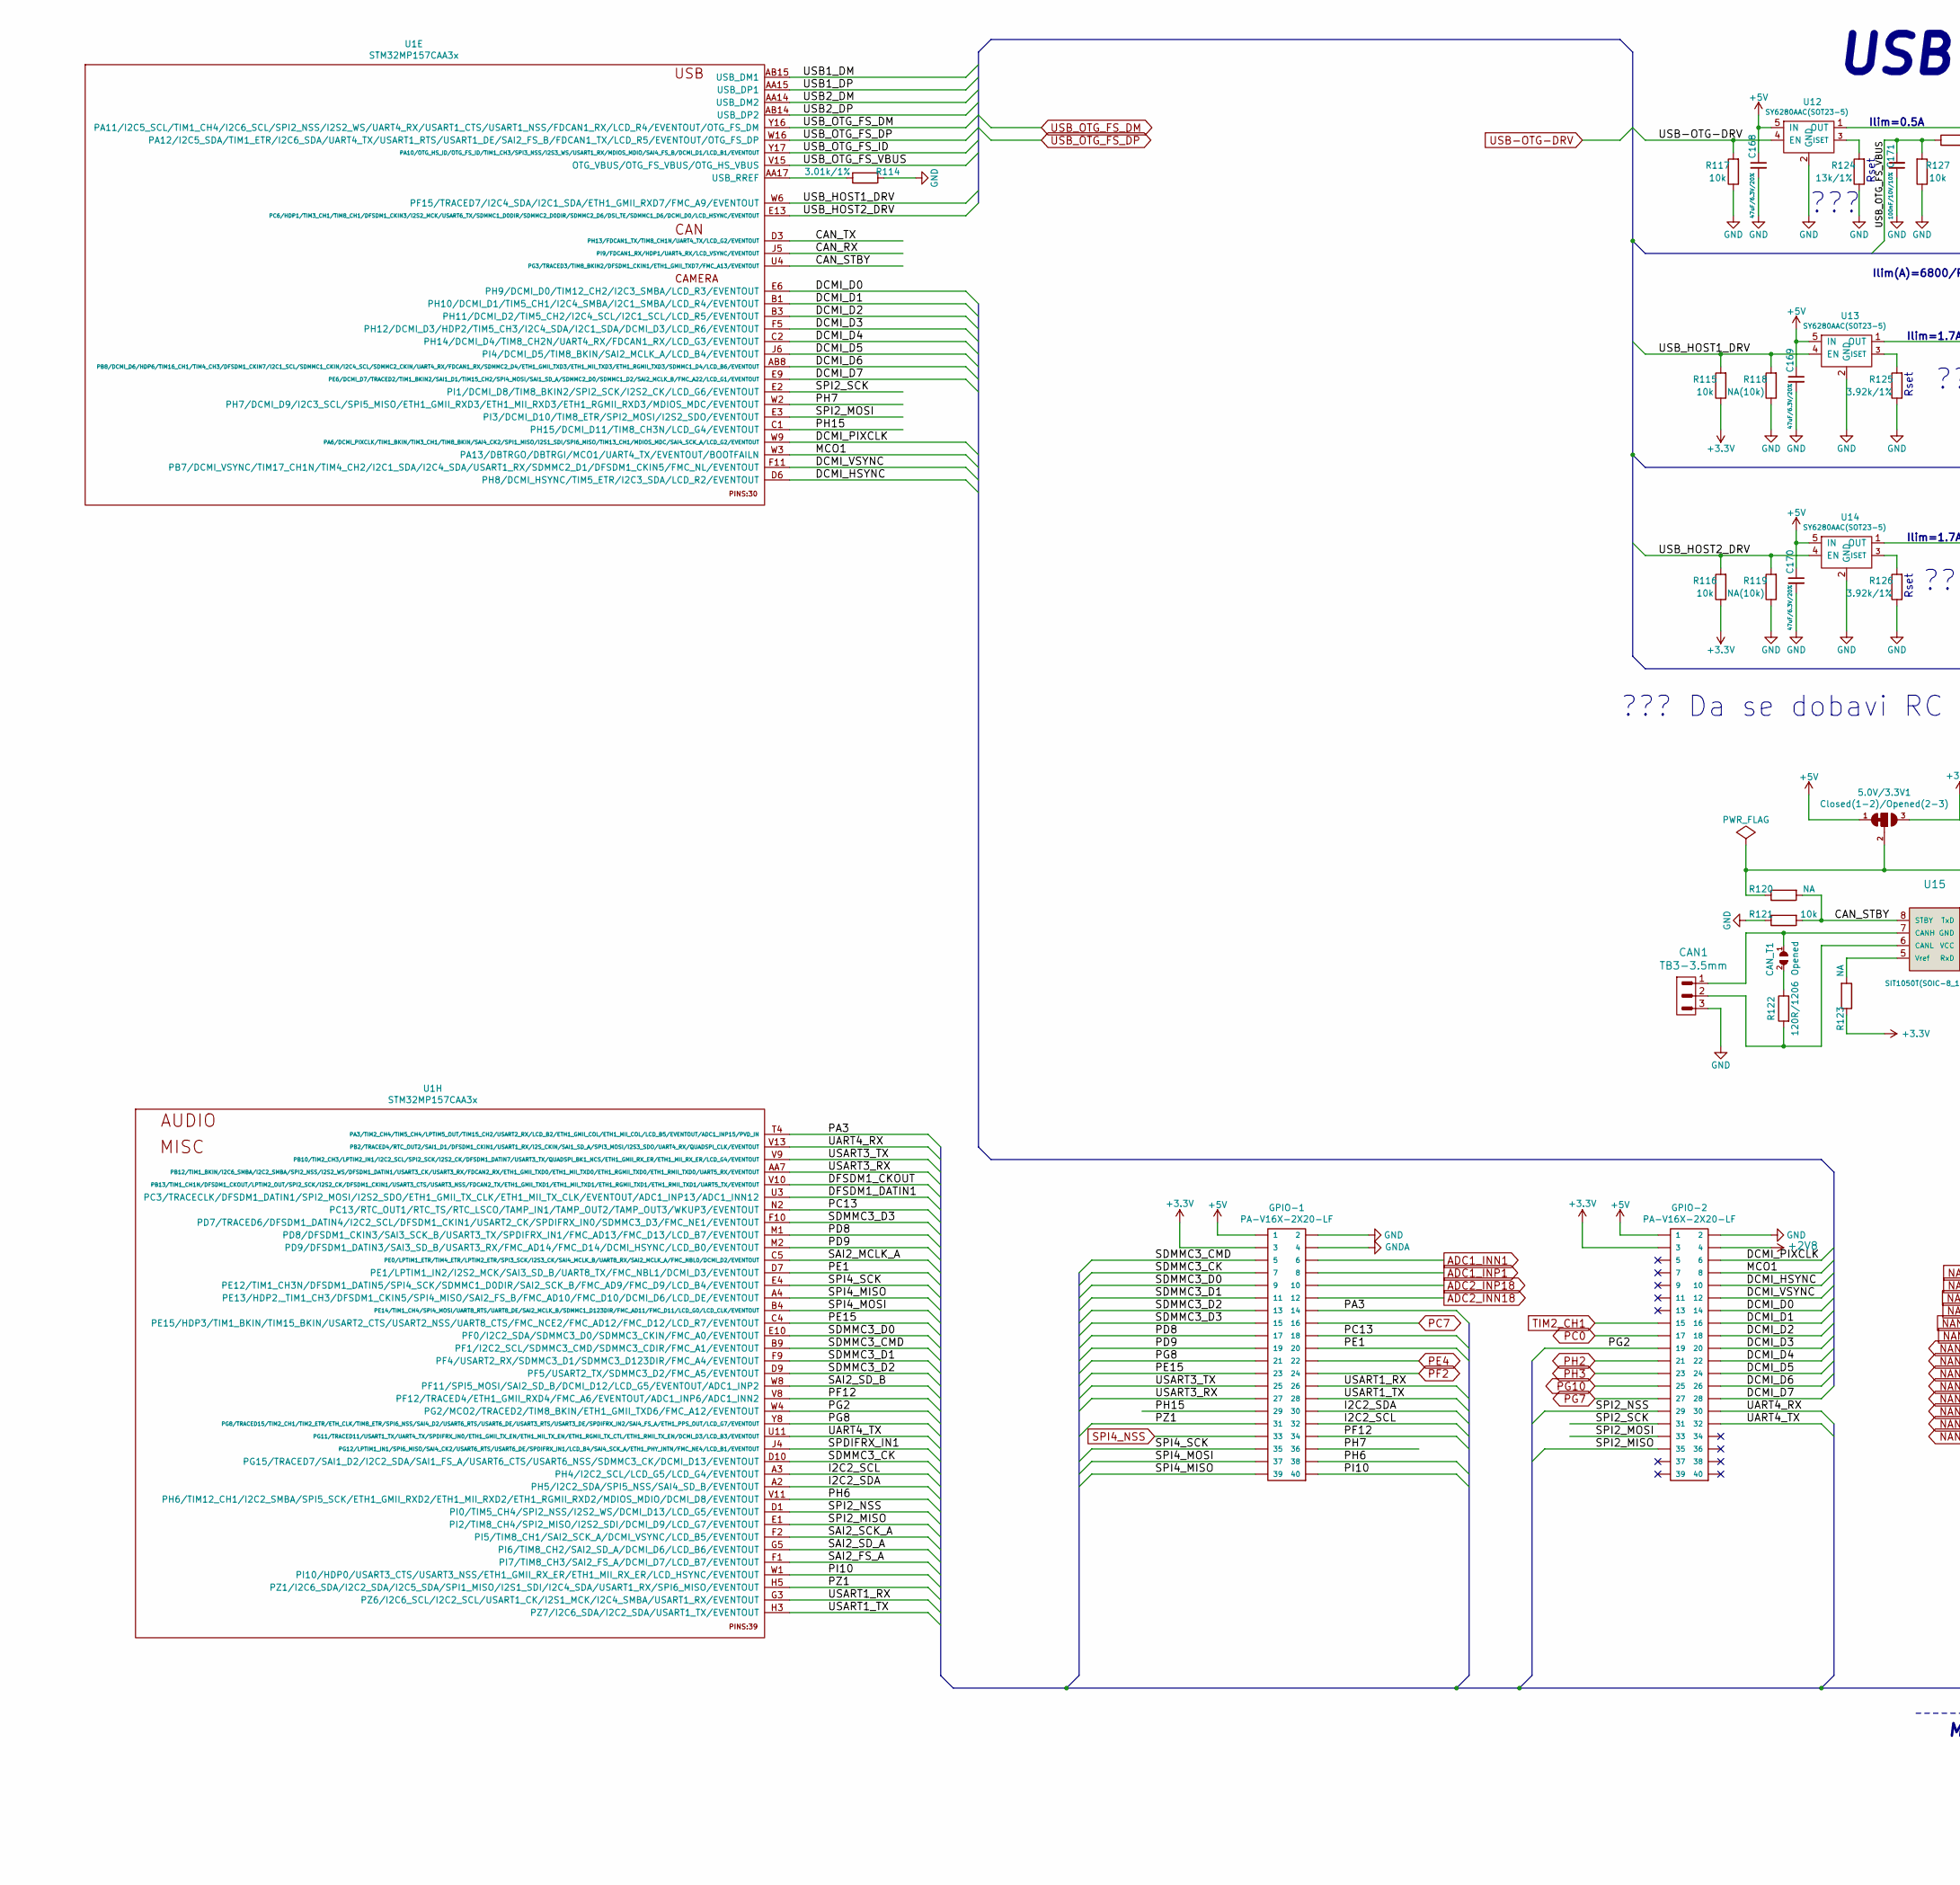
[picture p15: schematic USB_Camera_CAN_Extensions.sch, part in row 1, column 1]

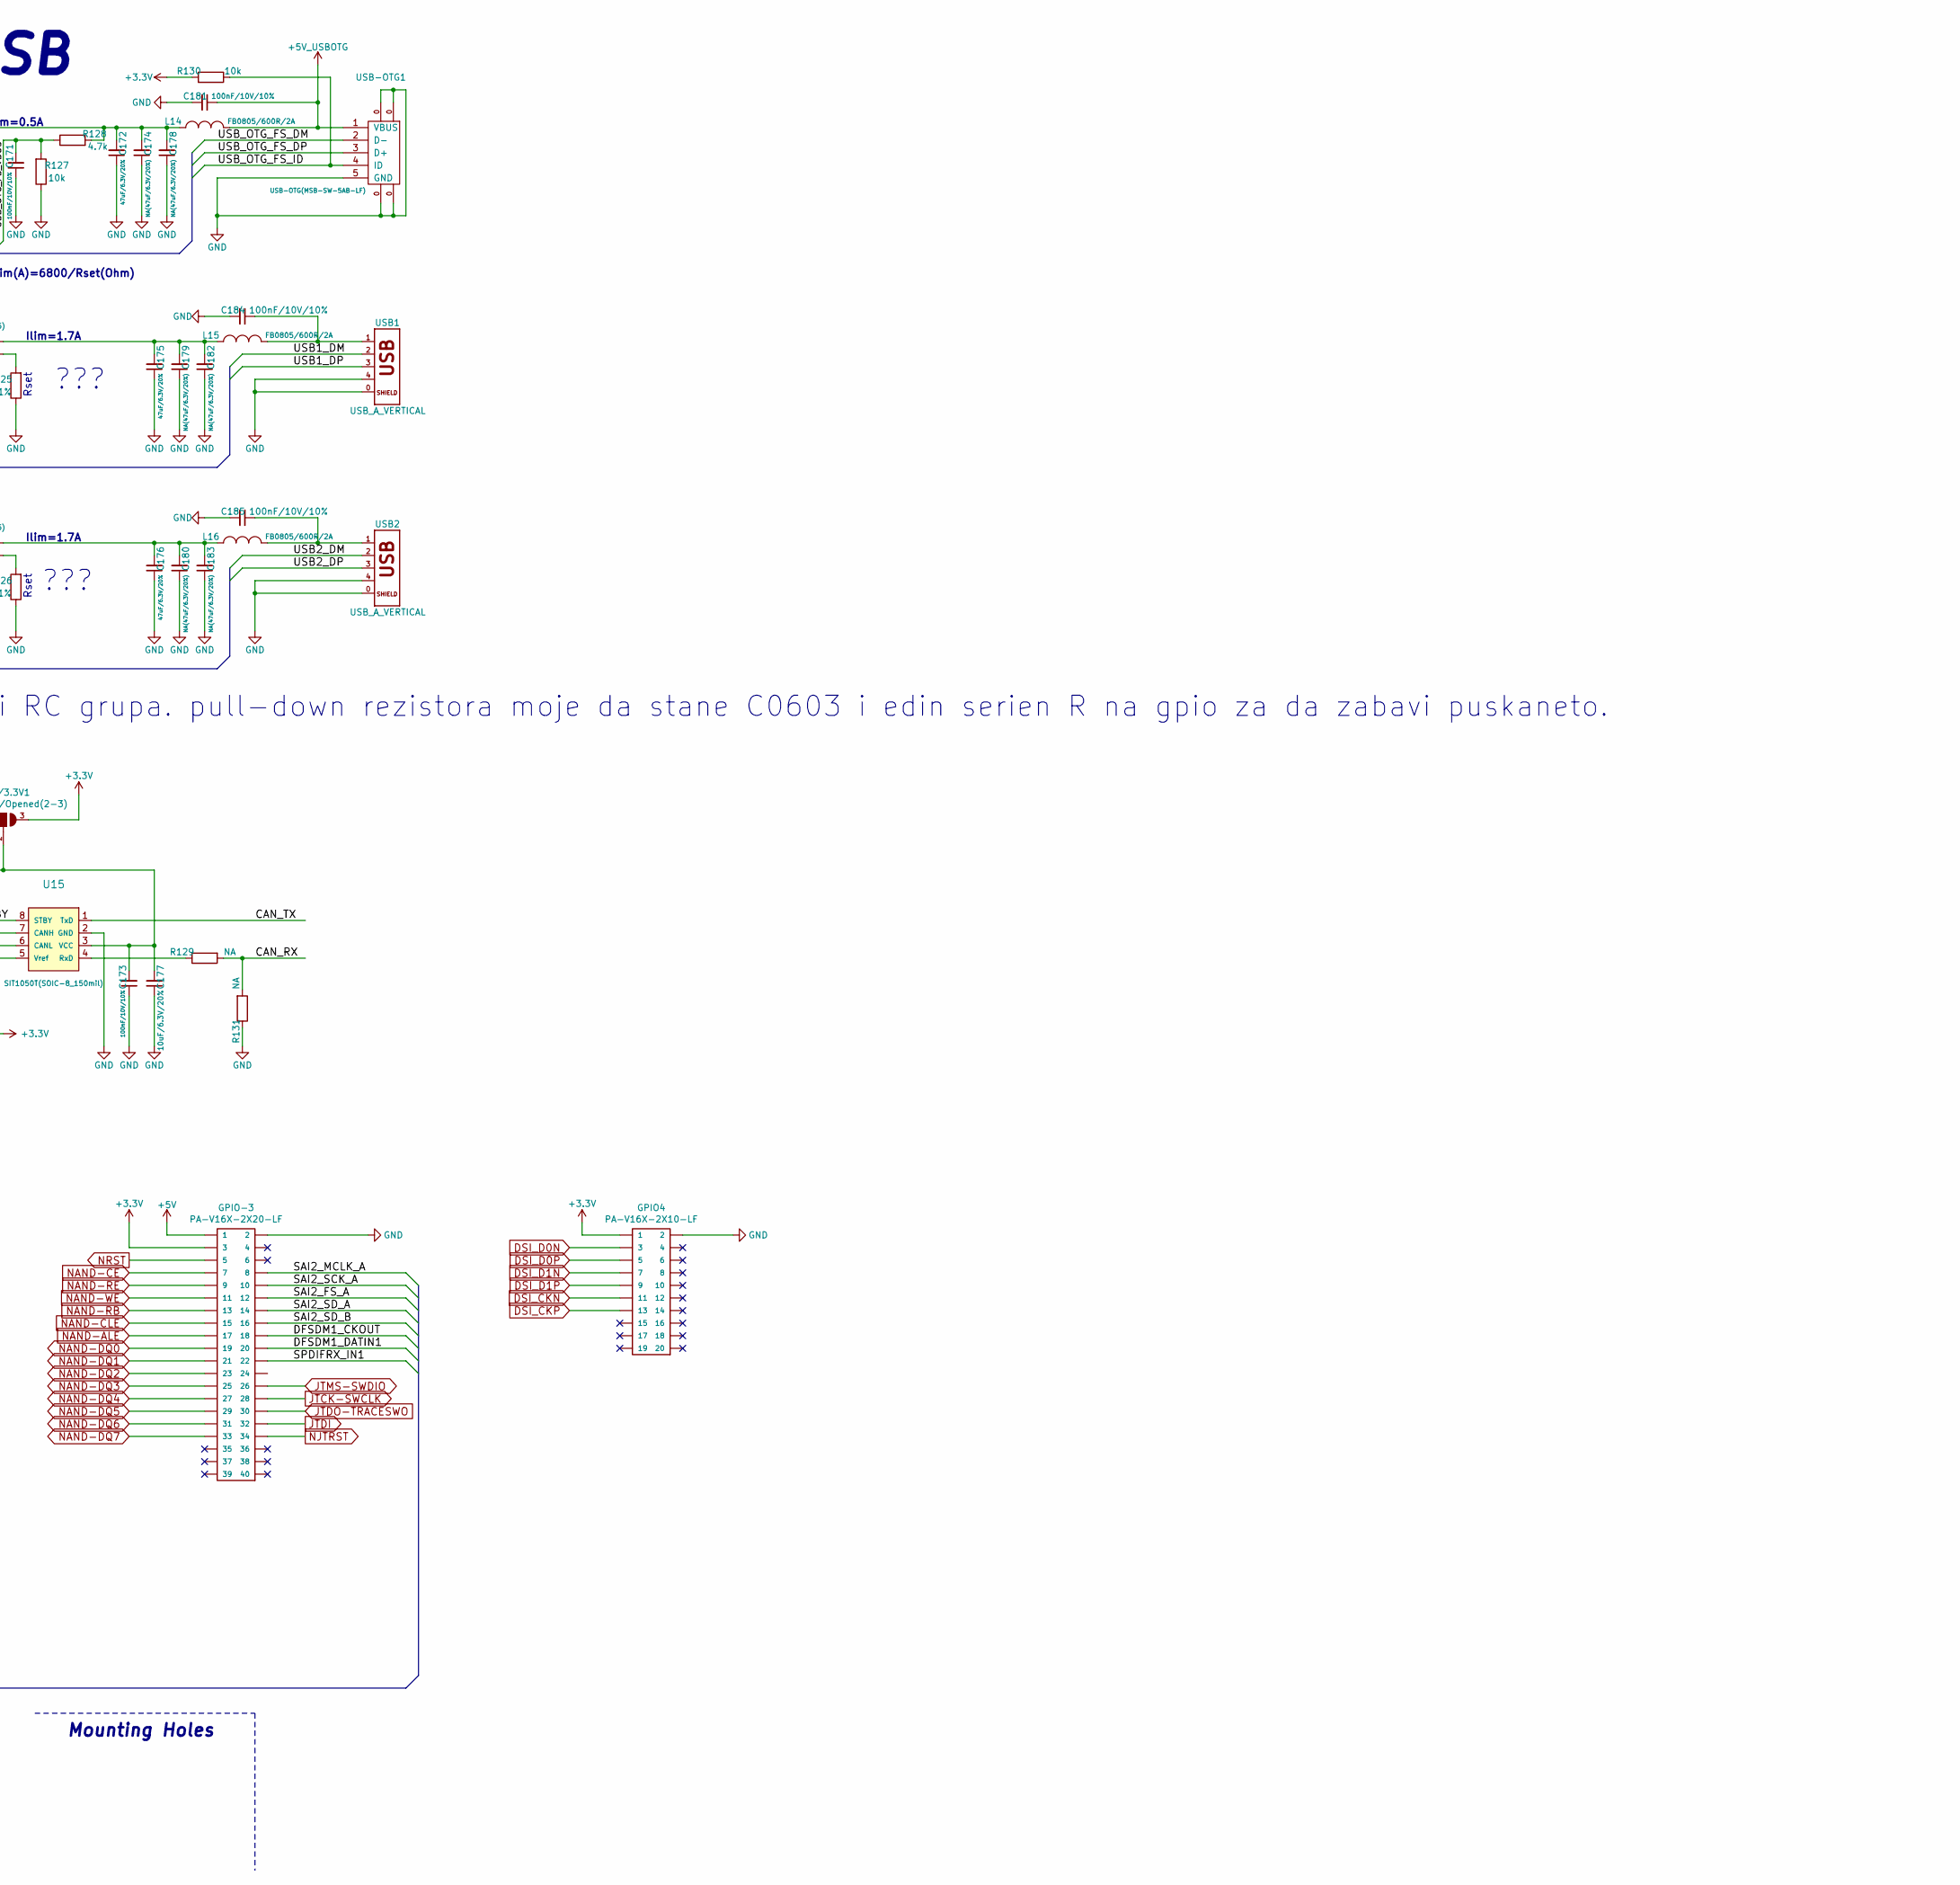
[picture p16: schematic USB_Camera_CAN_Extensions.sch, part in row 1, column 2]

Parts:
5.0V/3.3V1: Closed(1-2)/Opened(2-3); SJ_2_SMALL_12_TIED
C168, C169, C170, C172, C175, C176: 47uF/6.3V/20%; C_0805_5MIL_DWS
C171, C173, C181, C184, C185: 100nF/10V/10%; C_0402_5MIL_DWS
C174, C178, C179, C180, C182, C183: NA(47uF/6.3V/20%); C_0805_5MIL_DWS
C177: 10uF/6.3V/20%; C_0603_5MIL_DWS
CAN1: TB3-3.5mm
CAN_T1: Opened; SJ_1_SMALLER
GPIO4: PA-V16X-2X10-LF; GPH127SMT-02X10(PA-V16X-2X10-LF)
GPIO-1, GPIO-2, GPIO-3: PA-V16X-2X20-LF; GPH127SMT-02X20(PA-V16X-2X20-LF)
L14, L15, L16: FB0805/600R/2A; L_0805_5MIL_DWS
R114: 3.01k/1%; R_0402_5MIL_DWS
R115, R116, R117, R121, R127, R130: 10k; R_0402_5MIL_DWS
R118, R119: NA(10k); R_0402_5MIL_DWS
R120, R123, R129, R131: NA; R_0402_5MIL_DWS
R122: 120R/1206; R_1206_5MIL_DWS
R124: 13k/1%; R_0402_5MIL_DWS
R125, R126: 3.92k/1%; R_0402_5MIL_DWS
R128: 4.7k; R_0402_5MIL_DWS
U1: STM32MP157CAA3x; LFBGA-448(Pitch-0.8mm_Pad-0.4mm_18x18x1.27mm)
U12, U13, U14: SY6280AAC(SOT23-5); SOT-23-5
U15: SIT1050T(SOIC-8_150mil); SOIC-8_150mil
USB1, USB2: USB_A_VERTICAL; USB_A_VERTICAL_PTH
USB-OTG1: USB-OTG(MSB-SW-5AB-LF); USB_MINI_9PIN

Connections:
+2V8: GPIO-2.4; also elsewhere on the board
+3V3: 5.0V/3.3V1.3, GPIO4.1, GPIO-1.3, GPIO-2.3, GPIO-3.3, R115.1, R116.1, R123.1, R130.2; also elsewhere on the board
+5V: 5.0V/3.3V1.1, C168.1, C169.1, C170.1, GPIO-1.1, GPIO-2.1, GPIO-3.1, U12.5 (IN), U13.5 (IN), U14.5 (IN); also elsewhere on the board
+5V_USBOTG: C181.1, L14.2, USB-OTG1.1 (VBUS); also elsewhere on the board
/USB_Camera_CAN_Extensions/CAN_RX: R129.2, R131.2, U1.J5 (PI9/FDCAN1_RX/HDP1/UART4_RX/LCD_VSYNC/E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)
/USB_Camera_CAN_Extensions/CAN_STBY: R120.2, R121.2, U1.U4 (PG3/TRACED3/TIM8_BKIN2/DFSDM1_CKIN1/ETH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), U15.8 (STBY)
/USB_Camera_CAN_Extensions/CAN_TX: U1.D3 (PH13/FDCAN1_TX/TIM8_CH1N/UART4_TX/LCD_G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), U15.1 (TxD)
/USB_Camera_CAN_Extensions/DCMI_D0: GPIO-2.14, U1.E6 (PH9/DCMI_D0/TIM12_CH2/I2C3_SMBA/LCD_R3/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)
/USB_Camera_CAN_Extensions/DCMI_D1: GPIO-2.16, U1.B1 (PH10/DCMI_D1/TIM5_CH1/I2C4_SMBA/I2C1_SM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)
/USB_Camera_CAN_Extensions/DCMI_D2: GPIO-2.18, U1.B3 (PH11/DCMI_D2/TIM5_CH2/I2C4_SCL/I2C1_SCL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)
/USB_Camera_CAN_Extensions/DCMI_D3: GPIO-2.20, U1.F5 (PH12/DCMI_D3/HDP2/TIM5_CH3/I2C4_SDA/I2C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)
/USB_Camera_CAN_Extensions/DCMI_D4: GPIO-2.22, U1.C2 (PH14/DCMI_D4/TIM8_CH2N/UART4_RX/FDCAN1_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)
/USB_Camera_CAN_Extensions/DCMI_D5: GPIO-2.24, U1.J6 (PI4/DCMI_D5/TIM8_BKIN/SAI2_MCLK_A/LCD_B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)
/USB_Camera_CAN_Extensions/DCMI_D6: GPIO-2.26, U1.AB8 (PB8/DCMI_D6/HDP6/TIM16_CH1/TIM4_CH3/DFS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)
/USB_Camera_CAN_Extensions/DCMI_D7: GPIO-2.28, U1.E9 (PE6/DCMI_D7/TRACED2/TIM1_BKIN2/SAI1_D1/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)
/USB_Camera_CAN_Extensions/DCMI_HSYNC: GPIO-2.10, U1.D6 (PH8/DCMI_HSYNC/TIM5_ETR/I2C3_SDA/LCD_R2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)
/USB_Camera_CAN_Extensions/DCMI_PIXCLK: GPIO-2.6, U1.W9 (PA6/DCMI_PIXCLK/TIM1_BKIN/TIM3_CH1/TIM8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)
/USB_Camera_CAN_Extensions/DCMI_VSYNC: GPIO-2.12, U1.F11 (PB7/DCMI_VSYNC/TIM17_CH1N/TIM4_CH2/I2C1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)
/USB_Camera_CAN_Extensions/DFSDM1_CKOUT: GPIO-3.18, U1.V10 (PB13/TIM1_CH1N/DFSDM1_CKOUT/LPTIM2_OUT/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)
/USB_Camera_CAN_Extensions/DFSDM1_DATIN1: GPIO-3.20, U1.U3 (PC3/TRACECLK/DFSDM1_DATIN1/SPI2_MOSI/I2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)
/USB_Camera_CAN_Extensions/I2C2_SCL: GPIO-1.32, U1.A3 (PH4/I2C2_SCL/LCD_G5/LCD_G4/EVENTOUT)
/USB_Camera_CAN_Extensions/I2C2_SDA: GPIO-1.30, U1.A2 (PH5/I2C2_SDA/SPI5_NSS/SAI4_SD_B/EVENTOUT)
/USB_Camera_CAN_Extensions/MCO1: GPIO-2.8, U1.W3 (PA13/DBTRGO/DBTRGI/MCO1/UART4_TX/EVENTO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)
/USB_Camera_CAN_Extensions/PA3: GPIO-1.14, U1.T4 (PA3/TIM2_CH4/TIM5_CH4/LPTIM5_OUT/TIM15_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)
/USB_Camera_CAN_Extensions/PC13: GPIO-1.18, U1.N2 (PC13/RTC_OUT1/RTC_TS/RTC_LSCO/TAMP_IN1/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)
/USB_Camera_CAN_Extensions/PD8: GPIO-1.17, U1.M1 (PD8/DFSDM1_CKIN3/SAI3_SCK_B/USART3_TX/S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)
/USB_Camera_CAN_Extensions/PD9: GPIO-1.19, U1.M2 (PD9/DFSDM1_DATIN3/SAI3_SD_B/USART3_RX/F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)
/USB_Camera_CAN_Extensions/PE1: GPIO-1.20, U1.D7 (PE1/LPTIM1_IN2/I2S2_MCK/SAI3_SD_B/UART8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)
/USB_Camera_CAN_Extensions/PE15: GPIO-1.23, U1.C4 (PE15/HDP3/TIM1_BKIN/TIM15_BKIN/USART2_C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)
/USB_Camera_CAN_Extensions/PF12: GPIO-1.34, U1.V8 (PF12/TRACED4/ETH1_GMII_RXD4/FMC_A6/EVEN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)
/USB_Camera_CAN_Extensions/PG2: GPIO-2.19, U1.W4 (PG2/MCO2/TRACED2/TIM8_BKIN/ETH1_GMII_TX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)
/USB_Camera_CAN_Extensions/PG8: GPIO-1.21, U1.Y8 (PG8/TRACED15/TIM2_CH1/TIM2_ETR/ETH_CLK/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)
/USB_Camera_CAN_Extensions/PH6: GPIO-1.38, U1.V11 (PH6/TIM12_CH1/I2C2_SMBA/SPI5_SCK/ETH1_G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)
/USB_Camera_CAN_Extensions/PH7: GPIO-1.36, U1.W2 (PH7/DCMI_D9/I2C3_SCL/SPI5_MISO/ETH1_GMI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)
/USB_Camera_CAN_Extensions/PH15: GPIO-1.29, U1.C1 (PH15/DCMI_D11/TIM8_CH3N/LCD_G4/EVENTOUT)
/USB_Camera_CAN_Extensions/PI10: GPIO-1.40, U1.W1 (PI10/HDP0/USART3_CTS/USART3_NSS/ETH1_GM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)
/USB_Camera_CAN_Extensions/PZ1: GPIO-1.31, U1.H5 (PZ1/I2C6_SDA/I2C2_SDA/I2C5_SDA/SPI1_MIS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)
/USB_Camera_CAN_Extensions/SAI2_FS_A: GPIO-3.12, U1.F1 (PI7/TIM8_CH3/SAI2_FS_A/DCMI_D7/LCD_B7/E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)
/USB_Camera_CAN_Extensions/SAI2_MCLK_A: GPIO-3.8, U1.C5 (PE0/LPTIM1_ETR/TIM4_ETR/LPTIM2_ETR/SPI3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)
/USB_Camera_CAN_Extensions/SAI2_SCK_A: GPIO-3.10, U1.F2 (PI5/TIM8_CH1/SAI2_SCK_A/DCMI_VSYNC/LCD_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)
/USB_Camera_CAN_Extensions/SAI2_SD_A: GPIO-3.14, U1.G5 (PI6/TIM8_CH2/SAI2_SD_A/DCMI_D6/LCD_B6/E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)
/USB_Camera_CAN_Extensions/SAI2_SD_B: GPIO-3.16, U1.W8 (PF11/SPI5_MOSI/SAI2_SD_B/DCMI_D12/LCD_G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)
/USB_Camera_CAN_Extensions/SDMMC3_CK: GPIO-1.7, U1.D10 (PG15/TRACED7/SAI1_D2/I2C2_SDA/SAI1_FS_A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)
/USB_Camera_CAN_Extensions/SDMMC3_CMD: GPIO-1.5, U1.B9 (PF1/I2C2_SCL/SDMMC3_CMD/SDMMC3_CDIR/FMC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)
/USB_Camera_CAN_Extensions/SDMMC3_D0: GPIO-1.9, U1.E10 (PF0/I2C2_SDA/SDMMC3_D0/SDMMC3_CKIN/FMC_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)
/USB_Camera_CAN_Extensions/SDMMC3_D1: GPIO-1.11, U1.F9 (PF4/USART2_RX/SDMMC3_D1/SDMMC3_D123DIR/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)
/USB_Camera_CAN_Extensions/SDMMC3_D2: GPIO-1.13, U1.D9 (PF5/USART2_TX/SDMMC3_D2/FMC_A5/EVENTOUT)
/USB_Camera_CAN_Extensions/SDMMC3_D3: GPIO-1.15, U1.F10 (PD7/TRACED6/DFSDM1_DATIN4/I2C2_SCL/DFSD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)
/USB_Camera_CAN_Extensions/SPDIFRX_IN1: GPIO-3.22, U1.J4 (PG12/LPTIM1_IN1/SPI6_MISO/SAI4_CK2/USAR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)
/USB_Camera_CAN_Extensions/SPI2_MISO: GPIO-2.35, U1.E1 (PI2/TIM8_CH4/SPI2_MISO/I2S2_SDI/DCMI_D9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)
/USB_Camera_CAN_Extensions/SPI2_MOSI: GPIO-2.33, U1.E3 (PI3/DCMI_D10/TIM8_ETR/SPI2_MOSI/I2S2_SD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)
/USB_Camera_CAN_Extensions/SPI2_NSS: GPIO-2.29, U1.D1 (PI0/TIM5_CH4/SPI2_NSS/I2S2_WS/DCMI_D13/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)
/USB_Camera_CAN_Extensions/SPI2_SCK: GPIO-2.31, U1.E2 (PI1/DCMI_D8/TIM8_BKIN2/SPI2_SCK/I2S2_CK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)
/USB_Camera_CAN_Extensions/SPI4_MISO: GPIO-1.39, U1.A4 (PE13/HDP2,_TIM1_CH3/DFSDM1_CKIN5/SPI4_M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)
/USB_Camera_CAN_Extensions/SPI4_MOSI: GPIO-1.37, U1.B4 (PE14/TIM1_CH4/SPI4_MOSI/UART8_RTS/UART8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)
/USB_Camera_CAN_Extensions/SPI4_SCK: GPIO-1.35, U1.E4 (PE12/TIM1_CH3N/DFSDM1_DATIN5/SPI4_SCK/S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)
/USB_Camera_CAN_Extensions/UART4_RX: GPIO-2.30, U1.V13 (PB2/TRACED4/RTC_OUT2/SAI1_D1/DFSDM1_CKI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)
/USB_Camera_CAN_Extensions/UART4_TX: GPIO-2.32, U1.U11 (PG11/TRACED11/USART1_TX/UART4_TX/SPDIFR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)
/USB_Camera_CAN_Extensions/USART1_RX: GPIO-1.26, U1.G3 (PZ6/I2C6_SCL/I2C2_SCL/USART1_CK/I2S1_MC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)
/USB_Camera_CAN_Extensions/USART1_TX: GPIO-1.28, U1.H3 (PZ7/I2C6_SDA/I2C2_SDA/USART1_TX/EVENTOUT)
/USB_Camera_CAN_Extensions/USART3_RX: GPIO-1.27, U1.AA7 (PB12/TIM1_BKIN/I2C6_SMBA/I2C2_SMBA/SPI2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)
/USB_Camera_CAN_Extensions/USART3_TX: GPIO-1.25, U1.V9 (PB10/TIM2_CH3/LPTIM2_IN1/I2C2_SCL/SPI2_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)
/USB_Camera_CAN_Extensions/USB1_DM: U1.AB15 (USB_DM1), USB1.2
/USB_Camera_CAN_Extensions/USB1_DP: U1.AA15 (USB_DP1), USB1.3
/USB_Camera_CAN_Extensions/USB2_DM: U1.AA14 (USB_DM2), USB2.2
/USB_Camera_CAN_Extensions/USB2_DP: U1.AB14 (USB_DP2), USB2.3
/USB_Camera_CAN_Extensions/USB_HOST1_DRV: R115.2, R118.2, U1.W6 (PF15/TRACED7/I2C4_SDA/I2C1_SDA/ETH1_GMI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), U13.4 (EN)
/USB_Camera_CAN_Extensions/USB_HOST2_DRV: R116.2, R119.2, U1.E13 (PC6/HDP1/TIM3_CH1/TIM8_CH1/DFSDM1_CKIN3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), U14.4 (EN)
/USB_Camera_CAN_Extensions/USB_OTG_FS_ID: R130.1, U1.Y17 (PA10/OTG_HS_ID/OTG_FS_ID/TIM1_CH3/SPI3_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), USB-OTG1.4 (ID)
/USB_Camera_CAN_Extensions/USB_OTG_FS_VBUS: C171.2, R127.2, R128.1, U1.V15 (OTG_VBUS/OTG_FS_VBUS/OTG_HS_VBUS)
ADC1_INN1: GPIO-1.6; also elsewhere on the board
ADC1_INP1: GPIO-1.8; also elsewhere on the board
ADC2_INN18: GPIO-1.12; also elsewhere on the board
ADC2_INP18: GPIO-1.10; also elsewhere on the board
DSI_CKN: GPIO4.11; also elsewhere on the board
DSI_CKP: GPIO4.13; also elsewhere on the board
DSI_D0N: GPIO4.3; also elsewhere on the board
DSI_D0P: GPIO4.5; also elsewhere on the board
DSI_D1N: GPIO4.7; also elsewhere on the board
DSI_D1P: GPIO4.9; also elsewhere on the board
GND: C168.2, C169.2, C170.2, C171.1, C172.1, C173.1, C174.1, C175.1, C176.1, C177.1, C178.1, C179.1, C180.1, C181.2, C182.1, C183.1, C184.2, C185.2, CAN1.3, GPIO4.2, GPIO-1.2, GPIO-2.2, GPIO-3.2, R114.1, R117.1, R118.1, R119.1, R121.1, R124.1, R125.1, R126.1, R127.1, R131.1, U12.2 (GND), U13.2 (GND), U14.2 (GND), U15.2 (GND), USB1.0 (5), USB1.4, USB2.0 (5), USB2.4, USB-OTG1.0, USB-OTG1.5 (GND); also elsewhere on the board
GNDA: GPIO-1.4; also elsewhere on the board
JTCK-SWCLK: GPIO-3.28; also elsewhere on the board
JTDI: GPIO-3.32; also elsewhere on the board
JTDO-TRACESWO: GPIO-3.30; also elsewhere on the board
JTMS-SWDIO: GPIO-3.26; also elsewhere on the board
NAND-ALE: GPIO-3.17; also elsewhere on the board
NAND-CE: GPIO-3.7; also elsewhere on the board
NAND-CLE: GPIO-3.15; also elsewhere on the board
NAND-DQ0: GPIO-3.19; also elsewhere on the board
NAND-DQ1: GPIO-3.21; also elsewhere on the board
NAND-DQ2: GPIO-3.23; also elsewhere on the board
NAND-DQ3: GPIO-3.25; also elsewhere on the board
NAND-DQ4: GPIO-3.27; also elsewhere on the board
NAND-DQ5: GPIO-3.29; also elsewhere on the board
NAND-DQ6: GPIO-3.31; also elsewhere on the board
NAND-DQ7: GPIO-3.33; also elsewhere on the board
NAND-RB: GPIO-3.13; also elsewhere on the board
NAND-RE: GPIO-3.9; also elsewhere on the board
NAND-WE: GPIO-3.11; also elsewhere on the board
NJTRST: GPIO-3.34; also elsewhere on the board
NRST: GPIO-3.5; also elsewhere on the board
unnamed: 5.0V/3.3V1.2, C173.2, C177.2, R120.1, U15.3 (VCC)
unnamed: C172.2, C174.2, C178.2, L14.1, R128.2, U12.1 (OUT)
unnamed: C175.2, C179.2, C182.2, L15.1, U13.1 (OUT)
unnamed: C176.2, C180.2, C183.2, L16.1, U14.1 (OUT)
unnamed: C184.1, L15.2, USB1.1
unnamed: C185.1, L16.2, USB2.1
unnamed: CAN1.1, CAN_T1.1, U15.7 (CANH)
unnamed: CAN1.2, R122.2, U15.6 (CANL)
unnamed: CAN_T1.2, R122.1
unnamed: R114.2, U1.AA17 (USB_RREF)
unnamed: R123.2, U15.5 (Vref)
unnamed: R124.2, U12.3 (ISET)
unnamed: R125.2, U13.3 (ISET)
unnamed: R126.2, U14.3 (ISET)
unnamed: R129.1, U15.4 (RxD)
PC0: GPIO-2.17; also elsewhere on the board
PC7: GPIO-1.16; also elsewhere on the board
PE4: GPIO-1.22; also elsewhere on the board
PF2: GPIO-1.24; also elsewhere on the board
PG7: GPIO-2.27; also elsewhere on the board
PG10: GPIO-2.25; also elsewhere on the board
PH2: GPIO-2.21; also elsewhere on the board
PH3: GPIO-2.23; also elsewhere on the board
SPI4_NSS: GPIO-1.33; also elsewhere on the board
TIM2_CH1: GPIO-2.15; also elsewhere on the board
USB-OTG-DRV: R117.2, U12.4 (EN); also elsewhere on the board
USB_OTG_FS_DM: U1.Y16 (PA11/I2C5_SCL/TIM1_CH4/I2C6_SCL/SPI2_NS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), USB-OTG1.2 (D-); also elsewhere on the board
USB_OTG_FS_DP: U1.W16 (PA12/I2C5_SDA/TIM1_ETR/I2C6_SDA/UART4_T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), USB-OTG1.3 (D+); also elsewhere on the board

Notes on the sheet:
USB
Ilim(A)=6800/Rset(Ohm)
Rset
Ilim=1.7A
Ilim=0.5A
???
??? Da se dobavi RC grupa. pull-down rezistora moje da stane C0603 i edin serien R na gpio za da zabavi puskaneto.
Mounting Holes

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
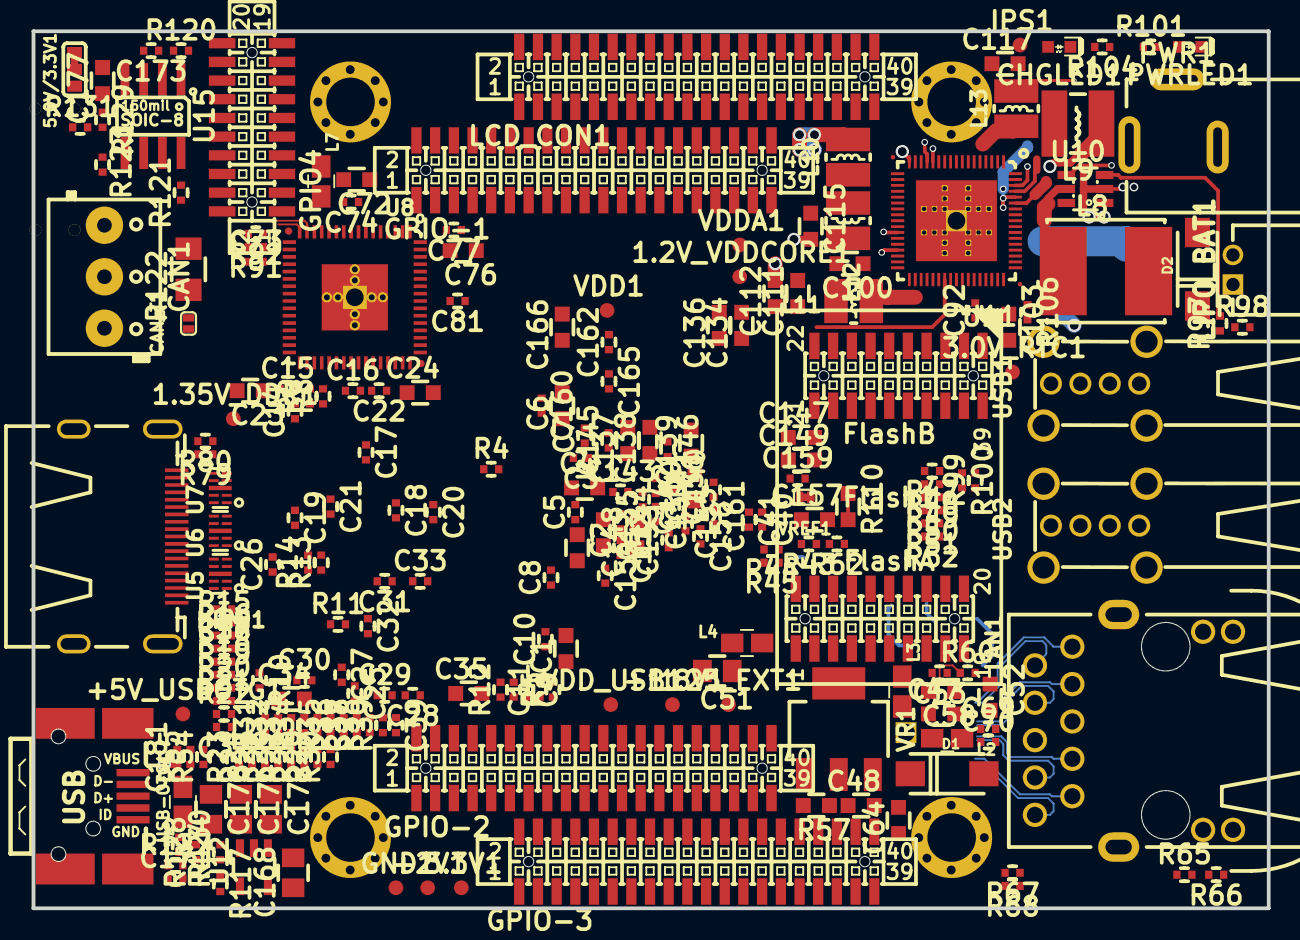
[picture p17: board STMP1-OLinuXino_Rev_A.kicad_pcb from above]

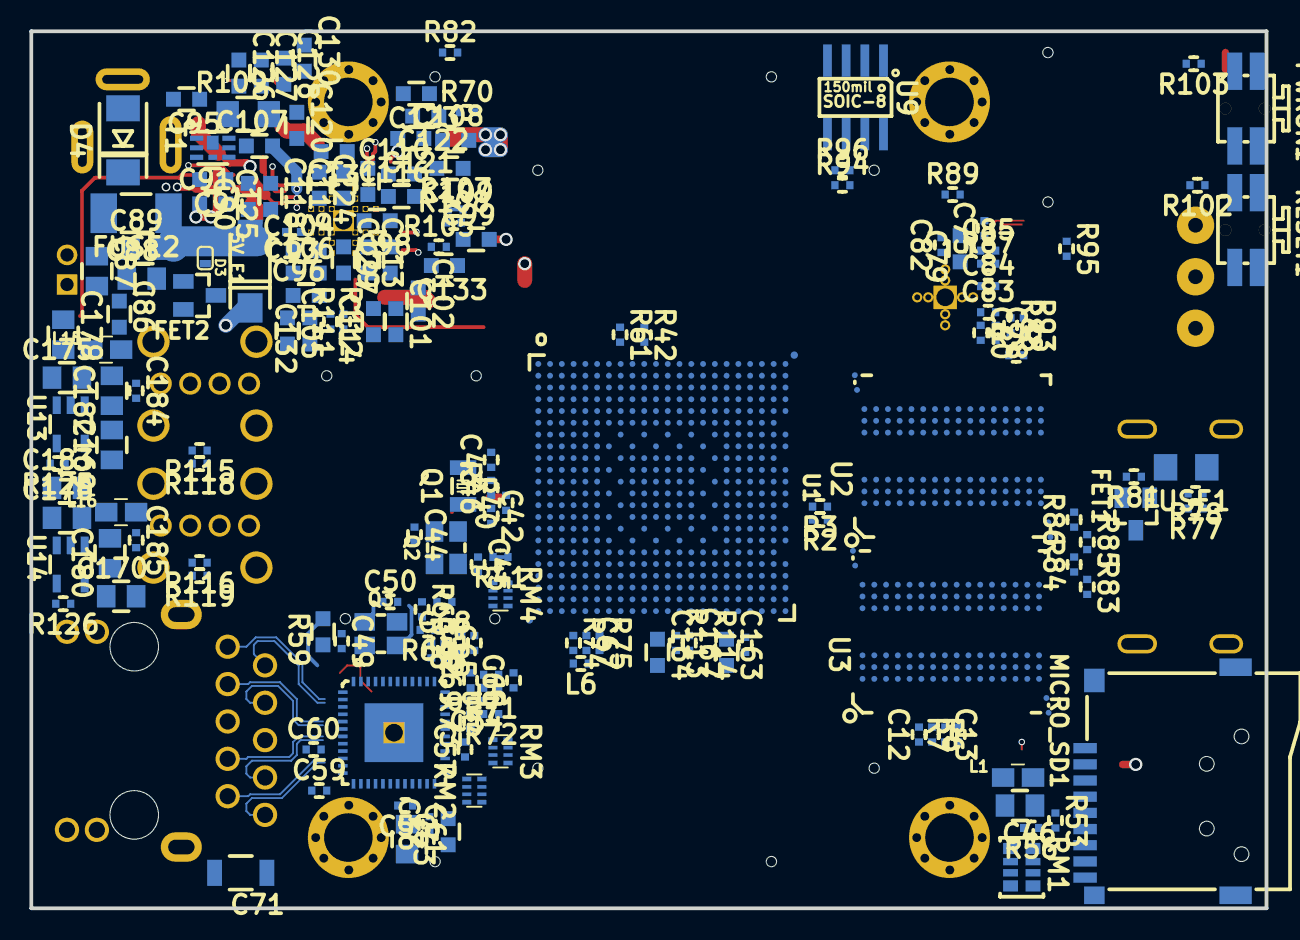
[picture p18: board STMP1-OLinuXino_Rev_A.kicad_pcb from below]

Board: 8 copper layers, 84.0 x 59.6 mm, 400 parts (170 on the bottom side), 420 nets.
